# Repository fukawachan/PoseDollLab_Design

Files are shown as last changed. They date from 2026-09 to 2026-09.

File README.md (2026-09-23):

# PoseDoll 人偶硬件设计

Manny / Quinn 传感器可动人偶的独立设计仓库。原来位于 `DollSimulation` UE 工程中的硬件、固件与硬件诊断工具已经迁入本目录；UE 插件、角色资产与完整 Python 模拟器留在原项目。

## 当前状态

本次审查同时评估用户新明确的“摆稳后采集、无需实时动捕”场景：[放宽实时指标后的优化任务](Hardware/PoseDoll44/docs/NEXT_REVIEW_STATIC_CAPTURE.zh-CN.md)。Rev O3 当前代码与封存证据保留原时序，低频/触发式架构尚待审查实施。

- **当前推进为 Rev O 第三轮**：[本轮设计、验证与剩余问题](Hardware/PoseDoll44/docs/START_HERE_REVO3.zh-CN.md)。已实现一体板托、外耳钢背摩擦件和磨损状态检查；修正载荷/质量账、时序统计与节点恢复；生成顶入/侧入板件候选。**整机 1.2 kg 已改为非强制偏好**，尺寸、手感和精度要求保留。完整多轴总装与制造门槛尚未闭合。[第三轮审查入口](Hardware/PoseDoll44/docs/REVIEW_REQUEST_REVO3.zh-CN.md)。

- **历史检查点：Rev O 第二轮**：[本轮设计、验证与缺口](Hardware/PoseDoll44/docs/START_HERE_REVO2.zh-CN.md)。已重构 L6 承力/装配、生成 N3/N4 拆板候选并修复入网调度；完整板位、质量目标和物理门槛仍待闭合。**[给 GPT-6 Pro 的第二轮审查说明](Hardware/PoseDoll44/docs/REVIEW_REQUEST_REVO2.zh-CN.md)** 已整理好源码、证据和重点问题。下列 Rev O 审查入口保留为第一轮历史。

- **历史检查点：Rev O Desktop 初轮**：48 cm 为研究锚点，比较 42/45 cm 及较大后备档；已交付双角色布局、三档关节、原生电气布局和七角色固件。板位、预紧和质量预算仍未达标，完整总装尚未完成。
- **约 91 cm 的 Rev M/N1 为备用**：原文件与旧输出保留，以哈希清单冻结。新旧源码、报告和导出分目录保存。
- 第一轮历史入口：[Rev O 当前结果与失败清单](Hardware/PoseDoll44/docs/START_HERE_REVO.zh-CN.md)。
- **第一轮历史独立审查入口：[给 GPT-6 Pro 的审查说明](Hardware/PoseDoll44/docs/REVIEW_REQUEST_REVO.zh-CN.md)**，包含已知失败、证据链接与下一轮修改要求。

以下为备用版的历史基线：

- **机械基线为 Rev N1**：两款分别按 UE 人物参考比例设计，参考身高约 91 cm；胸前大挡板已取消，左肩局部刮碰已修正。
- **下一项为“局部采集 + 外置电源/USB 接口盒”**：方向已确定，新电路板、安装结构和线束尚未实施。
- **小型化仍待比较**：当前尺寸不是已证明的下限，不能直接缩放现有文件，也不能认定重新设计的小型关节必然昂贵。
- 44 个协议槽中，41 轴测量，骨盆 3 轴固定参考；整体位置和全部整体旋转在 UE 调整。
- 当前交付是数字原型候选，尚未实物鉴定。

## 阅读入口

0. [当前主方案 Rev O3](Hardware/PoseDoll44/docs/START_HERE_REVO3.zh-CN.md)；使用 `scripts/run_revo3.py --run-id <唯一编号>` 复跑，`scripts/Start-Viewer.ps1 -Revision revO3` 查看。以下 Rev M/N 文档用于备用版。

1. [最新 Rev N1 设计入口](Hardware/PoseDoll44/START_HERE_REVN.zh-CN.md)
2. [胸部修订与设备外置方案](Hardware/PoseDoll44/docs/CHEST_AND_EXTERNAL_REVN.zh-CN.md)
3. [尺寸、磁铁和关节小型化评估](Hardware/PoseDoll44/docs/SIZE_REVIEW_BEFORE_EXTERNAL.zh-CN.md)
4. [制造说明](Hardware/PoseDoll44/docs/FABRICATION_REVM.zh-CN.md)、[装配说明](Hardware/PoseDoll44/docs/ASSEMBLY_REVM.zh-CN.md)、[测试和校准](Hardware/PoseDoll44/docs/BUILD_AND_CALIBRATE_REVM.zh-CN.md)
5. [迁移记录和验证](docs/MIGRATION.zh-CN.md)

Rev M 文档描述原完整基线，使用时应应用 Rev N1 的取消件和左肩修订。更早版本与 `planning/` 是历史依据，不能混作当前制造说明。

## 目录组织

| 路径 | 用途 |
|---|---|
| `Hardware/PoseDoll44/cad/` | 参数化机械模型，保留当前模型仍引用的历史模块 |
| `Hardware/PoseDoll44/electronics/` | 原生 KiCad 工程、符号/封装及板级 STEP 输入 |
| `Hardware/PoseDoll44/mechanical_manifest/` | 轴、接口、比例和网络定义 |
| `Hardware/PoseDoll44/docs/`、`verification/` | 设计说明、数字检查和原型验收依据 |
| `Hardware/PoseDoll44/generated/` | 总装、打印件、查看器、交付清单和本地 CAD 缓存 |
| `Hardware/PoseDoll44/reference/`、`references/` | UE 参考数据及元件资料 |
| `Hardware/PoseDoll44/harness/` | 两款线束与下料表 |
| `Firmware/PoseDollFullBody/` | 六节点完整固件与主机端 C 核心测试 |
| `Firmware/PoseDollHardware/` | 早期单关节固件，历史用途 |
| `Tools/PoseDollHardwareBridge/` | 诊断、校准、数据转换和测试 |
| `Tools/PoseDollSimulator/`、`Shared/` | 硬件需要的协议/运动学代码及配置快照，不含模拟器 GUI |
| `planning/` | 原始规划包副本，父目录中的原下载包也保留 |
| `scripts/` | 独立仓库的检查、构建和查看器入口 |
| `.local/` | 本机迁移清单、运行结果等，不入 Git |

保留 `Hardware/`、`Firmware/`、`Tools/` 层级，以保持已有相对路径及历史资料的可追溯性。协议快照来源与逐文件哈希见 [software_snapshot.json](docs/software_snapshot.json)。

## 环境与离线检查

在本目录打开 PowerShell。本机已经建立独立 `.venv`；新克隆可执行：

```powershell
py -3.13 -m venv .venv
.\.venv\Scripts\python.exe -m pip install -r requirements.txt
.\.venv\Scripts\python.exe scripts/check_repository.py
.\scripts\Build-Design.ps1 -Stage OfflineTests
```

离线检查包括协议配置、Python 测试、C 核心测试和 C/Python 数据帧一致性；不连接硬件或操作 UE。C 测试需要 Visual Studio C 工具链，`-VcVars` 可指定 `vcvars64.bat`。本机迁移后结果为 **81 个 Python 测试、9 个 C 场景通过，数据帧逐字节一致**。

## 打开三维查看器

```powershell
.\scripts\Start-Viewer.ps1
```

默认根据 `verification/revO3/latest.json` 打开 Rev O3 查看器，当前为 `http://127.0.0.1:8874/generated/revO3/runs/o3_20260924_r3/review.html`；通过 `-Revision revN` 打开 91 cm 备用版，仅绑定本机。`-NoBrowser` 只启动服务；端口冲突时可用 `-Port` 指定另一端口，不会自动终止其他进程。

Rev O3 的当前及历史检查运行、HTML、网格、STEP、原生 KiCad 板件、固件产物与原始日志随本次审查提交收录；宿主 C 编译产物通过逐件哈希的 portable ZIP 保存。Rev O 第一轮的 HTML、轻量网格、布局数据及三档关节 STEP 也保留。十份体型布局 STEP 下载需先用 `Build-RevO.ps1 -Stage CAD` 重建。91 cm 备用查看器仍依赖未纳入 Git 的大型网格，需复制旧输出或重建。

## CAD、电路和固件

- CAD：CadQuery 2.7。现有 `Hardware/PoseDoll44/tools/run_cad.py` 可使用本机 CQ-editor 2.7 的环境，需要 CQ-editor 保持开启、Python 版本匹配；也可自行安装常规 CadQuery 环境。
- 电路：KiCad 10，打开 `electronics/` 中对应 `.kicad_pro`。搬迁前已打开的 CQ-editor/KiCad 文件，应从新目录重新打开，避免保存回原路径。
- 固件：ESP-IDF 6.1、ESP32-S3。旧构建缓存已保留，但含旧绝对路径；不要直接在其中增量构建。
- 布线工具：Freerouting 2.4.1 JAR 保留在本机 `Hardware/PoseDoll44/tools/vendor/`，不入 Git；许可证与说明保留。

```powershell
.\scripts\Build-Design.ps1 -Stage CAD
.\scripts\Build-Design.ps1 -Stage Firmware
```

CAD 阶段生成/复核 Rev M 完整基线，耗时较长。Rev N1 的修订脚本位于 `cad/revN/`，依赖 Rev M 完整输出及其复核结果，不是上述命令自动生成的另一套角色。当前源码与必要 CAD 输入纳入 Git。

新构建入口使用本仓库 `.venv`。Firmware 阶段会把检测到旧工程路径的节点缓存移入 `.local/legacy-firmware-builds/` 后重新构建，不删除缓存、不烧录。旧脚本中的 CQ-editor、KiCad、ESP-IDF 安装盘符仍是本机配置；换电脑须配置工具路径，历史工具可参考 `local_toolchain.example.json`。UE 参考重新导出需要原 UE 工程及插件，但导出脚本现在将数据写到本设计仓库。

## Git 与本地成果

Git 收录设计源码、KiCad 工程、固件、必要板级 STEP/角色参考输入、协议快照、说明、交付元数据和检查记录。`.gitattributes` 保留原行尾，避免检出时破坏来源文件的字节哈希。

大型总装 STEP、查看器大网格、CAD 缓存、ESP-IDF 构建目录、Python 环境和第三方工具二进制保留在磁盘，由 `.gitignore` 排除；没有启用 Git LFS。Rev O 审查快照额外收录三档单关节总成 STEP、两个 A 级配合样片 STEP/STL、轻量查看器与本轮原始编译/ERC/DRC 日志，Rev O3 本次另显式收录三个检查运行及其可追溯产物，仍未放开其他版本的整个生成目录。其他机器如需完整本地成果，应另外复制 `Hardware/PoseDoll44/generated/`。**推送 Git 不等于备份全部 6.87 GB 本地成果。**

现有验证报告保留为历史快照，迁移后的路径修复和检查另列记录；没有把迁移当成新一轮全身工程验证。本轮提交由使用者推送到远端；审查应指定 `design/revO-desktop-external` 分支和所读取的完整提交号。

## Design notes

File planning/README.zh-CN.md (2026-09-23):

# PoseDoll HW-44：硬件设计与 Codex 交接方案

版本：v0.1 / 2026-09-19。范围：完整 44 轴手动姿势人偶；分阶段制造、测试。

这是**工程设计任务书、接口约束和验收计划**，不是已经完成的 CAD、电路板、生产 BOM 或实测认证。文件中的尺寸、性能阈值、总线频率为待验证的设计目标。没有附上可直接投产的 STL、接线针脚图或 Gerber，避免把未经设计审查的文件误当成成品。

项目基线：`fukawachan/DollSimulation`，检查到的提交为 `7c22e075fe0efe295ce2935a8bb2a92cff0b6def`。本地继续开发前，必须检查用户当前分支与未提交修改，不能重置到这个提交。

## 阅读入口

先读 `CODEX_START_HERE.md`，然后读 `docs/HARDWARE_DESIGN.zh-CN.md`。具体软件衔接见 `docs/INTEGRATION_AND_PROTOCOL.zh-CN.md`；测试与每轮交付见 `docs/TEST_AND_RELEASE.zh-CN.md`；工具见 `docs/TOOLCHAIN.zh-CN.md`。

`contracts/axis_allocation.json` 已按照实际仓库的轴顺序分配完整 44 轴到六个区域节点。它**不是接线引脚表**；未定的针脚和实际关节限位明确为 null。

`tools/check_plan.py` 仅检查计划文件的内部一致性，也可以对本地仓库进行只读的轴顺序与基线哈希检查。其成功不代表机械强度、电路安全、传感器精度或 UE 新增硬件功能已经通过。

```powershell
python .\tools\check_plan.py
python .\tools\check_plan.py --repo "D:\YourProject\DollSimulation"
```

所有物理测试初始均为 `not_run`。先交付全身结构布局与第一轮少量试件，不直接采购全身电子元件，不自动提交 PCB 订单或启动打印机。

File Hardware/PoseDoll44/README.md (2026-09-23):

# PoseDoll Manny / Quinn hardware design

[Repository README](../../README.md) · [Rev N1 entry](START_HERE_REVN.zh-CN.md) · [Size review](docs/SIZE_REVIEW_BEFORE_EXTERNAL.zh-CN.md)

Current mechanical candidate: Rev N1 (Rev M full body, chest facade removed, left shoulder clearance corrected). Rear electronics remain integrated; local acquisition plus an external interface box is authorized but not implemented. Miniaturization feasibility and cost are unresolved.

CAD source: `cad/revM/final_model.py` plus `cad/revN/chest_clearance.py`. Historical revisions remain because current code and input provenance refer to them. Use revision manifests rather than mixing standalone exports.

This is a digital prototype candidate, not a manufacturing release or a physically qualified product. See the repository README for the migrated layout, toolchain, ignored local exports, offline checks and viewer startup.

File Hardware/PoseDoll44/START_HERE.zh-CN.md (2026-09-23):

# PoseDoll · Manny / Quinn 完整硬件设计

> **最新增量：** [Rev N1](START_HERE_REVN.zh-CN.md) 已取消胸口罩壳及其四个紧固件、修正左肩支座局部刮碰，并完成背部外置架构评估。下文为原 Rev M 配套资料，制造时以 N1 清单剔除取消件并替换左肩支座图纸；背部外置尚未实施。

当前交付是 **Rev M 完整数字原型候选**：两款角色各自的 1:2 关节比例、41 个相对测量轴、被动持姿机构、局部可拆外壳、电子仓、四种电路板、六节点固件及线束/校准文件。

**先打开 [完整人偶三维查看页](generated/revM/RevM_Full_Body_Review.html)**。若在浏览器查看，使用 [当前本地服务](http://127.0.0.1:8874/generated/revM/RevM_Full_Body_Review.html)。页面可切换 Manny / Quinn、站/坐与检查姿态、外壳、电子仓、线束固定点，并点击具体零件下载 STEP。

如果本地服务链接打不开，双击 [Open-Viewer.cmd](Open-Viewer.cmd)。它会在后台启动仅本机可访问的服务并打开页面；重启电脑后再次双击即可。不要直接双击 HTML，模型数据需要通过本地 HTTP 服务读取。

目前不需要你打印、采购、量尺寸或接线。完整设计先供复核；实物按“一个高负载关节 → 单传感器/区域板 → 单肢 → 一款整机 → 另一款”的顺序验证。数字检查与尚需补齐的证据集中在 [最终验证报告](verification/REVM_REPORT.zh-CN.md)。

## 确定的使用方式

- 两款都来自项目中的 Manny / Quinn 参考骨架与网格比例。参考高度分别约 907.93 / 907.70 mm；这是 1:2 人物参考高度，机械外壳包络不宣称逐点复制人体表面。
- 稳定躯段包壳，肩带、腰髋、肘膝、腕颈等活动区域裸露。大腿后侧、小腿后上段等压缩区留空；外壳不跨越这些运动区。
- 人偶不含固定外部支架；摆好姿势后使用外部承托，支撑物本轮不设计。
- 骨盆前方定义人偶前方。UE 中调整全部整体位置和转动；整个人偶平躺不会自动让 UE 角色平躺。相对弯腰、抬腿等动作仍由关节测量。
- 协议保留 44 个槽位，骨盆三轴明确 `fixed`、原始值为空；其余 41 轴测量。没有 IMU，不把缺失传感器伪装成零度。
- 非相邻部位接触保留为摆姿限制；同体或相邻结构穿插仍作为设计问题检查。

## 交付文件

| 内容 | Manny | Quinn |
|---|---|---|
| 整机总装 | [STEP](generated/revM/manny/Manny_RevM_assembly.step) | [STEP](generated/revM/quinn/Quinn_RevM_assembly.step) |
| 逐件 CAD / 工艺清单 | [清单 JSON](generated/revM/manny/manufacturing_manifest.json) | [清单 JSON](generated/revM/quinn/manufacturing_manifest.json) |
| 打印候选 | [187 件 STL](generated/revM/manny/print_candidates) | [187 件 STL](generated/revM/quinn/print_candidates) |
| 加工与采购分类 | [CSV](generated/revM/manny/procurement_routes.csv) | [CSV](generated/revM/quinn/procurement_routes.csv) |
| 线束裁线 / 端子表 | [CSV](harness/manny_cut_list_revM.csv) | [CSV](harness/quinn_cut_list_revM.csv) |
| 41 轴校准参考工单 | [CSV，未测](generated/revM/manny/calibration_reference_plan.csv) | [CSV，未测](generated/revM/quinn/calibration_reference_plan.csv) |

打印 STL 已做闭合性检查；每款 6 个零件另附小圆筋修正后的 `_print_process.step`，与名义总装的区别见制造说明，打印直接使用交付 STL。

两款各 1,999 个 CAD 实体，包含电子元件和重复螺丝，不代表 1,999 种采购件。每款电子部分为 **39 块小传感器板 + 2 块肩外展板 + 6 块区域板 + 1 块电源板**。加工/采购分类表把焊接元件归入 PCBA，不重复采购。

- [39 块小传感器板 KiCad](generated/revM/electronics/sensor_revM_side/PoseDoll_AS5048A_revM_side.kicad_pro)
- [2 块肩外展传感器板 KiCad](generated/revM/electronics/sensor_revM_large_sh/PoseDoll_AS5048A_revM_large_sh.kicad_pro)
- [区域板 KiCad](generated/revM/electronics/regional_revM/PoseDoll_PD41_Regional_revM.kicad_pro)
- [电源板 KiCad](generated/revM/electronics/power_revM/PoseDoll_PD41_Power_revM.kicad_pro)
- [六节点固件镜像](generated/revM/firmware) · [固件源码](../../Firmware/PoseDollFullBody)
- [腰关节 STEP](generated/revM/assembly_details/waist_pitch_assembly.step) · [拆解分组图](generated/revM/assembly_details/waist_pitch_exploded.png)
- [肘关节 STEP](generated/revM/assembly_details/elbow_l_flex_assembly.step) · [拆解分组图](generated/revM/assembly_details/elbow_l_flex_exploded.png)

## 按什么顺序阅读

1. [装配说明](docs/ASSEMBLY_REVM.zh-CN.md)：哪些交给加工方预装、你如何连接全身。
2. [制造、公差与打印](docs/FABRICATION_REVM.zh-CN.md)：0.4 mm + PLA、A1 mini 长梁斜放、金属关节与电路板工艺。
3. [线束与电源](docs/WIRING_REVM.zh-CN.md)：41 条传感器线、5 条 CAN 线、6 条电源线，插头与针序。
4. [受力与操作阻力](docs/LOAD_AND_HANDLING_REVM.zh-CN.md)：约 3.2 kg 量级，纸面保持能力与真实手感的区别。
5. [构建、测试和校准](docs/BUILD_AND_CALIBRATE_REVM.zh-CN.md)：离线工具、实物阶段和 UE 接入边界。

## 当前边界

这是完整整机范围的数字设计候选，**没有制造放行或实物鉴定**。精密轴系、摩擦片、弹簧预装和 PCBA 需要加工/贴片方完成，不能只靠打印机做出全部部件。制造 DFM、材料/螺纹强度、实际磁场、持姿/手感、线束耐久和电源/信号波形仍需要首件确认。

颈部与躯干采用等效转轴，运动轨迹不是逐点复刻 UE 的多骨骼脊柱/颈椎。最终离线样本的头部最大位置差异约 14.3 / 16.5 mm（Manny / Quinn）；四肢骨长比例一致，精确贴合身体的接触姿势仍需适配/IK 评估。详见 [轨迹差异记录](verification/revM_kinematic_mapping.json)。

UE 插件和模拟器原先已由用户测试通过。本轮新增的是硬件固件、诊断与离线校准转换；未连接当前 UE 会话或真实设备，未验证 Quinn 独立 Control Rig 绑定及真实硬件实时捕获。不存在已经测好的实体零点文件。

当前 CAD 入口为 [final_model.py](cad/revM/final_model.py)，重建脚本为 [Build-RevM.ps1](tools/Build-RevM.ps1)。最终文件哈希与检查匹配关系见 [交付清单](generated/revM/delivery_manifest.json)。Rev A～L 和其他 `*_work` 文件保留为历史，不作为当前打印或采购入口。

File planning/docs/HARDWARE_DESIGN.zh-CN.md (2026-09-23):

# PoseDoll HW-44 完整硬件设计任务书

状态：架构基线，未完成制造设计。下文的“必须”是实现约束，“目标”是待验证验收指标，“候选”不等于批准采购。资料出处见 `SOURCES.md`。

## 1. 产品边界与基本决策

设备是手动摆姿势的输入装置，不是机器人。全部关节由手掰动，依靠被动摩擦保持姿势；无电机、无电池、无无线。电脑通过 USB 接收数据，并继续使用已实现的 UE / Control Rig 工作流。

按完整 44 旋转轴设计：骨盆支架 3、腰 3、胸 3、颈头 3；左右肩带各 2、肩各 3、肘各 1、前臂扭转各 1、腕各 2；左右髋各 3、膝各 1、踝各 2、前脚掌各 1。合计 12 + 18 + 14 = 44。手指、面部和场景整体六自由度不纳入本版。轴 ID 和顺序以现有仓库为准，不按物理线束顺序重排。[R1–R4]

参考整机高度暂定约 500 mm，允许全身装配布局论证后调整。它不是比例精确的收藏人偶，而是便于抓握、维修的桌面工具。不要为了达到小巧外形而隐藏无法插拔的接头、压缩磁铁间距或让打印件承担不合理的预紧力。

支架采用稳定的桌夹/金属立柱承载方案，人偶与支架之间的骨盆三轴属于被测运动。支架中其余可调机构使用时须锁死，改变后要重新建立安装参考。第一版不要求脚部独立承重站立；不允许据此省略踝、膝、髋的姿势保持能力，也不把它宣传为自由空间位置追踪设备。

整个人偶在桌上移动，44 路关节读数不一定变化，所以场景 Placement 仍由软件管理。必须在界面和说明书明确这一区别。

## 2. 既有软件不是制造图纸

仓库的 `virtual_humanoid_44_v1.json` 明确标记为软件运动学参考，三轴关节大多共点，尺寸与限位是软件假设。实际关节轴间距、安装倾角、磁铁座、传感器板厚和壳体都会改变实体结构。[R3]

硬件新增 `physical_humanoid_44_revA.json`（拟议名称），保持现有 44 轴语义、轴顺序和 20 段人体锚点。实体中间固定连接节点可按真实需要增加，不能为维持“54”这个数字省略真实偏移；任何额外节点都必须经过现有 UE 解析和映射回归验证。

所有实际轴的原点、方向、父子关系和前后刚性偏移，由同一份机械参数生成。CAD 建模以 mm 为单位，profile 导出显式换算到 m。不得在 CAD 里移动一个支架，却手动忘记修改 JSON；不得把物理轴角直接写成 UE Pitch/Yaw/Roll。

现有左右镜像规则要重新验证实体装配。镜像零件不能只翻转 STL 后默认编码器正向相同。每个轴都应有“人偶自身左右、正方向箭头、轴编号”，并由单轴实测确认。

## 3. 三类可更换关节，而非 44 种独立机构

制定 S/M/L 三类结构族，分别覆盖轻载末端、中等负载四肢、躯干与支架等场合。但结构族归属必须由负载预算决定，不能假定所有膝关节一定与肘关节同规格。共用传感器模块与接口，关节壳体、轴径、摩擦半径和弹性预紧件可以不同。

一个单轴关节分成四部分：承重轴系、可调摩擦组件、测角组件、机械限位及线束保护。建议采用双侧支撑的叉形铰接；金属轴/肩螺栓与可替换轴套承担转动，非打印螺纹直接摩擦。打印壳体负责定位和连接，不让电路板或磁铁承担外部扭矩。

摩擦组件可采用可替换摩擦垫、金属推力垫片、弹簧预紧件和防松结构。初始装配时调阻力，日常摆姿势不需要每次拧紧螺丝。预紧力应尽可能通过金属限位套/垫片形成受控载荷路径，而不是长期压缩一段薄打印塑料。承重和摩擦组件的受力路径须画剖面并审查，避免“为了拧紧摩擦片，把旋转轴彻底夹死”。

传感器位于固定侧，磁铁由随轴旋转的机械座带动，磁铁与转动零件之间不得打滑。用有方向定位的嵌槽和机械盖板保持磁铁；胶黏只能辅助，不能是唯一防脱结构。承重螺丝和钢轴不能未经验证穿过敏感磁路。磁铁区附近紧固件的材料和位置必须计入磁干扰试验。

给每个模块保留可拆维护盖、插头拔出空间、替换传感器的路径和防夹手间隙。不得依赖装配后必须用刀切开的外壳，也不要求用户铰孔、攻牙、切钢轴或焊细脚芯片；确实需要这些工序时，应改设计或在供应商处完成。

## 4. 持姿扭矩、操作力与整机稳定性

每根关节从完整装配模型计算下游质量和重心；质量要包括电路板、磁铁、金属件、线束和壳体，不能只用空心连杆的质量。第一轮估算可以采用保守质量，实测称重后回写。

重力扭矩按 `Tg = sum(m_i * g * horizontal_lever_i)` 估算；目标保持扭矩至少覆盖最不利姿势重力扭矩的 1.5 倍。这个系数只是设计起点，不是强度认证或证明用户可以施加任意外力。线束恢复力矩另计。

例：下游总质量 0.12 kg，等效力臂 0.10 m，重力扭矩约 0.118 N·m，1.5 倍约 0.177 N·m。若手指在 25 mm 的有效力臂处推动，单按 0.177 N·m 计算就需约 7.1 N。由此同时检查“能撑住”和“好掰动”，不能单纯把摩擦越调越紧。

支架需检查人偶偏载及用户掰动时的倾覆力矩。默认优先使用额定承载和接口可核实的金属桌夹/立柱，不把“打印一个底盘”当作已经解决防倒。桌面材料、厚度、夹持位置和保护垫列入装配前检查。禁止靠用户手一直扶住底座才能完成日常操作。

静力估算、CAD 干涉检查和有限元分析的用途不同。FDM 打印方向、层间强度、长期变形和摩擦性能需要实物验证；没有材料和工艺实测参数时，有限元结果只能用于比较设计，不得输出虚假的精确寿命或安全系数结论。

## 5. 三轴关节与全身运动空间

肩、髋、躯干等使用可测量的串联转轴，优先保持现有 profile 的旋转顺序。实际转轴不必完全共点，真实偏移必须被建模。采用普通球关节却只测一根轴，不满足要求；用算法“猜”另外两个方向也不满足。

三轴串联结构有真实的姿态可操作性问题：部分姿态中两根轴可能趋于重合，局部转动的操作会变差。把数值改成四元数不能消除实体机构的这一问题。H0/H2 必须检查手臂外展接近水平、双手举高、叉腰、抱臂、扶额、头侧倾、髋部外展、蹲坐等关键姿态，并比较可动范围与抓握空间。

软件参考角度范围只是需求起点。最终允许范围取机械碰撞、线束弯曲、磁场有效区和人体姿势需求的共同约束。物理硬限位要先于线束受拉和磁铁/PCB碰撞；软件限位在实际硬限位内保留测量裕量。不能机械到不了却在 profile 中保留虚假范围，也不能私自删掉关键姿势使测试变绿。

不要承诺“全身所有轴都到最大角度时仍无碰撞”。这通常不是合理需求。交付一个明确的关键姿势集及随机采样检查；对不可达姿势列出具体阻挡零件、角度和可能的改进。

肩带两轴与肩三轴分开；前臂轴向旋转与手腕两轴分开；前脚掌单独一轴。上臂/大腿扭转模块可做成沿肢体方向的轴承式旋转组件，而不是在肢体侧面无限堆叠同一种铰链。

## 6. 传感器基线：AS5048A 绝对式磁编码器

选 AS5048A 作为首轮技术候选，使用 SPI 读取绝对角度。厂家资料给出每圈 16384 个位置，即 14 位；约 0.022° 只是计数间隔，不能当作整个人偶实际精度。采购时核对确切后缀、封装、资料版本、库存和模块电路；AS5048A 与 AS5048B 不得无审查互换。[S4]

测量方案是每根轴一颗传感器、一枚配套双极径向充磁磁铁。不是随便买轴向充磁的圆片磁铁。传感器、磁铁和载荷件分别装在可定位结构上；电路板位置要能校正装配偏差，但调整后必须可靠固定。

数据手册中的磁铁尺寸、场强和气隙是匹配条件，不能只照抄某个固定距离。初步使用约 6×3 mm 配套径向磁铁研究；实际磁铁供应商参数、同心度、安装高度和全程诊断结果决定最终结构。采用定位台阶、垫片规格与间隙检查夹具，不能让用户靠肉眼“调到差不多”。[S5]

密集多轴机构的磁场验证优先级很高：固定待测关节，转动邻近所有磁铁；再把手靠近头、抱臂、屈腿让不相邻关节在空间上接近。观察角度是否被带动、诊断是否超限。单个模块正常不能证明整机正常。厂家抗杂散磁场描述不能替代近距离、非均匀磁场的验证。

不能仅用一张全身静态校准表掩盖这种串扰，因为干扰可能随另一个关节角度变化。先调整磁铁间距、方向和安装位置；必要时换传感器或局部测量结构，再经过设计变更评审。

读取固件必须按实际数据手册处理 SPI 回包时序、奇偶校验、错误位和磁场诊断。某些故障下芯片可能保持上次角度，故“读到合法整数”不等于传感器健康。低层错误必须进入样本状态，不能把旧值包装成新的正常读数。[S5]

芯片的零位设置保持明确可追踪，优先软件校准；不要烧写 OTP。若购买的模块有预设零位或不明改动，先读回确认再入库，不把差异隐藏起来。

## 7. 电子架构：六个区域节点 + 一个 USB 网关

完整系统按以下固定分区设计：

| 节点 | 覆盖部位 | 实测轴数 |
|---|---|---:|
| N1 | 骨盆支架、腰 | 6 |
| N2 | 胸、颈头 | 6 |
| N3 | 左肩带、左臂、左腕 | 9 |
| N4 | 右肩带、右臂、右腕 | 9 |
| N5 | 左髋、腿、脚 | 7 |
| N6 | 右髋、腿、脚 | 7 |

区域采集板尽量复用同一设计，预留 10 个传感器端口，角色由配置决定。不是每个关节都放一块 ESP32 开发板，也不是把 44 路长线全部拉到底座的一块实验板。正式版应是小型区域 PCB；大开发板仅用于台架验证。

候选 MCU 为 ESP32-S3，使用同一套固件代码的 node/gateway 两种角色。其 TWAI 需要外部 CAN 收发器，且使用经典 CAN，不能误用 CAN-FD 帧。[S6] 选择 3.3 V 逻辑兼容的收发器，电源、待机脚、终端和保护器件都必须有明确电路，不能把开发板 TX/RX 直接接 CANH/CANL。

区域内采用低速起步的 SPI、独立 CS 选通。初始时钟目标 250 kHz，但降低频率不等于解决走线电容或边沿反射。电路设计必须计算驱动负载，核查最长传感器线、连接器和多模块并联的总电容；根据结果采用分组、缓冲、源端阻尼或端口 MISO 隔离。不得把“最多十个口”实现成未经验证的长线被动星形 SPI 排线。

局部线长以尽量短为目标；约 200–250 mm 是全身布局时的初步约束，不是接口标准保证距离。若到手腕/脚的线路超出合格范围，应调整节点位置或端口电路，而不是随意增加延时后宣布可靠。共享 MISO 被一颗坏模块拉死时，可能影响整组；软件必须诚实标出整个受影响组故障。

区域之间采用 500 kbit/s 的线性 CAN 干线。只在干线两端设置终端电阻，分支尽量短；各节点配置、末端位置与终端开关有标记。人偶外形有分叉不等于电气上允许把 CAN 做成五叉被动星形。CAD 和线束图应画清沿各模块串行经过/返回的干线路径；电源分配可以另行设计，不能因为供电星形就把信号也直接并成星形。

这一分布式设计增加了少量板卡和固件工作，换取可拆换区域和较短的传感器线。它是本版的工程取舍，不宣称是所有人偶的最低成本解。

## 8. 供电、插头和适合新手的制造方式

采用合规的成品低压外接电源；不让用户接触市电内部。供电基线为 5 V 分配、区域内生成需要的电压，实际额定电流在完整预算后确定。仅按数据手册每颗传感器最大 15 mA 计算，44 颗就达到 660 mA，还未包括 MCU、收发器和转换损耗，故不能假设电脑一个 USB 口或开发板小 LDO 能包办整机。[S5]

功耗表必须包含最坏静态/启动负载、稳压器压差和温升、最长线压降、接插件电流、浪涌、各区域短路及总保护。USB 连接的供电路径要防反灌，不能把 PC USB 5V 和外接 5V 随手并联。节点电源关闭时，信号脚不得通过保护二极管反向供电；有源缓冲、端口保护与上电顺序都要核对。

电子件分三个可复用层次：传感器小板、区域采集板、网关/配电板。第一轮用确切可核实的预焊模块验证；正式小板需要时采用 PCB 制造加贴装服务。用户收到的应是已焊好关键元件和连接器的板子，而不只是一张裸 PCB。不要让用户购买裸芯片后临时学习表面贴装。

所有线束使用防反插、有锁扣、规格明确的连接器与成品/代工线。确定实际型号后统一针脚和线色，再输出从插接面观察的图。不能仅写“接 3.3V/GND”或者依赖廉价模块丝印和杜邦线颜色猜方向。防反插也不能替代电气保护。

每根线束要有两端标识、长度、端子料号、针脚视图、弯曲余量、固定位置和应力释放。关节转动时让线束弯曲而不是在焊点处扭拧；不采用无限旋转关节，本版无需滑环。模块拔插默认断电进行，除非以后专门设计并验证热插拔。

可在底座预留采集/冻结按钮，按钮走独立命令通道，不占用 44 轴，也不通过任意 MCP 指令执行编辑器动作。按钮功能后置，不阻塞主体测角链路。

## 9. A1 mini 打印策略

A1 mini 官方标称成型空间为 180×180×180 mm，适用于 PLA/PETG 等无需高温腔体的材料。[S1] 本项目暂按单件优选包络 160×160×160 mm 设计，实际切片仍须计入裙边、支撑与设备禁入区。人偶整体约 500 mm 不意味着要一次打印 500 mm。

先用普通 PLA 做尺寸与装配试片，再对受力壳体评估 PETG；每类材料都要重新验证配合和保持力。材料名字不是耐久保证，摩擦面也不默认使用同种打印塑料互相磨。薄弱部件优先通过金属轴、套、垫片、合理壁厚和打印方向解决，而不是立即升级打印机。

正式零件必须带装配方向、层纹方向建议和关键尺寸。孔径补偿来自试片，不给所有孔统一增加某个数。不得把光孔、压入轴套孔、嵌入螺母位、滑动配合孔当成同一公差类别。对需要精度的孔和面，避免在内部不可清除支撑处成型。

不提供跨材料通用的喷嘴温度、速度或“固定墙数即可承重”的承诺。先用用户已安装的 A1 mini 与具体材料配置切片，记录喷嘴、层高、墙数、填充和方向，按试验修改。由用户确认首层和切片预览后启动；不远程自动开机打印。

现阶段无购买新打印机的理由。只有当已量化的关键结构需要更高温材料、尺寸或工艺时才出升级需求报告；也可以先外包少量金属/尼龙关键件，而不是更换整台机器。

## 10. CAD、电子设计与软件必须同步版本

为每个模块定义机械版本、PCB 版本、固件版本和校准记录。机械装配序号到区域端口、轴 ID 的映射由 manifest 生成；更换板子或磁铁后只重新验证相关模块及上游影响，不要求随意给整机重新归零。

交付物不只 STL：必须有可编辑的参数化源、STEP 装配、BOM、爆炸图、关键尺寸图、线束图、固件源和二进制、配置与哈希、校准夹具、测试脚本和原始结果。机械变更可能改变 profile；电子零点变更可能改变 calibration，两者不能混为一份无版本的“设置”。

预算必须逐阶段审批。每次列出当前试验实际需要购买的数量、备件、代工费用、工具费用和总额，不能把完整 44 轴的猜测单价乘起来当成可靠成本。未核实到确切产品的组件只能列为候选，不批准整机批量采购。

最早的高风险验证是：一个能保持负载且轻松掰动的标准关节，以及一个真实紧凑三轴组件在所有邻近磁铁运动时仍可准确测角。这两件通过后再放量复制模块。完整架构先设计，不等于全部零件先买齐。

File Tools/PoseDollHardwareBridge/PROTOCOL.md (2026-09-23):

# PDH1 diagnostic wire format v1

This is a separate single-real-axis instrument protocol. It is not the production HW44 USB/cohort protocol and does not connect to the UE pose TCP port.

ESP32-S3 native USB Serial/JTAG carries COBS(payload + CRC32) followed by one zero byte. All integers are little endian. Decoded size is exactly 60 bytes; payload size field is 56, excluding the CRC. CRC32 is IEEE/zlib over the first 56 bytes (init FFFFFFFF, reflected polynomial EDB88320, final xor FFFFFFFF).

| Offset | Bytes | Meaning |
|---:|---:|---|
| 0 | 4 | ASCII PDH1 |
| 4 | 1 | Version 1 |
| 5 | 1 | Message type 1 |
| 6 | 2 | Payload length 56 |
| 8 | 8 | Device ID from read-only eFuse base MAC |
| 16 | 8 | Per-boot random session ID |
| 24 | 8 | Increasing sequence, starts at 1 |
| 32 | 8 | Sender monotonic microseconds at start of register reads |
| 40 | 4 | Elapsed register-read window in microseconds |
| 44 | 2 | Axis index 17 (elbow_l.flex, diagnostic assignment) |
| 46 | 2 | Count 0..16383 when flags=0; wire value 0 otherwise |
| 48 | 2 | AS5048A diagnostic/AGC register |
| 50 | 2 | Magnitude |
| 52 | 2 | Combined zero-position register value |
| 54 | 2 | Flags |
| 56 | 4 | CRC32 |

Flags: bit0 SPI I/O, bit1 parity, bit2 sensor EF, bit3 missing OCF or COF/CompLow/CompHigh, bit4 nonzero zero-register setting. Other flags are rejected. An invalid count becomes null in host JSON, never a valid zero reading.

Read window describes SPI register reads, not the exact internal ADC acquisition timestamp. Diagnostic/magnitude/angle registers are sequential, not a simultaneous full-body cohort.

The host rejects unsupported versions, malformed frames, impossible health combinations, CRC failures, wrong axis IDs, duplicate/backward sequence/time, and device/session changes without reconnect. Oversize encoded frames are discarded to the next delimiter. A recorded file is not overwritten. Transport exceptions preserve bytes and accepted records collected before the exception.

The host only converts counts to raw degrees for inspection and circular statistics. It does not apply mechanical zero, sign, filters, or UE FK. Firmware only issues reads (including read-to-clear); it never writes sensor OTP. Future full-body firmware needs separate identity, capabilities, epoch assembly, bus fault handling and physical calibration ownership.

Run unit tests from the repository root:
~~~
python -m unittest discover -s Tools/PoseDollHardwareBridge -p "test_*.py" -v
~~~
Tests use synthetic packets explicitly; they do not qualify physical hardware.

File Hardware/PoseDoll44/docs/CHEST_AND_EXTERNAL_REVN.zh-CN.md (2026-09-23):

# 胸口减遮挡与背部设备外置评估 · Rev N1

结论：**胸部大罩壳取消；电子架构推荐向“本地小采集节点 + 外置电源/USB 网关”改造。** 现有六块大板直接全部移到桌面不推荐。胸壳删件已经形成两款 CAD 修订；外置部分在本次交付中是工程评估，尚未生成新采集板、外置盒、接口或改版线束，不作为制造文件。

## 胸部已经落实的修改

删除 `chest_M_front_shell`、两颗 `chest_shell_M2x20_*` 螺钉及两颗 `chest_shell_nut_M2_*` 螺母，共 5 个实体。前方立柱属于头颈承重路径，保留；原立柱上的两个一体安装凸台也保留，避免把取消罩壳扩展为未经验证的承重结构切削。没有缩短骨骼、移动关节中心或改变磁铁与传感器。

两款各剩 1,994 个 CAD 实体、186 个打印候选。另修正 `l_abduct_ring_and_twist_seat` 左肩金属支座：在轴承和摩擦区外增加一处局部让位，去除约 0.635 mm³ 材料，保留半径 9.5 mm 内受力区域和原止挡角度。这修复了新增背手样本暴露的旋转限位拨片刮碰；不是把这组接触改成允许。制造时使用 N1 的左肩支座 STEP，其它 STEP/STL 沿用 Rev M 已核验文件（含既有打印工艺修正）。打印件只需剔除胸壳；未实际打印的用户无需做任何拆装。

| 复核项 | Manny | Quinn |
|---|---:|---:|
| 左肩支座局部去除体积（mm³） | 0.635 | 0.635 |
| 原 164 姿态中接触减少的姿态数 | 9 | 12 |
| 取消的接触对次数（跨姿态累计） | 77 | 142 |
| 原 164 姿态剩余接触对次数 | 3052 | 2340 |
| 原版完全无接触姿态数 | 122 | 115 |
| 新版完全无接触姿态数 | 127 | 123 |
| 本次减重（g） | 30.98 | 28.57 |
| 含原线束预留估重（kg） | 3.200 | 3.158 |
| 重新计算的最小名义持姿比 | 1.579 | 1.641 |
| 新增背手姿态仍有的背部设备接触对 | 121 | 47 |

胸壳取消后，有些抱臂姿态仍会与前方承重梁或另一只手臂接触；不能解释为全部抱臂姿态都已通过。新增“低位双手背后”是关节范围内的运动学候选，整机 BRep 检查仍显示背部设备遮挡，因此不将它标为可直接实现的无碰撞动作。背手样本的腕部目标以骨盆为参考，Manny 与 Quinn 分别搜索关节角度；它们不是完全相同角度的横向比较，不能按接触对数量给两款人物的可动性排名。

验证方法：核对 Rev M 几何输入哈希、所有未改实体形状对象/所属节段/材质及运动树。取消的零件直接从旧接触表移除；未改实体之间继承原精确结果。修改的左肩支座与整机各件的接触在原 164 姿态及新增背手姿态全部重新求交，仍按同一区域/相邻机构的严格规则分类，未发现结构项。左右肩的固定支座/旋转限位拨片这一对零件，另外从 -90° 到 +90° 每隔 1° 检查，并核对两端越界 1° 会接触止挡；右肩无需修改。它是加密离散检查，不宣称连续全空间证明。

原始失败记录保留在 [Manny 首次背手检查](../verification/revN_behind_initial_manny.json) 和 [坐标系交叉核对](../verification/revN_twist_contact_precision.json)：原左肩在 30°、45° 分别约 0.035 / 0.194 mm³ 穿插，局部坐标与世界坐标结果一致。修正记录见 [肩轴逐度复核](../verification/revN_guard_relief.json)。骨长、旋转中心、磁铁和传感器没有移动；39 轴旧限位和原 164 组测角记录继承，肩扭转两轴限位改为新记录。重力/持姿预算重新计算了 191 姿态，摩擦、材料和线束恢复力仍待实测。原 164 姿态的打印工艺小圆筋检查可随减材/删件继承；新增背手样本检查的是名义 CAD，未另外叠加旧打印工艺变体求交，不把该样本写成可制造、无接触的背手姿态。

## 背部为什么这么大

Rev M 背部是六个 36 × 44 × 100 mm 的区域电子仓及额外电源仓；区域 PCB 为 40 × 86 mm。零件质量估算合计约 539.7 g，其中 PCB/已焊组件预算 170 g、打印壳约 293.6 g，其余是支架和紧固件。躯干一体式背部延长梁及导线未算入这 539.7 g；它不是外置后必然减去的质量，小采集板、保护壳和接口仍需留在人偶内。

目前每个角度传感器用 6 芯线独立接区域板。保持现有 41 路布线不变而把六个节点都搬走，会引出 **246 根绝缘芯线**。以当前 0.61 mm 导线外径、60% 截面填充率作几何估算，成束内径约 12.35 mm，尚未计护套、屏蔽和接头；这不是推荐电缆规格。共享导线、串联传感器或差分 SPI 能减少/改变布线，但都会改变电路和通信，不能把这个问题当作“USB 线加长”。

| 方案 | 得到的好处 | 主要代价 | 判断 |
|---|---|---|---|
| 保留现有六个背包 | PCB、固件、接口沿用 | 背手、后收肩和深屈膝等继续受盒子影响 | 可作对照原型，不符合最终摆姿优先目标 |
| 六块区域板全部放桌面，现有传感器线直接延长 | 背部电子仓清空，板子好维护 | 大束拖线、多个弯曲跨关节段、长线 SPI 完整性、接头体积 | 直接照搬弊大于利，不采用 |
| 本地小采集节点 + 外置电源和 USB 网关 | 避免长距离传感器原始线，可集中到一根复合线；背包可取消 | 要重做小 PCB、壳内安装、CAN 拓扑和网关职责，仍有外接线牵引 | 推荐的下一版架构 |

## 推荐架构的具体边界

```text
电脑 ── 标准 USB ── 桌面接口盒 ← 低压电源适配器
                         │
                 一根柔性数据/供电复合线
                         │
                 胯部固定骨架上的凹入式接口
                         │
        人偶内部 CAN + 电源干线（线性 CAN，不作星形支线）
                         │
     六区小采集板 ── 较短的本地传感器线 ── 41 个关节
```

1. **人偶内保留传感器及就近采集/总线转换。** 初选仍用六区域逻辑分区；局部电路板需要重新紧凑布置。现有 40 × 86 mm 板不能直接宣称已塞入四肢罩壳，尚未做可装配布局。优先使用稳定胸腹空间与既有四肢刚性节段内部，禁止改成前胸或体侧的另一组大包。六个背包、其载架及仅为电子仓增加的后伸挂架要一并取消/重做；不能留下同样挡手的空挂架，也不能误删肩颈或脊柱的真正传力构件。
2. **桌面盒负责 USB 接口、采集批次汇总和外部供电保护。** 现有 N1 同时测量三腰轴并做网关；不能直接搬走 N1 后丢掉腰部输入。改版应保留人偶内 N1 的三测量槽，把网关功能拆为无测量通道的 G0；原 44 槽、41 测量与骨盆 3 固定槽保持不变。固件和 Python 绑定要相应改，当前 Rev M 镜像不适用于这种新拓扑。 网关移出后，N1 的三腰轴也需经 CAN 传输。按现有每帧两个角度分组估算，六节点合计 23 个数据帧 + 6 个 END + 1 个 SYNC；60 Hz、每帧保守 135 bit、500 kbit/s 下约占 48.6%，尚未计启动、诊断和重传。需要重新验证采集窗口，不能直接沿用原 43.7% 预算。
3. **人偶到桌面盒用 CAN 差分对 + 电源正负两芯的复合连接。** 它不是 USB 协议，不借用普通 USB 插头传自定义电压；PC 到桌面盒才用标准 USB。CAN 只在线性总线两端各端接一次，网关成为端点时必须重排原 N6/N4 端接，不能简单增加第三个电阻。 单对电源进入人偶后再分为六个支路，分区限流/保险必须放在本地节点或内部的小分配板上；不能把原六路电源板搬到外部后，假定一对电源线仍保留六路独立保护。该分配和保护电路也计入人偶内保留的电子部件。
4. **接口优先在骨盆侧方的凹入位置，线束沿固定骨架向下离开。** 低矮弯头、可拔下接头、真正的应力释放一并设计；最终左右位置需由背手、叉腰、坐姿、俯卧与侧卧的完整插头包络决定。线从任何单一位置出来都不能保证所有姿势完全无妨碍，因此不承诺“外置后零影响”。
5. **初始拖线目标为 1 m，可替换。** 线径、弯曲刚度、护套和拉力都是验收项，不把拖线重量当作由桌面完全承担。5 V 总线直接拉长会消耗供电余量；需要比较加粗电源芯线与升高低压干线再本地降压。12 V 只是待整板审核的候选，不能把当前标 5 V 的成板接到 12 V。TPS62162 芯片支持较宽输入范围，不代表其外围元件、保护电路、接口和旧 PCB 都已按新电压合格。

还有一个电路改动较少的备选：N1 继续兼任 USB 网关，桌面盒只负责电源与对外接口，采用 USB 与电源双线或经专门设计的复合线。这样无需 G0 和新增 CAN 数据组，但要处理 USB 线对、主机 VBUS 检测与外部供电隔离。此备选同样能取消背包，关键仍是小板布局；推荐 G0 方案的理由是让人偶拖线只承载 CAN 与电源，并非“不外置网关就无法消除背包”。

## 改版需要通过的检查

先完成六个采集区真实零件/插头/固定件的装配布局，再设计 PCB 与外置盒，最后同时核对数据完整性和全身动作。动作清单增加：低位背手、单手摸背、双肩后收、抱臂、叉腰、俯卧/侧卧以及坐姿。检查对象包括新接口、已插入的弯头、线束弯曲余量和壳体，不只检查裸 PCB。

CAD 移走背包后留下的空位不能当作外置方案验证结果。该架构尚无确认板尺寸、电缆型号、接口型号或新采购单；现有 Rev M PCB/ERC/DRC/固件结果只对原集成版成立。

## 依据与文件

- 机械和接触数据来自本地 [Rev M 原检查](../verification/revM_complete_audit.json)、[Rev N1 删件检查](../verification/revN_chest_audit.json) 与 `manufacturing_manifest.json`。单独零件和姿态接触列表均保留。
- [TI：SPI 经 LVDS 传输参考设计](https://www.ti.com/tool/TIDA-060017) 说明远距离板间 SPI 需要处理信号完整性；其中演示距离依赖该参考设计，不能直接移植为本项目线长保证。
- [Analog Devices：LTC6820](https://www.analog.com/en/products/ltc6820.html) 展示 SPI 经双绞线转换的另一条路线，但传感器侧仍需配套转换电路；本项目未选用或验证此器件。
- [TI：TCAN332](https://www.ti.com/product/TCAN332) 是当前 CAN 收发器资料；[TI：TPS62162](https://www.ti.com/product/TPS62162) 是候选本地降压器资料。资料核对日期：2026-09-23。
- [三维查看器](../generated/revN/RevN_Chest_Review.html) · [Rev N1 入口](../START_HERE_REVN.zh-CN.md)

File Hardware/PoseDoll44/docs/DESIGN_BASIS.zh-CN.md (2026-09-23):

# 先完成设计，再进行实物测试

更新：2026-09-20。机械配合 Rev B；整机布局及电子板仍沿用各自现有修订。

用户目前没有合适的测试工具，已明确要求先参考调研继续设计，完成后再做实测。因此，**当前没有需要用户先执行的测量、打印或采购任务**。缺少实测数据不阻止 CAD、装配结构、五金选型、走线与软件继续设计。

## 资料如何进入设计

已读取用户提供的 [PLA材料比较对话](chatgpt-conversation://6aaf5e4b-487c-83ea-80e1-e14bc6727b53)，并补查两类来源：

- 拓竹 [Bambu Studio 2.0 官方发布说明](https://github.com/bambulab/BambuStudio/releases/tag/v02.00.00.95)介绍自动圆孔/轮廓补偿；[官方配置源码](https://raw.githubusercontent.com/bambulab/BambuStudio/master/src/libslic3r/PrintConfig.cpp)说明正的 XY 孔补偿使孔变大。这些是软件功能说明，不是 A1 mini 的成品孔径保证。
- [A1 mini 用户的原始反馈](https://www.reddit.com/r/BambuLab/comments/1izxcl4/)报告过约 0.4 mm 的孔径偏小。它是个别用户的观察，没有足够的材料、测量和重复试验信息，不能当成每台机器的固定误差。

本轮不引用一个统一的“打印精度 ±X mm”保证。对孔径采用 -0.4、-0.2、0、+0.1 mm 四个情景观察设计余量；这些数值是设计端选择的敏感性情景，不是实测分布、概率或置信区间。负数表示实物孔小于 CAD；它们是直径变化，不是单边变化。

## 本轮明确采用的设计值

基线为 A1 mini、0.4 mm 喷嘴、PLA，具体耗材品牌尚未确定。表内是本项目的候选 CAD 尺寸，不是螺纹标准尺寸，也不是已经标定的打印补偿。

| 接口 | CAD 直径 | 应用 |
|---|---:|---|
| M2 普通通孔 | 2.6 mm | 打印 PCB 托架、磁铁盖；PCB 自身的孔仍按板图，未套用 FDM 余量 |
| M3 普通通孔 | 3.6 mm | 普通紧固、止挡与调节螺钉 |
| M3 多片支架通孔 | 3.8 mm | 背柱长螺栓沿途的底座、背柱、上叉与支撑臂 |
| M4 普通通孔 | 4.8 mm | 底座固定孔、试验力臂孔 |
| M5 普通通孔 | 5.8 mm | 规则预留，当前 H1 没有对应孔或采购要求 |
| M6 普通通孔 | 6.8 mm | 主螺栓穿过打印底座、上叉 |
| M3 六角螺母槽 | 对边 6.0 mm、深 2.8 mm | 上叉调节螺钉；螺母防转和保持仍须后续检查 |

例如 M6 的 6.8 mm 孔，在“孔径小 0.4 mm”情景下为 6.4 mm，相对公称 6 mm 螺栓还剩 0.4 mm 的直径差。这个计算没有包含螺栓实物公差、孔位错位、椭圆和底层挤出，所以不能写成“保证能装”。

CAD 从 [参数文件](../mechanical_manifest/print_fit_profile_revB.json)读取这些数值；试片和孔位图使用同一来源。更换材料或收到实际反馈时可统一调整，再重新导出和检查，不必逐个改散落在零件里的数字。

## 定位与转动配合单独设计

H1 的轴系是 M6 螺栓 → 黄铜固定套 → POM 轴套 → 打印转子。

- 黄铜套内径 6.4 mm 属于金属零件的设计尺寸，不能因打印通孔改成 6.8 mm 就跟着改。螺栓夹紧，POM 内孔与黄铜外圆转动。
- POM 座暂保留 10.2 mm；磁铁座暂保留 6.2 mm、深 2.6 mm。这两处不能统一套用螺丝通孔余量。
- 以标称实物尺寸计算，在上述误差情景下，两个座孔都可能从过紧变成有间隙。设计端仍须完善轴套保持、磁铁定心/防自转方案，不能把“放得进去”当作已解决定位和角度误差。
- 螺母、磁铁和轴套的具体五金/材料由设计端确认。后续测试直接用这些实际装配件，不另设四根圆棒的必测步骤。

这些未完成项作为结构设计任务保留，不转化成“用户必须先测才能继续”的条件。

## 打印方向和补偿约定

当前 H1 主要孔轴平行于打印 Z 轴。试片也采用这一方向；它的结果不能自动代表横孔、76 mm 长孔或不同载荷下的变形。后续紧凑关节若出现横孔，应单独设计朝向、开口或可装配结构。

未来首轮切片使用 100% 比例，XY 孔/外轮廓补偿先设为 0，自动圆孔补偿关闭；底层象脚补偿记录实际预设。CAD 已留候选装配余量，因此不再未经测量叠加另一套全局放大。这里仅保存设计配方，没有修改用户正在使用的切片软件。

## 未来试片和验收顺序

Rev B H1-001 改为 M2、M3、M4、M6、POM 五行，覆盖本轮实际孔径。H1-002 的螺母槽深 2.8 mm、磁铁槽深 2.6 mm，与当前对应 CAD 候选一致。H1-003 厚度片不变。旧四行试片和新图不能混用；旧件可以保留，不要求现在重打。

这些文件先存放在工程包中。后续先由设计端完成结构、五金清单和装配测试说明，再交用户按包打印、装配并记录。试片只用于确需比较的配合；整关节转动、持姿与耐久则属于功能验证。

数字检查可验证有效实体、导出孔径和名义运动干涉；不能把社区数据或数字检查写成“已在用户机器测试通过”。当前所有实测结果仍为空，整机制造与性能尚未验证。

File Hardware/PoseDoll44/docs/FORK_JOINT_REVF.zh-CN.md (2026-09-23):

# Rev F 关节与两款手臂连接结构

这轮把 Manny、Quinn 的新比例落实到实际机械零件。先打开 [可旋转的机械查看页](../generated/revF/RevF_Mechanical_Review.html)，或在 CQ-editor 中打开 [入口脚本](../cad/revF/open_in_cq_editor.py)。

**已经做出四种单轴关节，以及两款左臂的肘部、腕部屈伸总装。其余多轴结构正在设计，当前不是完整手臂或整机的装配图。** 两款共用关节组件，连接长度各自独立；没有通过拉长上臂或移动腕中心来塞入关节。

带承力与测角组件的关节

## 看懂关节

叉架像一把两侧支撑的夹子，中间的转子可转动。两端分工如下：

| 位置 | 结构 | 用途 |
|---|---|---|
| 摩擦端 C | 带法兰光轴、摩擦片、承力座、轴套、复合止推片、弹簧座、碟簧、定位帽和轴向螺钉 | 承力、保持姿势，并向下一个连杆输出转动 |
| 中央 | 双 D 形孔的开口夹紧轮毂 | 把两侧转轴连在一起，减少装配间隙造成的换向误差 |
| 测角端 E | 第二根光轴、轴套、磁铁连接件、磁铁、独立电路板 | 支撑另一侧并测量转角 |
| 固定框架 | 打印叉架、金属嵌件和螺钉 | 接到上一级连杆；固定电路板位置 |
| 输出端 | 定位帽侧翼、金属隔套、打印法兰、两颗连接螺钉 | 接到下一级连杆；中间留轴向螺钉操作通道 |

承重由轴、轴套、金属承力座和框架传递，电路板不承受手臂重量。预紧的主要受力闭环是：碟簧 → 定位帽与轴向螺钉 → 带法兰轴 → 摩擦片 → 金属承力座 → 钢背止推片与弹簧座 → 碟簧。打印叉架固定承力座，但不被夹在这条高预紧闭环中。

径向 POM 轴套比 4 mm 厚的承力座短 0.2 mm，两端各内缩 0.1 mm，避免让它直接承担摩擦端的高轴向预紧。止推位置改为钢背复合滑动片；其滑动面和旋转弹簧座接触，表面加工要求仍须确定。

定位帽有 D 形键口和 M2 夹紧螺钉。D 形提供明确的传扭几何，夹紧结构用于减少孔轴配合间隙；CAD 不能证明实际换向回差为零。中央打印轮毂也有独立夹紧结构。

## 后续装配用光轴还是螺钉

这版的旋转承力部分确实是 **6 mm 或 8 mm 的光滑轴段**，与带法兰、D 形端和内螺纹的轴零件做成一体。它不是把普通全牙螺钉当作滑动轴。轴承配合面需要由加工供应方完成；用户不需要自己车削、磨轴或钻攻内螺纹。

M3 / M4 的轴向螺钉用来固定定位帽，M2 用来夹紧或连接输出件，其他 M3 用来连接框架。不能用这些螺钉的螺纹外径来代表光轴和轴套的配合尺寸。

当前光轴名义直径为 6.00 / 8.00 mm，POM 径向轴套孔的 CAD 名义值为 6.06 / 8.06 mm。中央打印轮毂的 D 形孔暂按轴径增加 0.4 mm，再由开口夹紧收紧。这些是不同用途的配合，不能混用；目前都没有实际公差验收。

以后发布样件时，会指定随组件一起使用的轴、轴套和螺钉，直接用这些实际配套件做装配检查。现在没有要求你另买圆棒、量规或先做测量。

## 两款连接长度

| 中心间距 | Manny / mm | Quinn / mm |
|---|---:|---:|
| 肩部基准中心 → 肘部中心 | 92.570 | 90.301 |
| 肘部中心 → 腕部中心 | 90.837 | 86.984 |

上臂背部梁连接到肘部固定叉架；前臂回接梁从肘部输出端绕到腕部固定叉架，使输出法兰的侧向安装距离不改变腕部的目标中心。当前梁的截面和接口属于集成候选，肩关节、前臂旋转与腕侧偏加入后仍可能修改。

新比例已经指出一些必须单独解决的空间问题：左右肩带根部间距只有 Manny 9.52 mm、Quinn 6.21 mm。肩、髋、躯干多个转轴共用中心，不能把这里的独立大叉架直接串联堆放。完整设计会复用摩擦端和测角端的内部零件，另外设计共用支撑框架。

全部 44 轴的状态见 [设计登记](../mechanical_manifest/dual_character_mechanics_revF.json)。尚未装入的轴保持“待集成”，没有被当作固定零度或已完成机构。

## 组件尺寸与材料状态

| 项目 | 当前设计基线 |
|---|---|
| 轴径 | S6 / M6 / H6：6 mm；L8：8 mm |
| 摩擦片外径 | 22 / 26 / 32 / 40 mm；名义厚度 1 mm |
| 承力座厚度、径向轴套长度 | 4 mm、3.8 mm |
| 摩擦端钢背复合止推片 | 10 × 20 × 1.5 mm，SKF PCMW 102001.5 E 尺寸候选 |
| 独立叉架两侧轴承中面间距 | 26 mm |
| 叉架输入端连接 | 两颗 M3，孔距 24 mm |
| 输出端连接 | 两颗 M3，孔距 22 mm |
| PCB | 现有 Rev B 18 × 20 mm AS5048A 板 |
| 主要打印材料与切片基线 | PLA、0.4 mm 喷嘴；真实强度、蠕变和尺寸尚未测试 |

模型按铝合金类、POM、钢、摩擦衬片和打印材料分组。金属牌号、热处理、表面质量、摩擦片产品、精确公差、紧固扭矩和螺纹防松方式尚未冻结。零件 STEP 可供审阅，不能直接作为有完整加工要求的采购图。

碟簧的几何与力数据来自 [SCHNORR 2024 目录](https://www.schnorr-group.com/fileadmin/4_Downloads/Brochures/SCHNORR_Produktbroschuere_EN_2024-02.pdf)；止推片尺寸来自 [SKF 复合滑动轴承目录](https://cdn.skfmediahub.skf.com/api/public/0901d19680090e01/pdf_preview_medium/0901d19680090e01_pdf_preview_medium.pdf)。候选件库存、加工配合和应用表现没有确认。

## 装配顺序设计

以下用于检查零件是否可拆装，不是当前让用户开始装配的操作工单。

1. 将带止转形状的径向轴套装入两侧金属承力座；清理并检查轴孔、接触面。
2. 组装摩擦端：摩擦片止转耳装进金属槽，穿入法兰轴，依次加入复合止推片、钢座、碟簧和定位帽，安装轴向螺钉。
3. 调整并夹紧 D 形定位帽。当前帽的肩面限定名义弹簧压缩高度；后续需确定精密垫片与调节流程，不能凭拧紧螺钉就认定获得目录轴向力。
4. 将两根轴的内端插进中央开口轮毂，按规定轴向位置定位，再分别夹紧；把两侧承力座装到叉架的四个安装位。
5. 装测角端的磁铁连接件、磁铁保持桥、间隔柱与 PCB，检查名义间隙和转动是否擦碰。
6. 装输出法兰与连杆，检查每个螺钉和嵌入螺母的操作方向，再接线、做零位和方向校准。

完整工具伸入空间、所有装配先后约束、拆装磨损和线束接头空间还没有通过实物检查。测角端有轴向游隙候选尺寸，需要在后续精密定位设计中控制；当前名义磁铁间隙不是已经验证的全行程磁场指标。

测角端朝向与摩擦端相反，因此局部独立叉架正转时，E 端局部角度方向是 −1。该符号已写入接口记录，后续接入固件时必须经过设备标定；此轮未改动现有固件、模拟器或 UE 映射。

## 验证与后续

[本轮报告](../verification/REVF_REPORT.zh-CN.md)列出有效实体、同组装配、跨组运动、打印包围盒、部分总装质量与重力矩。运动采样通过只说明这些采样姿态没有超过阈值的穿插。

接下来需要完成多轴共享框架、完整腿脚和右侧总装，之后才能做整机碰撞、线束、支架、重量、持姿和抓握力检查。Rev E 的极端颈部误差与 Quinn 的 UE 适配仍需解决。现在不用打印、测量或采购。

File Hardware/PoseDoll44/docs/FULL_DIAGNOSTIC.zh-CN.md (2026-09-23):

# 全身诊断工具（PD41）

入口：`Tools/PoseDollHardwareBridge/Open_Full_Diagnostic.cmd`。这是全身六节点工具；旧的 `Open_Diagnostic.cmd` 仍用于 H1 单轴。

当前默认只打开窗口，不扫描端口、不打开串口、不向 UE 发数据。先使用“打开离线记录”查看已有 `.bin`；实物阶段确认设备身份后，再点击刷新、选择明确的串口、开始采集。一次默认 10 秒，可中途停止并保留结果。

界面列出全部 44 个协议位置。其中骨盆三轴为固定参考，原始读数显示横线；其余 41 轴区分有效、故障、缺失。缺失和故障不会填成零，也不会使用上一帧凑齐姿势。显示的角度是传感器原始计数换算，不是校准后的机械关节角度。

保存结果包括原始 `.bin`、逐帧 `.jsonl` 和 `.summary.json`。摘要包含完整有效帧数、六节点到齐数、丢帧、错误及连续有效段的原始角度波动。缺失、故障与序列间隔会分开统计段；跨越 0/360° 会按连续角度展开。只有保持人偶不动时，波动才可作为噪声参考，不能据此声称测角精度或装配通过。

`calibrated` 和 `physical_acceptance` 始终为 false。零点、正负方向、磁场与实际机械角度仍需后续实物验证。本工具不会发送 UE 姿势或烧录固件。

离线命令示例（在本目录）：

```powershell
python full_diagnose.py --input recording.bin
```

硬件阶段的采集命令必须显式给出已核实端口和新的输出名前缀：

```powershell
python full_diagnose.py --port COM7 --seconds 10 --out captures/session01
```

端口号仅是示例，不能照抄。已存在的记录不会覆盖。当前双击入口使用本机 Espressif Python；迁移机器时需安装 Python、Tkinter、pyserial 并调整入口路径。

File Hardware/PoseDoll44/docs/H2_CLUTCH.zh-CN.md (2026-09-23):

# H2 持姿关节研究夹具

这是可检查零件、预紧路径和转动空间的独立机构。当前已经生成三种尺寸的 CAD；完整人偶还需要把摩擦核心嵌入叉架、减去重复支座。**本文件不是整机生产放行，也不要求现在打印或采购。**

## 它怎样工作

手动转动蓝色操作杆，会带动有 D 形平面的金属轴和轴上的一体摩擦盘。金属轴在两只 POM 轴套里转动；螺纹不会在轴套内充当转轴。

摩擦盘两面各有一片可更换的摩擦衬片。三处碟簧通过浮动金属压力板压紧衬片。调节螺钉和锁紧螺母用于初装与维护；设计的使用目标是调好后直接用手摆姿势，不必每次重新拧紧。

预紧力的闭合路径是上金属板、调节螺钉、碟簧、浮动压力板、衬片、摩擦盘、衬片、固定反力板和金属支柱。打印的传感器支架不在这条主预紧路径中。下层螺母先独立锁紧金属框架，上层螺母再固定传感器支架。

磁铁座套在轴端的 D 形平面上，由一颗侧向 M2 螺钉夹持；磁铁上方另有薄保持桥和两颗尼龙 M2 螺钉。磁铁座与保持桥的夹持螺母在不同位置，可以实际装入槽内。PCB 采用两端分别拧入的尼龙内螺纹隔离柱，消除了长螺钉向磁铁转动区域伸出的情况。

剖面

图中为解释结构而移除了四分之一；实际打印件和加工件没有这个剖切。

## 三种规格

| 项目 | S | M | L |
|---|---:|---:|---:|
| 摩擦片外径 / 内径，mm | 26 / 10.4 | 38 / 10.4 | 54 / 12.4 |
| 金属框架最大外径，mm | 48 | 60 | 76 |
| 光滑轴名义直径，mm | 8 | 8 | 8 |
| 碟簧布置，三处相同 | 每处两片串联 | 每处两片串联 | 每处两片并联，再两组串联 |
| 总碟簧数量 | 6 | 6 | 12 |
| 目录条件下合计弹力，N | 312 | 312 | 624 |
| 独立 CAD 总装 | [S](../generated/revC/H2/S/H2_S_assembly.step) | [M](../generated/revC/H2/M/H2_M_assembly.step) | [L](../generated/revC/H2/L/H2_L_assembly.step) |

碟簧候选为 SCHNORR 000300：外径 8、内径 3.2、厚 0.3、自由高 0.55 mm；目录在单片挠度 0.188 mm 处给出 104 N。上表的合计力由目录单片数值和串并联关系计算，**不是实际调节到某个位置就必然得到的力**。[厂家目录](https://www.schnorr-group.com/fileadmin/4_Downloads/Brochures/SCHNORR_Produktbroschuere_EN_2024-02.pdf)

导向压钮的细杆穿过浮动压力板，止于下方的**固定**反力板，避免止挡反力继续直接压在浮动压力板上。限位尺寸、衬片压缩和碟簧公差仍需要实物核对；不能以“拧到底”代替调节和测量持姿力。

目前摩擦系数 0.15 / 0.30 只是敏感性分析取值，衬片材料尚未最终选定。按均匀面压、两个摩擦面推算，L 规格在 624 N、μ=0.15 时约为 3.51 N·m。这个值还没有通过实物验证，也没有覆盖当前约 6.91 N·m 的保守全姿态上界目标。实际可达姿势、操作舒适度和需要的平衡措施还要继续设计。

## 数字检查的范围

三种夹具都检查了所有零件之间的实体相交；仅明确列出的螺纹外径包络与配对底孔相交作为螺纹啮合处理，列表保存在 [检查结果](../verification/H2_clutch_geometry.json)。没有按“同一个刚体”整类跳过装配碰撞。

每种又按 15° 间隔检查了 0°～345° 的转子运动，总计 72 个离散样本。它们用于发现干涉，不能证明样本之间永远没有碰撞，也没有包含线缆插头、弯曲半径或手指操作空间。

12 个打印 STL 对应每规格的 PCB 支架、开口操作杆、磁铁座和保持桥。CAD 实体与 STL 网格的有效性及打印包络由 [新版审查](../verification/revC_review.json)核对。保持桥厚 0.8 mm，规划 0.2 mm 层高时为四层，强度和手感待实测。

## 交给加工端的尺寸意图

金属和 POM 件应由供应商按最终图纸交付；不会让你自行把普通螺丝磨成精密转轴。以下为当前设计值，仍须完成供应商工艺审查和完整公差图。

| 部位 | 当前设计要求 |
|---|---|
| 一体轴 | 6061 铝合金候选；全长 46 mm；光滑轴颈 7.98～8.00 mm；两端 D 形平面距轴心 3.5 mm，平面到对侧圆面的距离为 **7.5 mm** |
| 轴上摩擦盘 | 与轴一体加工；S/M/L 直径分别 28/40/56 mm，厚 3 mm |
| 轴承板孔 | CAD 10.02 mm，候选制造范围 10.02～10.04 mm |
| POM 轴套 | 外径 9.99～10.00，成品内径 8.05～8.08，筒长 4 mm；法兰直径 14、厚 1 mm |
| 上下金属轴承板 | 厚 4 mm；上板三孔最终攻 M3，STEP 中保留的是 2.5 mm 底孔 |
| 固定反力板 / 浮动压力板 | 厚 3 mm；工作面平面度 0.05 mm、Ra1.6 为加工目标，尚无检验结果 |
| 金属支柱 | 外径 6、通孔 3.4 mm；不同位置长度 5 / 13 / 16 mm |
| 导向压钮 | 头部直径 8、厚 1 mm；杆直径 3；S/M 杆长 11.224 mm，L 杆长 11.824 mm，候选长度公差 ±0.02 mm |
| 摩擦衬片 | 无石棉材料候选，名义厚 2 mm；材料牌号、压缩和静动摩擦差尚未放行 |
| 磁铁 | 直径 6×2.5 mm，径向充磁；CAD 槽 6.2×2.6 mm |

轴承配合由金属/POM 成品尺寸控制。打印件采用已约定的工程配合假设，例如 M3 通孔 3.6、M2 通孔 2.6 mm；夹轴的打印 D 形孔另留装配余量并使用开口夹紧。未来用最终这些零件直接验证，不额外要求购买一套仅用于测量的圆棒。

## 传感器安装

[传感器 Rev B](../electronics/sensor_revB/PoseDoll_AS5048A_revB.kicad_pro)为 18×20 mm，固定孔中心相对芯片为 (±6.5, 6.5) mm，孔径 2.2 mm。连接器在背面，芯片朝向磁铁。小板适合交由 PCBA 服务焊接，当前未安排打样。

H2 中磁铁顶面位于 Z=37.5 mm；由 KiCad 库模型推得芯片封装面名义间隙约 1.805 mm。保持桥占用其中一部分空间。该间隙不等于保证磁场合格，PCB 安装面的轴向误差、磁铁偏心和轴颈跳动要一起核查。[AS5048 数据手册](https://look.ams-osram.com/m/287d7ad97d1ca22e/original/AS5048-DS000298.pdf)

PCB 固定使用绝缘紧固件。板下螺钉头部高度不得超过 1.4 mm；用普通较高螺钉直接替换可能进入转动空间。PCB 支架的 4.2 mm 调整孔配上下直径 8 mm 的绝缘压片，支持后续平面内对中。板端使用 M2×4、支架端使用 M2×6，内螺纹隔离柱长 6 mm。实物零件尺寸和装配后的间隙仍待核验。

## 后续装配次序

设计放行后，先按零件编号核对供应商件；再从下轴承板开始放入轴套、轴、固定反力板、衬片和浮动压力板；装上导向支柱、弹簧组、压钮和上轴承板，先锁紧金属框架。之后再安装操作杆、磁铁座、保持桥和传感器支架，最后调节机械阻力、对中和读数。

详细的逐步紧固顺序、工具入口、衬片保持方式、供应商型号和力矩规范仍需在最终版本补齐。这些属于后续设计任务；目前没有要求你按照本段动手装配。

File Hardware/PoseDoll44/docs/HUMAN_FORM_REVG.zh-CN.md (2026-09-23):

# Rev G · 分段硬壳，活动区裸露

按用户最新决定：**形状稳定的独立刚性部位可以包壳；会因运动产生外形变化的区域不包壳，直接露出机械骨架。** 此规则适用于 Manny 和 Quinn，替代上一轮的柔性连接、浮动肩盖及重叠活动壳片方案。

目标仍是让人偶具有可辨认的人体比例和方便握持的四肢主体。活动区的开口是有意保留的结构，不是等待补齐软皮的缺口。当前为设计研究，尚未制造放行。

## 身体各部位怎样处理

| 部位 | 当前覆盖决定 | 壳体边界 |
|---|---|---|
| 头部主体 | 可用硬壳 | 颈部转轴保持裸露 |
| 上臂、前臂主体 | 保留可拆的分段硬壳 | 肩根、肘窝、腕部和前臂旋转连接处开口 |
| 大腿、小腿主体 | 设计分段硬壳 | 髋、膝、踝周围退让，不跨接转轴 |
| 手掌及脚的刚性节段 | 可用硬壳 | 腕、踝和前脚掌弯曲轴裸露 |
| 胸腔、骨盆的中央刚性框架 | 仅在确认稳定的局部设置小壳 | 每片只随一个刚性节段运动，不能默认整片胸背或骨盆都可封闭 |
| 肩带、肩胛活动区、肩根、腋下 | 裸露 | 不设计硬壳、软皮或浮动肩盖 |
| 颈、腰腹、腹股沟 | 裸露 | 保留相邻节段的旋转和让位空间 |
| 肘、膝、腕、踝及轴向旋转连接区 | 裸露 | 壳边按运动范围修剪，必要时延伸到邻近肢体主体，不能只留一条细缝 |

这里的“稳定”指属于同一个机械刚性节段，并非假设真实人体肌肉完全不变形。例如前臂主体仍可以有外壳，但若内部旋转使两部分相对运动，外壳也必须分开，不能把它们锁在一起。

因此，肢体中段可以保持人形轮廓，内侧需要被挤压或让位的部分则可以开窗、截短。机械功能与完整动作范围决定壳边，不能为了外形完整把关节重新封住。

## 对原 44 轴设计的影响

各角色体格比例、轴 ID、轴序、轴向和运动范围继续保留。肩带每侧的前伸／后收、抬高／下压两轴也保留；当前尺寸的实体肩带仍需完成，不会因为外露而自动视为已验证。

约 90.8 cm、1:2 仍只是封装研究候选，本次决定没有再次放大人偶。肩部前伸时的肩中心位移约 44.5 mm（Manny）和 38.1 mm（Quinn），这片运动空间现在保留开放，不再设计柔性件跨接。

[肩部动作查看页](../generated/revG/Human_Form_and_Shoulder_Review.html) 中的完整 UE 体表只用于观察比例与动作，不是实际硬壳覆盖范围。实体的肩带和周边活动区将裸露。

## 已落到局部 CAD 的修改

已有上臂、前臂分体壳继续保留，并进一步切退肘窝闭合侧的边缘。新的让位面截距为 24 mm、斜率为 2.5，具体位置由局部坐标定义；这不是要求用户自己测量的装配尺寸。

两款 STEP 均随脚本重建，指定弯肘样本与壳片实体检查结果以 [当前检查报告](../verification/REVG_REPORT.zh-CN.md) 为准。检查没有覆盖完整手臂所有转轴、制造公差、载荷和实际操作手感，不能据此把全身标为已通过。

壳体扣合、固定螺钉、倒圆和线束仍需细化；当前新 PCB 和部分传动件也只是占位。其余部位的表格是完整人偶的设计约束，不代表对应 CAD 已全部完成。

## 接下来的结构验证

1. 裸机构先满足全部轴的目标范围与组合姿势，再装上稳定节段硬壳复核；没有第三步“加软皮”的验收要求。
2. 肩带检查前伸、后收、耸肩与举臂、抱臂等组合；肘、膝和髋检查最大弯曲时壳边是否碰撞。
3. 按带壳后的重量与抓握位置核算持姿力矩、操作力和线束恢复力。
4. 裸露区域整理走线、处理接触边缘并留出手指操作空间；这些局部处理不能变成覆盖活动区的外壳。
5. 保留单节段可拆壳、传感器可维护性与原 44 轴读数校准。

结构化规则保存在 [shell_coverage_revG.json](../mechanical_manifest/shell_coverage_revG.json)。当前不用打印、测量或采购。整机机械设计、颈部位置误差和 Quinn 的独立 UE 适配等未完成项继续登记。

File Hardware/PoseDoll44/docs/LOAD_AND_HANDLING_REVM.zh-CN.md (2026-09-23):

# Rev M 受力与操作阻力：数字计算能说明什么

完整质量和重力矩来自实际 CAD 实体，加上线束导体/绝缘层质量与 15% 线束余量。每轴检查 191 个相对姿态，并对每个样本取任意重力方向的力矩上界；因此不依赖实体必须一直站着。计算见 [全身质量与力矩](../verification/revM_load_work.json)，操作力和强度需求见 [计算工作表](../verification/revM_strength_handling_screen.json)。

这版是接近 91 cm 的桌面姿势工具，估重约 3.2 kg，手感会比普通美术小人偶沉。腰部名义保持扭矩约 5.19 N·m；单独转动这个轴，在 100 mm 理想力臂处需约 52 N，在 50 mm 处约 104 N。实际需要双手握稳定骨段、借助外部承托，不能把传感器托座当把手。这也是首先制作一个腰部关节验证手感的原因。

预紧力没有被当成“越大越好”。目前腰、胸用双摩擦面，在名义摩擦系数 0.15 下达到持姿预算。系数降低 20%，扭矩也近似降低 20%；纸面 1.5 倍余量不能覆盖所有摩擦材料、污染、磨损和温度情景。实测不足时，应重新设计或调整摩擦面和预紧组合，不把保持螺钉继续拧紧到未知状态。

## 已做的解析筛查

高负载关节名义轴向力 1,656 N，原型证明载荷目标为 2,484 N。用 M3 名义拉应力面积 5.03 mm² 计算，螺纹杆的平均拉应力分别约 329 / 494 MPa。这里没有把 Grade 5 钛材料的典型强度当成按钮头螺钉的保载证明；螺钉头、过渡圆角及实际证明载荷要由供方核对。

按有效啮合长度保守取 6 mm 的简化圆周剪切面积估算，M3 内牙在证明载荷下的平均剪应力约 99 MPa。这不包含首牙载荷集中、倒角、底孔误差、加工损伤或拆装磨损，不能代替螺纹拉脱试验。名义 CAD 7 mm 左右的啮合不能全部直接算作有效牙长。

D8 输出键以总扭矩检查平均键面压力；D6 上部轴段以双摩擦结构的上摩擦面分支扭矩检查。工作表列出了这些截面需求，没有据此给出整根有轴向孔、D 平面和径向孔的轴的“强度通过”。肩、颈与胸框的弯折、载荷分配和局部应力也还没有做有限元鉴定。

举例：12×10 mm、内部 8×6 mm 的理想空心梁，其较弱方向截面模量约 171.2 mm³；2 N·m 弯矩对应名义应力约 11.7 MPa，假设局部放大 2 倍则约 23.4 MPa。真实打印件的层间强度、接头圆角和斜放支撑可能决定失败位置，不能用“PLA 的某个网上拉伸强度”直接宣布合格。

## 必须由首件补上的证据

- 高负载关节的保持扭矩、运行阻力、起动突跳、回差、预压件和螺纹拉脱。
- 真实打印姿态下的梁与节点，含外壳、电子仓和线束的静载、挠曲、层间破坏及重复摆动。
- PEEK 接触面的蠕变/磨损和温升；压入式 POM 轴套的保持力与温度影响。
- 线束弹性恢复力、反复弯折、最长 SPI 线波形以及多颗磁铁/金属之间的磁场影响。

数字模型已经能给出这些试验的具体对象与载荷要求。当前没有额定负载、跌落等级、长期寿命或“全姿态不下垂”的实物结论。分阶段原型验证通过后，才适合按同一工艺复制完整人偶。

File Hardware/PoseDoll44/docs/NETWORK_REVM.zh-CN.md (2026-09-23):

# 全身网络接口（Rev M 数字原型候选）

本文件对应 [network_revM.json](../mechanical_manifest/network_revM.json)。六个节点固件已编译；四种 PCB 的布线、壳体安装和两款线束表已交付。ERC、DRC 及原理图/PCB 一致性检查均为零违规，尚无实物通信验证。H1 单轴固件及已测试的 UE/模拟器没有改动，也没有连接串口或发送模拟的硬件数据。

## 通道分区

| 节点 | 负责部位 | 测量数 | 协议索引 |
|---|---|---:|---|
| N1，兼 USB 网关 | 腰部 | 3 | 3–5 |
| N2 | 胸、颈头 | 6 | 6–11 |
| N3 | 左肩带至左手腕 | 9 | 12–20 |
| N4 | 右肩带至右手腕 | 9 | 28–36 |
| N5 | 左髋至前脚掌 | 7 | 21–27 |
| N6 | 右髋至前脚掌 | 7 | 37–43 |

索引 0–2 是骨盆固定参考，不占传感器接口。新 N1 的腰部接 P1–P3，不能照旧 44 颗传感器的分配接 P4–P6。每个区域最多九口，P1–P9 的 CS GPIO 依次为 2、4、5、6、7、8、9、10、14。SCK/MOSI/MISO 为 12/11/13；CAN TX/RX 为 17/18；USB 19/20 保留。

控制器候选为 ESP32-S3-WROOM-1-N8，区域板直接安装模块。当前板形为 40 × 86 mm、四层、1.2 mm 厚；该布局是制造候选，需厂家确认叠层与工艺后进行首件验证。SPI 初始 250 kHz、mode 1；逐口独立缓冲 SCK/MOSI/MISO、CS 独立控制，目标是减少长线分支互相影响。每口源端阻尼候选 100 Ω，现有传感器 MISO 源端 33 Ω。阻值和最长线束必须通过波形/丢帧实测后定型，降频不能代替信号完整性设计。[模块资料](https://www.espressif.com/sites/default/files/documentation/esp32-s3-wroom-1_wroom-1u_datasheet_en.pdf)、[缓冲器资料](https://www.ti.com/lit/ds/symlink/sn74lvc125a.pdf)。

## 电源和 CAN 候选

使用 5 V 外部电源、各区独立 3.3 V 降压，不增加电池。适配器采用稳压 5 V / 3 A 候选，并要求短路保护。线束压降和电流计算见 `verification/revM_harness_power_<角色>.json`；MCU 电流、转换效率和接触电阻是待测假设，不能把计算通过当作供电实测。每块区域板都必须由外部 5 V 供电，USB VBUS 不连接节点电源。USB 仅传数据；由 [TS3USB221E](https://www.ti.com/lit/ds/symlink/ts3usb221e.pdf) 隔离数据线，只有检测到主机 VBUS 时才使能，芯片断电时采用其 Ioff 隔离功能。降压采用 [TPS62162](https://www.ti.com/lit/ds/symlink/tps62162.pdf)，固定 3.3 V 版本的 FB 引脚接地。LM66100 不在当前电路中。区域原理图共 142 个器件、123 个网络，原生 KiCad ERC 为 0 违规；完整 PCB 和电源回路的候选文件在 `generated/revM/electronics`；零违规不代表温升、EMC 或实际供电已合格。

CAN 收发器选择 3.3 V 的 TCAN332DR 候选，避免对远端 5 V 电压同时提出收发器的稳压要求。芯片支持断电时总线高阻；实际板上的保护器件、接地和线束仍需一起验证。[TCAN33x 官方资料](https://www.ti.com/lit/ds/symlink/tcan332.pdf)。

协议为传统 11-bit CAN，500 kbit/s，不使用 ESP32-S3 不具备的 CAN FD 控制器能力。总线按 **N6 → N1 → N5 → N3 → N2 → N4** 串联，只在 N6、N4 各装 120 Ω 端接。N1 是中间节点兼网关，不额外端接；电源独立六路星形分配。当前没有 G0 节点或固定底座。裁线及针序见 [线束说明](WIRING_REVM.zh-CN.md)。目标 60 次/秒同步采集，各节点在接收到 SYNC 后 8 ms 内完成本地采样，网关在发出 SYNC 后 14 ms 结束收集。各节点晶振未校时，不能把本地 8 ms 当作全身同时采样窗口。27 个标准 8-byte 帧按保守 135 bit/帧估算约占 43.7% 带宽；这只是初算，不含启动、诊断突发与重传，也不是已测吞吐量。

## 同一批次采集

每一批从空数据开始，不能借用上一帧的关节读数凑齐本帧。

固件的 CAN 帧分配如下，均使用 8 字节数据、小端数值：

| ID | 内容 |
|---|---|
| 0x080 | 新采集会话 epoch，uint64 |
| 0x081 | SYNC：cohort uint32、网关时间低 32 位 |
| 0x100 + 节点号 | 节点 boot_id uint64 |
| 0x120 + 节点号 | 确认 epoch uint64 |
| 0x180 + 节点号 | END：cohort uint32、开始偏移 uint16、采集跨度 uint16，单位 μs |
| 0x200 + 节点号 ×16 + 分组号 | cohort uint32、两个传感器 word uint16 |

节点收到新 epoch 后必须中止旧采集、清理发送队列，再确认会话。网关完成身份/区域核对并清理旧接收帧后才开始 SYNC。数据包只有 cohort，因此队列清理和会话确认是必需的配套规则，不能只抄数据包格式。32-bit cohort 回卷时另起 epoch。N1 的本地腰部数据也走同样的组装检查。

END 必须晚于该节点所有分组。缺组、重复组、超时、读数编码不合法或节点重启，都使该节点在当前批次保持 missing。读到传感器故障时应传 invalid，不把故障读数改成零。这里只是有线设备间的完整性协议，不提供对抗恶意设备的身份认证。

## USB 诊断帧

PD41 与原 H1 有独立 magic。COBS 分帧，末尾 0 分隔；COBS 解码后为 164 字节，末尾 CRC32 校验前 160 字节。

头部为 `<4sBBHQQQQIHH`，共 48 字节：magic `PD41`、版本 1、类型 1、正文长度 160、设备 ID、boot ID、递增序号、网关时间 μs、采集窗 μs、6-bit 节点到齐掩码、通道数 44。随后 44 个 uint16 word，再接六组（开始偏移、采集跨度）uint16。此处传输的是网关时间基准下的保守包络 `[0, END 中断接收时刻 − SYNC 发出前时刻]`，包含 CAN 仲裁和发送等待，最大 14 ms；不是节点自己的 delay/span。缺失节点的时间字段全零。END 原始 delay/span 另作合理性检查；接收时间取自 CAN 中断，任务排队延迟不会把迟到帧伪装成准时帧。

- `0x0000–0x3FFF`：有效 14-bit 原始计数，只能出现在实际测量轴。
- `0x4000`：明确的骨盆固定参考；另用于 CAN 奇数分组的末尾填充，不能填实际测量轴。
- `0x8000 | flags`：传感器无效，flags 是 H1 已定义的非零五位故障位，不包含一个可用角度。
- `0xFFFF`：当前批次缺失。
- 其他编码拒绝。

桥接器只能把完整、有效且经过实体校准的批次作为姿势发送给 UE。当前 Python 工具提供全身诊断窗口、显式选择端口后的记录，以及离线批次检查，见 [全身诊断说明](FULL_DIAGNOSTIC.zh-CN.md)；诊断窗口的 `calibrated` 始终为 false。另有显式设备绑定的离线实体校准及协议转换入口，见 [构建与校准](BUILD_AND_CALIBRATE_REVM.zh-CN.md)；没有自动替用户生成的实体零点，也没有连接当前 UE 会话。硬件零点、传感器方向、磁场验证和设备绑定不能由测试用计数代替。

离线验证覆盖 Python 桥接/协议/校准、9 个 C 核心边界场景及 C/Python 黄金字节流一致性；最终次数和结果以 `verification/revM_offline_tests.json` 为准。ESP-IDF 6.1 下 N1–N6 六个配置均成功编译，记录见 `verification/revM_firmware_build_work.json`；生成的板级引脚配置由网络清单自动核对。固件使用 ESP-IDF 新 `esp_twai` 接口，依次发送各组后才发 END，并在会话变化时清空旧队列。

没有烧录、串口连接、实物 CAN 测试或真实全身数据采集。零点、轴方向、磁场、供电波形及长线 SPI 仍须在实物阶段检验。编译和离线测试结果不替代这些验证。

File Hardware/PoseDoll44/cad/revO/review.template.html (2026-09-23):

POSEDOLL / DESKTOP / REV O

# 桌面人偶 · 第一轮设计研究

91 cm Rev N1 已保留为备用。新版以 48 cm 为设计锚点，比较更小候选；保留 41 个测量轴与外置 G0。这里显示可核对的布局与关节实体，未完成的总装、实测和制造验收均单独标明。

角色 参考高度 mm显示节点板布局正面侧面

拖动旋转 · 滚轮缩放。灰线为解剖骨架，蓝点为测量轴原点；红色板件位置存在空间缺口。此图不是已装配整机，完整本体高度尚未得出。

41 轴参考中心当前不合格板位待复核板位

### 各档上臂板位缺口

按同一份 40×66 mm 九路板及肩/肘端部 18+14 mm 探索预留计算。接头拔插为板面法向，未错误计入板长。失败仅针对当前布置，不表示该身高无法重新设计。

参考身高 | Manny 左上臂可用长度 | 当前缺口 | Quinn 左上臂可用长度 | 当前缺口

关节族 展开轴向零件隐藏固定壳与板托复位视角

直接读取 CadQuery 实体网格；传感器 STEP 保持原尺寸。黄色维护区在单独的 CAD 报告中检查。碟簧规格、固定件、公差与手感尚未冻结。

## 已落盘的内容与仍需解决的问题

打开本轮审查说明：关键问题、源码与证据索引

工作项 | 当前状态 | 证据
91 cm 备用保护 | 5,748 个原文件建立哈希清单 | 基线清单
旧版兼容回归 | 81 项 Python + 9 项 C，通过 | 迭代说明
G0 / N1–N6 | 独立网关、六路远端节点；实际编译状态见记录 | 编译证据
双角色 × 五档尺寸 | 已生成骨架、板件 STEP 与具体缺口 | 完整比较
3/6/7/9 路 PCB | 原生 KiCad 原理图与布局；尚未布线 | ERC / DRC 记录
三档关节 | 实体与维护区分开检查；有待解决项 | 关节报告
整机动作、测角、载荷、线缆 | NOT_RUN：需要完整机构与真实器件 | 测试流程

### 第一批可打印配合样片

A01 轴孔配合样片 STL · A02 板边配合样片 STL · 尺寸位置图

样片用于测量打印配合，不能代替承重关节。下一轮须先解决 N3/N4 的分板或躯干内布置、大关节低摩擦条件下的预紧能力，以及当前超过 1.2 kg 的质量预算，再推进完整外壳与全身制造包。

本页使用本地生成的数据；没有云端依赖。制造放行：否 · 实物验证：未运行 · 打开 91 cm 备用方案

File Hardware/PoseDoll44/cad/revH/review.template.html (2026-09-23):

POSEDOLL 44 · REV H · SHOULDER ASSEMBLY

# 肩带与双臂：沿原轴线集成

Manny / Quinn · 约 90.8 cm 候选尺寸 · 稳定节段包壳，关节活动区裸露

正面侧面斜侧面显示臂壳显示占位件重置

拖动旋转 · 滚轮缩放 · 点击零件
实际 CAD 几何；轴承、固定与持姿细节仍在设计，未制造放行。

## 组合姿态检查

自然耸肩前伸侧举错开抱臂

承力框架候选分段臂壳轴、摩擦盘双臂摆姿需避让

这轮集成了什么

左右肩带各两轴、肩部各三轴，接上已有的两条肘臂架，共 12 个转轴参与检查。

两側轴承前后错开，持姿盘上下错开；转动中心与原 44 轴配置一致。肩带和关节区不加外壳。

通过样本不代表完成制造

肩部屈伸／外展的持姿组件尚未装入；预紧、轴端固定、六路肩部测角、线束与全身碰撞仍待完成。绿色和橙色占位件不是完成的电子或传动组件。

左右两臂的相交保留为橙色摆姿限制；关节内部、同侧相邻肢段等结构冲突仍标红。错开抱臂仅证明当前局部 CAD 有一个可达候选，还未包括躯干表面、头和手。

点击零件查看所属运动节段与设计状态。

肩带结构与设计边界
全部检查结果
当前角色 STEP 总装

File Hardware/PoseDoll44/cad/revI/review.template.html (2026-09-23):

POSEDOLL 44 · REV I · SHOULDER HOLDING

# 肩部持姿：四套摩擦组件已集成

Manny / Quinn · 约 90.8 cm 候选尺寸 · 稳定节段包壳，关节活动区裸露

正面侧面斜侧面显示臂壳显示占位件只看肩部重置

拖动旋转 · 滚轮缩放 · 点击零件
实际 CAD 几何；轴承、固定与持姿细节仍在设计，未制造放行。

## 组合姿态检查

自然耸肩前伸侧举错开抱臂

承力框架候选分段臂壳轴、摩擦盘双臂摆姿需避让

这轮集成了什么

左右肩带各两轴、肩部各三轴，接上已有的两条肘臂架，共 12 个转轴参与检查。

新增左右肩屈伸、外展的四套摩擦组件，包括金属转轴、摩擦片、碟簧、轴端固定和连接支座。关节中心与两款人物比例保持。

通过样本不代表完成制造

新增组件的预紧力沿金属件闭合；持姿力、操作手感、公差、耐久尚未实测。肩带与扭转轴的预紧细节、六路肩部测角、线束与全身集成仍待完成。

左右两臂的相交保留为橙色摆姿限制；关节内部、同侧相邻肢段等结构冲突仍标红。错开抱臂仅证明当前局部 CAD 有一个可达候选，还未包括躯干表面、头和手。

点击零件查看所属运动节段与设计状态。

肩带结构与设计边界
全部检查结果
当前角色 STEP 总装

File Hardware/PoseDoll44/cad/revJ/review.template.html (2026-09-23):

POSEDOLL 44 · REV J · DRIVE & READOUT

# 肩部细化：夹紧传力与两路测角

Manny / Quinn · 约 90.8 cm 候选尺寸 · 稳定节段包壳，关节活动区裸露

正面侧面斜侧面显示臂壳显示占位件只看肩部左肩测角细节重置

拖动旋转 · 滚轮缩放 · 点击零件
实际 CAD 几何；轴承、固定与持姿细节仍在设计，未制造放行。

## 组合姿态检查

自然耸肩前伸侧举错开抱臂

承力框架候选分段臂壳轴、摩擦盘双臂摆姿需避让

这轮集成了什么

左右肩带各两轴、肩部各三轴，接上已有的两条肘臂架，共 12 个转轴参与检查。

四处 D 形传力口加入可拆的金属夹头。左右外展轴加入真实传感器板、磁铁、保护盖和绝缘固定件。人物比例与关节中心保持。

通过样本不代表完成制造

持姿力、夹紧后的回差、磁场质量和手感尚未实测。屈伸、扭转的四路肩部测角，以及肩带预紧、线束和全身集成仍待完成。绿色 PCB 是实际几何；插头与线束仍只是占位。

左右两臂的相交保留为橙色摆姿限制；关节内部、同侧相邻肢段等结构冲突仍标红。错开抱臂仅证明当前局部 CAD 有一个可达候选，还未包括躯干表面、头和手。

点击零件查看所属运动节段与设计状态。

肩带结构与设计边界
全部检查结果
当前角色 STEP 总装

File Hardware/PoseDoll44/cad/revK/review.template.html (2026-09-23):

POSEDOLL 44 · REV K · COMPACT TWIST READOUT

# 肩部细化：紧凑测角板与上臂扭转

Manny / Quinn · 约 90.8 cm 候选尺寸 · 稳定节段包壳，关节活动区裸露

正面侧面斜侧面显示臂壳显示占位件只看肩部左肩扭转细节重置

拖动旋转 · 滚轮缩放 · 点击零件
实际 CAD＋注明的尺寸包络；完整走线和持姿仍在设计，未制造放行。

## 组合姿态检查

自然耸肩前伸侧举错开抱臂

承力框架候选分段臂壳轴、摩擦盘双臂摆姿需避让

这轮集成了什么

左右肩带各两轴、肩部各三轴，接上已有的两条肘臂架，共 12 个转轴参与检查。

左右扭转轴加入 12 × 10 mm 测角板、一体金属轴杯、可拆夹盖与下端 D 形防滑接口。加上已有外展测角，目前每款有四处肩部测角安装候选。人物比例与关节中心保持。按最新要求，人偶本体不依赖固定外部支架，外部支撑物暂不设计。

通过样本不代表完成制造

持姿力、夹紧后的回差、磁场质量和手感尚未实测。两路屈伸测角、肩带与扭转预紧、完整线束和全身集成仍待完成。小板已通过电路规则检查，FPC 连接器是厂家尺寸包络，短排线是占位，尚未证明全行程走线。

左右两臂的相交保留为橙色摆姿限制；关节内部、同侧相邻肢段等结构冲突仍标红。错开抱臂仅证明当前局部 CAD 有一个可达候选，还未包括躯干表面、头和手。

点击零件查看所属运动节段与设计状态。

肩带结构与设计边界
全部检查结果
当前角色 STEP 总装

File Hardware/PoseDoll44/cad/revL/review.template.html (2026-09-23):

POSEDOLL 44 · REV L · SIX SHOULDER READOUTS

# 肩部细化：补齐屈伸测角安装

Manny / Quinn · 约 90.8 cm 候选尺寸 · 稳定节段包壳，关节活动区裸露

正面侧面斜侧面显示臂壳显示占位件只看肩部左肩屈伸细节重置

拖动旋转 · 滚轮缩放 · 点击零件
实际 CAD＋注明的尺寸包络；完整走线和持姿仍在设计，未制造放行。

## 组合姿态检查

自然耸肩前伸侧举错开抱臂

承力框架候选分段臂壳轴、摩擦盘双臂摆姿需避让

这轮集成了什么

左右肩带各两轴、肩部各三轴，接上已有的两条肘臂架，共 12 个转轴参与检查。

左右屈伸轴加入键接磁铁杯和可拆测角板，缩短向胸口延伸的轴端堆叠。加上已有外展、扭转，目前每款有六处肩部测角安装候选。人物比例与关节中心保持。按最新要求，人偶本体不依赖固定外部支架，外部支撑物暂不设计。

通过样本不代表完成制造

持姿力、夹紧后的回差、磁场质量和手感尚未实测。肩带测角、肩带与扭转预紧、完整线束和全身集成仍待完成。小板已通过电路规则检查，FPC 连接器是厂家尺寸包络，短排线是占位，尚未证明全行程走线。

左右两臂的相交保留为橙色摆姿限制；关节内部、同侧相邻肢段等结构冲突仍标红。错开抱臂仅证明当前局部 CAD 有一个可达候选，还未包括躯干表面、头和手。

点击零件查看所属运动节段与设计状态。

肩带结构与设计边界
全部检查结果
当前角色 STEP 总装

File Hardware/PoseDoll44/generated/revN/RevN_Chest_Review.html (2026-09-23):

POSEDOLL LAB / HARDWARE · REV N1

# 取消胸壳 · Manny 与 Quinn

胸部承重骨架保留 · 背部设备仍为原位 · 外置方案评估另列

数字设计候选 · 待实物验证

正在读取完整 CAD…

正面侧面背面斜侧面重置视角

拖动旋转 · 滚轮缩放 · 点击零件
胸口罩壳已取消；背部设备尚未外置。

## 角色

MannyQuinn

### 查看范围

外壳电子元件线束固定点

### 已列入检查的姿态

正在读取验证报告…

橙色表示非相邻身体部位接触，可调整姿势避让；相邻机构接触仍按结构问题处理。离散样本通过不代表全空间无碰撞。

摆姿需避让结构问题所选部件

### 整个人偶的朝向

以骨盆前方定义人偶前方。现实中的整体平移、竖起、平躺或侧躺不会改变输出；整体位置和所有整体旋转均在 UE 中调整。

### 当前部件

点击模型查看零件编号、所属节段和材质。

### 本次改动

胸壳改动与外置方案权衡

对比原 Rev M

原 164 姿态保留未改件证据，修改的左肩支座在全部样本重新求交；另有双手背后样本与肩轴逐度检查。外置架构尚无新 PCB、壳体或制造文件。

### 设计文件

下载总装 STEP

逐件清单 · 线束表

设计与测试入口 · 打印与制造说明

柔性导线的受力、磨损、磁场误差和持姿手感仍需实物测试。固定点显示不代表线束弹性仿真。

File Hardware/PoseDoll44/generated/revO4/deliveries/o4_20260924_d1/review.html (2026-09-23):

# PoseDoll O4 · 静态采集实验

摆好再采集：UE 快照功能已完成模拟端到端验证。硬件方案进入对照试验，整机尚未放行。

实体测试 NOT_RUN · PCB 未布线 · 完整胸肩 / 单臂未建成

## 14 芯与四芯：收益在哪

只减少 J50 这一段，其他肩部传感器线保留。六个逻辑区域、七个 CAN 节点、41 个测量轴不变；新增两颗远端 MCU 后共九个处理器。

板件 | PCB mm | 元件 | 含插头 / 代用体 mm | ERC | DRC / 未连线
A 近端 / 14 芯 | 36.00 × 48.00 × 1.20 | 98 | 36.00 × 53.95 × 12.50 | PASS | FAIL / 271
A 远端 26×30 | 26.00 × 30.00 × 1.20 | 47 | 26.00 × 30.00 × 8.38 | PASS | FAIL / 136
C 近端 / 四芯侧出线 | 36.00 × 48.00 × 1.20 | 96 | 36.00 × 54.67 × 12.50 | PASS | FAIL / 252
C 远端 26×30 / 侧出线 | 26.00 × 30.00 × 1.20 | 66 | 26.00 × 30.72 × 8.79 | PASS | FAIL / 171
C 远端 20×30 / 侧出线 | 20.00 × 30.00 × 1.20 | 66 | 20.00 × 30.72 × 8.79 | PASS | FAIL / 171
C 远端 20×30 / 顶出线 | 20.00 × 30.00 × 1.20 | 66 | 20.00 × 30.00 × 8.79 | PASS | FAIL / 171

## 原生布局与包络投影

KiCad 元件轮廓和包络的平面投影，不是完整三维装配。黄色表示插头、弯线或拔插需求；蓝 / 红分别为正反面器件轮廓；虚线为缺少实体轮廓时的 courtyard，圆点只表示焊盘位置。R4 / R12 仅作敏感性比较，未验证线材弯曲寿命。

## 时间与供电

请求 68 B + 响应 80 B，在 115200 8N1 下仅串行发送需 12.847 ms。保留五项寄存器诊断，四轴读取加假定的 2 ms 调度 / 换向共约 17.527 ms；全 41 轴加两段串行链路保守相加约 57.164 ms。尚未包含 CAN、网关、USB 和操作系统延迟。

3.3 V 供电采用低端容差、线长、线径、温度和 100 / 200 / 250 mA 的敏感性计算。36 组中 4 组远端低于传感器 3.0 V 下限，最低约 2.951 V。100 kΩ 限流电阻的理论触发范围约 232–306 mA，250 mA 档还可能提前限流。四芯供电尚未合格。

降低采集频率不会自动让持续供电的磁编码器更省电。休眠、上电稳定时间和断电反灌须单独验证。

## 整条手臂仍有什么缺口

两角色各 24 个板件 / 弯线 / 位置筛查均存在包络或关节预留余量失败。这是采样包络筛查，不能替代真实胸肩和带线九轴单臂。四芯顶出线远端板更紧凑，但近端侧出线和拔插空间抵消了一部分收益。

外耳止挡名义反向空程约 0.6504°，不是编码器误差。前截面槽角到外壁径向剩余约 0.6485 mm；加厚到半径 16 mm 可变为约 1.6485 mm，但不能据此判定中断螺纹强度通过。收紧配合可能引入公差干涉与受载卡滞；结合、输出夹持和完整反向扭矩链仍需验证。

## 证据范围

硬件输入：b2c54e3；新运行 o4_20260924_h3。原 O3、91 cm 备用和旧时序结论保留。PASS 只表示所注明的执行或局部检查范围，不代表制造放行。

硬件原始比较 · 运行与输入哈希 · 完整交付说明

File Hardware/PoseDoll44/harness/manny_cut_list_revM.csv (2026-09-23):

id | kind | from_connector | to_connector | cut_length_each_mm | wires | wire | housing_both_ends | contact
S03 | sensor | N1.J11 | waist.yaw.J1 | 300 | 6 | Alpha 2841/7 AWG30 7/38 PTFE OD0.61 | SHR-06V-S | SSH-003T-P0.2-H
S04 | sensor | N1.J12 | waist.pitch.J1 | 440 | 6 | Alpha 2841/7 AWG30 7/38 PTFE OD0.61 | SHR-06V-S | SSH-003T-P0.2-H
S05 | sensor | N1.J13 | waist.roll.J1 | 450 | 6 | Alpha 2841/7 AWG30 7/38 PTFE OD0.61 | SHR-06V-S | SSH-003T-P0.2-H
S06 | sensor | N2.J11 | chest.yaw.J1 | 370 | 6 | Alpha 2841/7 AWG30 7/38 PTFE OD0.61 | SHR-06V-S | SSH-003T-P0.2-H
S07 | sensor | N2.J12 | chest.pitch.J1 | 370 | 6 | Alpha 2841/7 AWG30 7/38 PTFE OD0.61 | SHR-06V-S | SSH-003T-P0.2-H
S08 | sensor | N2.J13 | chest.roll.J1 | 350 | 6 | Alpha 2841/7 AWG30 7/38 PTFE OD0.61 | SHR-06V-S | SSH-003T-P0.2-H
S09 | sensor | N2.J14 | head.yaw.J1 | 310 | 6 | Alpha 2841/7 AWG30 7/38 PTFE OD0.61 | SHR-06V-S | SSH-003T-P0.2-H
S10 | sensor | N2.J15 | head.pitch.J1 | 450 | 6 | Alpha 2841/7 AWG30 7/38 PTFE OD0.61 | SHR-06V-S | SSH-003T-P0.2-H
S11 | sensor | N2.J16 | head.roll.J1 | 450 | 6 | Alpha 2841/7 AWG30 7/38 PTFE OD0.61 | SHR-06V-S | SSH-003T-P0.2-H
S12 | sensor | N3.J11 | clavicle_l.protract.J1 | 270 | 6 | Alpha 2841/7 AWG30 7/38 PTFE OD0.61 | SHR-06V-S | SSH-003T-P0.2-H
S13 | sensor | N3.J12 | clavicle_l.elevate.J1 | 440 | 6 | Alpha 2841/7 AWG30 7/38 PTFE OD0.61 | SHR-06V-S | SSH-003T-P0.2-H
S14 | sensor | N3.J13 | upperarm_l.flex.J1 | 390 | 6 | Alpha 2841/7 AWG30 7/38 PTFE OD0.61 | SHR-06V-S | SSH-003T-P0.2-H
S15 | sensor | N3.J14 | upperarm_l.abduct.J1 | 480 | 6 | Alpha 2841/7 AWG30 7/38 PTFE OD0.61 | SHR-06V-S | SSH-003T-P0.2-H
S16 | sensor | N3.J15 | upperarm_l.twist.J1 | 450 | 6 | Alpha 2841/7 AWG30 7/38 PTFE OD0.61 | SHR-06V-S | SSH-003T-P0.2-H
S17 | sensor | N3.J16 | elbow_l.flex.J1 | 580 | 6 | Alpha 2841/7 AWG30 7/38 PTFE OD0.61 | SHR-06V-S | SSH-003T-P0.2-H
S18 | sensor | N3.J17 | forearm_l.twist.J1 | 650 | 6 | Alpha 2841/7 AWG30 7/38 PTFE OD0.61 | SHR-06V-S | SSH-003T-P0.2-H
S19 | sensor | N3.J18 | hand_l.flex.J1 | 770 | 6 | Alpha 2841/7 AWG30 7/38 PTFE OD0.61 | SHR-06V-S | SSH-003T-P0.2-H
S20 | sensor | N3.J19 | hand_l.deviate.J1 | 870 | 6 | Alpha 2841/7 AWG30 7/38 PTFE OD0.61 | SHR-06V-S | SSH-003T-P0.2-H
S28 | sensor | N4.J11 | clavicle_r.protract.J1 | 250 | 6 | Alpha 2841/7 AWG30 7/38 PTFE OD0.61 | SHR-06V-S | SSH-003T-P0.2-H
S29 | sensor | N4.J12 | clavicle_r.elevate.J1 | 440 | 6 | Alpha 2841/7 AWG30 7/38 PTFE OD0.61 | SHR-06V-S | SSH-003T-P0.2-H
S30 | sensor | N4.J13 | upperarm_r.flex.J1 | 380 | 6 | Alpha 2841/7 AWG30 7/38 PTFE OD0.61 | SHR-06V-S | SSH-003T-P0.2-H
S31 | sensor | N4.J14 | upperarm_r.abduct.J1 | 480 | 6 | Alpha 2841/7 AWG30 7/38 PTFE OD0.61 | SHR-06V-S | SSH-003T-P0.2-H
S32 | sensor | N4.J15 | upperarm_r.twist.J1 | 450 | 6 | Alpha 2841/7 AWG30 7/38 PTFE OD0.61 | SHR-06V-S | SSH-003T-P0.2-H
S33 | sensor | N4.J16 | elbow_r.flex.J1 | 580 | 6 | Alpha 2841/7 AWG30 7/38 PTFE OD0.61 | SHR-06V-S | SSH-003T-P0.2-H
S34 | sensor | N4.J17 | forearm_r.twist.J1 | 650 | 6 | Alpha 2841/7 AWG30 7/38 PTFE OD0.61 | SHR-06V-S | SSH-003T-P0.2-H
S35 | sensor | N4.J18 | hand_r.flex.J1 | 780 | 6 | Alpha 2841/7 AWG30 7/38 PTFE OD0.61 | SHR-06V-S | SSH-003T-P0.2-H
S36 | sensor | N4.J19 | hand_r.deviate.J1 | 870 | 6 | Alpha 2841/7 AWG30 7/38 PTFE OD0.61 | SHR-06V-S | SSH-003T-P0.2-H
S21 | sensor | N5.J11 | thigh_l.flex.J1 | 300 | 6 | Alpha 2841/7 AWG30 7/38 PTFE OD0.61 | SHR-06V-S | SSH-003T-P0.2-H
S22 | sensor | N5.J12 | thigh_l.abduct.J1 | 370 | 6 | Alpha 2841/7 AWG30 7/38 PTFE OD0.61 | SHR-06V-S | SSH-003T-P0.2-H
S23 | sensor | N5.J13 | thigh_l.twist.J1 | 380 | 6 | Alpha 2841/7 AWG30 7/38 PTFE OD0.61 | SHR-06V-S | SSH-003T-P0.2-H
S24 | sensor | N5.J14 | calf_l.flex.J1 | 540 | 6 | Alpha 2841/7 AWG30 7/38 PTFE OD0.61 | SHR-06V-S | SSH-003T-P0.2-H
S25 | sensor | N5.J15 | foot_l.dorsiflex.J1 | 800 | 6 | Alpha 2841/7 AWG30 7/38 PTFE OD0.61 | SHR-06V-S | SSH-003T-P0.2-H
S26 | sensor | N5.J16 | foot_l.invert.J1 | 870 | 6 | Alpha 2841/7 AWG30 7/38 PTFE OD0.61 | SHR-06V-S | SSH-003T-P0.2-H
S27 | sensor | N5.J17 | ball_l.flex.J1 | 910 | 6 | Alpha 2841/7 AWG30 7/38 PTFE OD0.61 | SHR-06V-S | SSH-003T-P0.2-H
S37 | sensor | N6.J11 | thigh_r.flex.J1 | 300 | 6 | Alpha 2841/7 AWG30 7/38 PTFE OD0.61 | SHR-06V-S | SSH-003T-P0.2-H
S38 | sensor | N6.J12 | thigh_r.abduct.J1 | 370 | 6 | Alpha 2841/7 AWG30 7/38 PTFE OD0.61 | SHR-06V-S | SSH-003T-P0.2-H
S39 | sensor | N6.J13 | thigh_r.twist.J1 | 380 | 6 | Alpha 2841/7 AWG30 7/38 PTFE OD0.61 | SHR-06V-S | SSH-003T-P0.2-H
S40 | sensor | N6.J14 | calf_r.flex.J1 | 540 | 6 | Alpha 2841/7 AWG30 7/38 PTFE OD0.61 | SHR-06V-S | SSH-003T-P0.2-H
S41 | sensor | N6.J15 | foot_r.dorsiflex.J1 | 800 | 6 | Alpha 2841/7 AWG30 7/38 PTFE OD0.61 | SHR-06V-S | SSH-003T-P0.2-H
S42 | sensor | N6.J16 | foot_r.invert.J1 | 880 | 6 | Alpha 2841/7 AWG30 7/38 PTFE OD0.61 | SHR-06V-S | SSH-003T-P0.2-H
S43 | sensor | N6.J17 | ball_r.flex.J1 | 910 | 6 | Alpha 2841/7 AWG30 7/38 PTFE OD0.61 | SHR-06V-S | SSH-003T-P0.2-H
C1 | can | N6.J3 | N1.J2 | 230 | 3 | Alpha 5851 AWG30 PTFE OD0.81; twist H/L together, 20 mm pitch | GHR-03V-S | SSHL-002T-P0.2
C2 | can | N1.J3 | N5.J2 | 230 | 3 | Alpha 5851 AWG30 PTFE OD0.81; twist H/L together, 20 mm pitch | GHR-03V-S | SSHL-002T-P0.2
C3 | can | N5.J3 | N3.J2 | 610 | 3 | Alpha 5851 AWG30 PTFE OD0.81; twist H/L together, 20 mm pitch | GHR-03V-S | SSHL-002T-P0.2
C4 | can | N3.J3 | N2.J2 | 230 | 3 | Alpha 5851 AWG30 PTFE OD0.81; twist H/L together, 20 mm pitch | GHR-03V-S | SSHL-002T-P0.2
C5 | can | N2.J3 | N4.J2 | 230 | 3 | Alpha 5851 AWG30 PTFE OD0.81; twist H/L together, 20 mm pitch | GHR-03V-S | SSHL-002T-P0.2
P1 | power | POWER.J2 | N1.J1 | 300 | 2 | Alpha 3049 AWG26 7/34 PVC OD1.30 | PHR-2 | SPH-002T-P0.5S
P2 | power | POWER.J3 | N2.J1 | 550 | 2 | Alpha 3049 AWG26 7/34 PVC OD1.30 | PHR-2 | SPH-002T-P0.5S
P3 | power | POWER.J4 | N3.J1 | 560 | 2 | Alpha 3049 AWG26 7/34 PVC OD1.30 | PHR-2 | SPH-002T-P0.5S
P4 | power | POWER.J5 | N4.J1 | 560 | 2 | Alpha 3049 AWG26 7/34 PVC OD1.30 | PHR-2 | SPH-002T-P0.5S
P5 | power | POWER.J6 | N5.J1 | 310 | 2 | Alpha 3049 AWG26 7/34 PVC OD1.30 | PHR-2 | SPH-002T-P0.5S
P6 | power | POWER.J7 | N6.J1 | 310 | 2 | Alpha 3049 AWG26 7/34 PVC OD1.30 | PHR-2 | SPH-002T-P0.5S

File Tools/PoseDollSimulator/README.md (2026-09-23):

# Hardware compatibility snapshot

This folder contains only the protocol/kinematics/diagnostics/transport Python modules and their existing tests used by the hardware project. It does not contain the simulator GUI or its environment. The running simulator remains in the original DollSimulation project.

Provenance and byte hashes: [software_snapshot.json](../../docs/software_snapshot.json). Keep the existing folder layout because profile lookup and historical checks depend on it. Do not silently overwrite this snapshot when updating the UE project; compare protocol/profile hashes and rerun the hardware offline tests.

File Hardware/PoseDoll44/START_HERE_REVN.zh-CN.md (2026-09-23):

# Rev N1 · 胸口取消罩壳与背部外置评估

**已实施：两款人偶取消胸口罩壳、两颗螺钉和两颗螺母。** 胸部承重骨架和所有关节中心保持 Rev M，另修正左肩支座与旋转限位拨片的局部刮碰；各有 186 个打印件。背部仍保留原六个电子仓，外置方案是待重新布局的架构建议。

- [打开新三维查看器](http://127.0.0.1:8874/generated/revN/RevN_Chest_Review.html) · [本地 HTML](generated/revN/RevN_Chest_Review.html)
- [胸壳改动、接触减少数据与外置方案利弊](docs/CHEST_AND_EXTERNAL_REVN.zh-CN.md)
- [Manny 修订总装 STEP](generated/revN/manny/Manny_RevN1_assembly.step) · [Quinn 修订总装 STEP](generated/revN/quinn/Quinn_RevN1_assembly.step)
- [Manny 当前制造清单](generated/revN/manny/manufacturing_manifest.json) · [Quinn 当前制造清单](generated/revN/quinn/manufacturing_manifest.json)
- [碰撞复核记录](verification/revN_chest_audit.json) · [本轮文件清单](generated/revN/delivery_manifest.json)
- [原完整装配、电路和校准资料](START_HERE.zh-CN.md)（剔除取消的 5 件，左肩支座使用 N1 图纸）

新查看器增加双手背后姿态，并保留仍存在的后背设备干涉。不要把该姿态或外置方案理解成已经制造验证。无需现在采购或打印。

本轮 CAD 入口为 [chest_clearance.py](cad/revN/chest_clearance.py)。原版完整交付清单是 Rev M 时点的快照；当前入口提示的文字更新不会改变其几何文件。

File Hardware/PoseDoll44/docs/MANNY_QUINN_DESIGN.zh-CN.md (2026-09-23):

# Manny / Quinn 双角色比例设计 · Rev E

两款都以本地项目中的实际角色为依据，统一缩小至 **1:3**。当前交付是两套已纠正比例的 44 轴运动设计基准、STEP 参考布局和外形对照模型；承力、摩擦、传感器等机构仍需围绕这些基准完成集成。

[打开可旋转的 3D 比较页](../generated/revE/Manny_Quinn_3D_Review.html) · [当前工程入口](../START_HERE.zh-CN.md) · [验证报告](../verification/REVE_REPORT.zh-CN.md)

Manny 与 Quinn 的比例对照

## 尺寸以什么为准

Manny 使用 `/Game/Characters/Mannequins/Meshes/SKM_Manny_Simple`，Quinn 使用同目录的 `SKM_Quinn_Simple`。提取对象是各自网格的参考骨架和蒙皮数据，避免共享 Skeleton / Control Rig 的默认尺寸覆盖角色实际差异。测量时转换到与既有姿势适配器一致的 N 中立姿势，保持每根骨骼长度，以实际参考表面最低点为地面，再应用统一缩放。

1:3 是当前设计选定值；两款中立高度均约 605 mm，不含支架和突出电子件。原来的约 500 mm 仅为探索目标。本次优先保留实际身体比例，后续机构尺寸不足时需重新设计机构或整体缩放，不能单独拉长手臂、撑宽肩膀。

| 项目（mm） | Manny | Quinn |
|---|---:|---:|
| 中立脚底至头顶 | 605.3 | 605.1 |
| 上臂：肩中心→肘中心 | 92.6 | 90.3 |
| 前臂：肘中心→腕中心 | 90.8 | 87.0 |
| 手腕→指端参考点 | 60.8 | 59.4 |
| 肩→肘→腕→指端的分段长度之和 | 244.2 | 236.7 |
| 大腿：髋中心→膝中心 | 144.5 | 152.5 |
| 小腿：膝中心→踝中心 | 140.7 | 139.0 |
| 左右肩中心间距 | 126.7 | 107.0 |
| 左右髋中心间距 | 66.5 | 74.4 |
| 骨盆→肩中心的竖直高度 | 159.0 | 147.1 |
| 头部参考宽度 | 59.0 | 54.2 |
| 头部参考高度 | 87.7 | 80.1 |
| 脚部参考长度 | 90.1 | 89.6 |
| 脚部参考宽度 | 35.3 | 35.5 |

表中四肢取左侧；源文件保留左右原始数值。头、手、脚区域由顶点的主要骨骼权重分组，指端使用参考手型下最末端的网格点。肩到指端一行是分段长度之和，不是所有姿势下的直线距离。手指不在 44 路输入内，实体握持件尚未设计。

Manny 的肩到腕分段长度/身高约 **0.303**；Quinn 约 **0.293**。这些来自各自角色，不能用一套固定臂长替换。

## 机械设计如何服从比例

肩部三个轴以实际肩关节中心为交点，髋部同理；手腕、脚踝的两个轴也以对应中心为交点。旧 Rev C 肩部两个轴相隔 56 mm 的结构不能直接沿用。前臂旋转轴放在肘腕连线上，不额外增加前臂长度。

腰部、胸部和颈部目前使用等效转动中心表示 UE 的多骨骼运动。中立姿势标志点已对齐，但颈部动态位置仍有误差，详见验证报告。当前共心颈部方案没有获得动态设计放行；不得为了让检查通过而缩小已承诺的关节角度范围或放宽阈值。

下列原则已经落实到两份物理参数文件：44 个轴 ID、顺序、方向及协议保持一致；人物尺寸、关节位置、参考表面和独立 profile_id 分别保存。已有 `virtual_humanoid_44_v1`、模拟器和 UE 插件没有为了适应机械件而被修改。

| 组成部分 | 双版本处理方式 |
|---|---|
| 角度传感器板、电气接口、44 轴协议 | 共用已设计的接口，整机安装仍须验证 |
| 持姿关节的基本结构 | 尽量共用；规格需按每款最终质量与力臂选型 |
| 上臂、前臂、大腿、小腿的结构长度 | 分别取各自角色尺寸 |
| 肩带、骨盆和躯干连接结构 | 按不同肩宽、髋宽、躯干长度分别设计 |
| 头、手、脚及握持外壳 | 各自参考角色外形，后续转换为可装配结构 |
| 校准、实体设备配置、UE 目标角色配置 | 两款独立绑定，不能只依据“同为 44 轴”混用 |

## 文件与使用

- [Manny STEP 关节布局](../generated/revE/manny/Manny_44_proportion_layout.step) / [Manny 参数](../mechanical_manifest/physical_manny_44_revE_proportion.json)
- [Quinn STEP 关节布局](../generated/revE/quinn/Quinn_44_proportion_layout.step) / [Quinn 参数](../mechanical_manifest/physical_quinn_44_revE_proportion.json)
- [CQ-editor 入口](../cad/revE/open_in_cq_editor.py)：`CHARACTER` 选 `BOTH`、`MANNY` 或 `QUINN`，`POSE` 选已有样本。
- [两款设计登记表](../mechanical_manifest/dual_character_design_revE.json) / [比例约束](../mechanical_manifest/proportion_constraints_revE.json)
- [重建方法](BUILD_REVE.zh-CN.md) / [Quinn 适配待办](QUINN_ADAPTER_HANDOFF.zh-CN.md)

STEP 中的杆、点和轴线都是设计参考几何，不是实际轴、轴承或连接件。PLY/NPZ/网页中的身体表面是 UE 角色的比例参照，不是可打印外壳。Rev C / Rev D 的旧关节研究件继续保留，但不得直接作为新比例的全身总装。

后续继续按 A1 mini、0.4 mm 喷嘴、PLA 做分件设计。当前不用打印试片、测量或采购；各零件是否适合打印空间，要在实际零件完成后逐件检查。

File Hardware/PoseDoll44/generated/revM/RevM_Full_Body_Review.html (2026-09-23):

POSEDOLL LAB / HARDWARE · REV M

# Manny 与 Quinn 完整人偶

1:2 人物比例 · 41 个测量轴 · 稳定躯段包壳，活动区域外露

数字设计候选 · 待实物验证

正在读取完整 CAD…

正面侧面背面斜侧面重置视角

拖动旋转 · 滚轮缩放 · 点击零件
模型按机械设计尺寸显示；无外部支架。

## 角色

MannyQuinn

### 查看范围

外壳电子元件线束固定点

### 已列入检查的姿态

正在读取验证报告…

橙色表示非相邻身体部位接触，可调整姿势避让；相邻机构接触仍按结构问题处理。离散样本通过不代表全空间无碰撞。

摆姿需避让结构问题所选部件

### 整个人偶的朝向

以骨盆前方定义人偶前方。现实中的整体平移、竖起、平躺或侧躺不会改变输出；整体位置和所有整体旋转均在 UE 中调整。

### 当前部件

点击模型查看零件编号、所属节段和材质。

### 设计文件

下载总装 STEP

逐件清单 · 线束表

设计与测试入口 · 打印与制造说明

柔性导线的受力、磨损、磁场误差和持姿手感仍需实物测试。固定点显示不代表线束弹性仿真。

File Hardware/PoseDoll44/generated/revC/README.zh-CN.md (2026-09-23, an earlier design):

# Rev C 生成文件

这是设计候选文件目录。全身运动模型和 H2 独立摩擦夹具是两个不同的验证对象，尚未合并为完整可制造装配。

请先阅读 [当前入口](../../START_HERE.zh-CN.md) 和 [数字审查](../../verification/REVC_REPORT.zh-CN.md)。不要求现在打印任何文件。

`step/HW44_revC_candidate.step` 是全身运动结构；`H2/S`、`H2/M`、`H2/L` 是分别检查摩擦和装配的研究件。各自的 STL 不能混用，也不能直接拼成完整人偶。`history` 中保留已弃用迭代的图片。

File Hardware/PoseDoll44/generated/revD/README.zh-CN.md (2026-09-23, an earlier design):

# Rev D 进行中的机构研究

当前仅有三规格紧凑关节的首轮 CAD，不是全身等比例模型，也不是打印放行包。

- 旋转动静件样本无穿插，但传感器托架的圆杆截面与垫片存在未修复相交，见 [逐件结果](../../verification/revD_compact_modules.json)。
- 初轮质量约 S 71 g / M 90 g / L 125 g，不能据此沿用 Rev C 的 2.01 kg 全身质量预算。
- 用户指出的体格比例要求优先处理：先固定按 Manny 统一缩放的关节中心、肢体比例和运动误差目标，再决定这些机构能否使用及如何安装。
- 当前没有完成整机安装、完整负载重算或电子节点设计。无需用户打印或测量。

[比例核对报告](../../verification/PROPORTION_AUDIT.zh-CN.md) · [最新入口](../../START_HERE.zh-CN.md)

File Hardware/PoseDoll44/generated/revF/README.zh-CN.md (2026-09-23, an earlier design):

# Rev F 文件目录

当前是按新比例建立的机械集成候选，尚未制造放行。

- [可旋转的机械查看页](RevF_Mechanical_Review.html)
- [CQ-editor 入口](../../cad/revF/open_in_cq_editor.py)
- [Manny 左臂部分总装](variants/manny/Manny_arm_packaging.step)
- [Quinn 左臂部分总装](variants/quinn/Quinn_arm_packaging.step)
- [S6 独立叉架](joints/J_S6/RevF_J_S6.step) · [M6](joints/J_M6/RevF_J_M6.step) · [H6](joints/J_H6/RevF_J_H6.step) · [L8](joints/J_L8/RevF_J_L8.step)
- 摩擦端与测角端组件：`joints/S6`、`M6`、`H6`、`L8`、`E6`、`E8`，各含组件 STEP 和部分独立零件 STEP。
- 两款独立连接件位于各自 `variants` 文件夹：`upperarm_datum_link.step`、`forearm_return_link.step`。

每款手臂只有肘屈伸、腕屈伸两轴已装入；顶部为临时肩部集成接口。其余转轴、完整手部、右侧和全身机构尚未完成。

[完整结构说明](../../docs/FORK_JOINT_REVF.zh-CN.md) · [验证报告](../../verification/REVF_REPORT.zh-CN.md) · [重建方法](../../docs/BUILD_REVF.zh-CN.md)

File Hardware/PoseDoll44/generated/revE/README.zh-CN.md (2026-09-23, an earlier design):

# Rev E 输出目录

这里是 Manny / Quinn 两套等比例关节布局及角色参考表面。

[可旋转 3D 比较页](Manny_Quinn_3D_Review.html) · [设计说明](../../docs/MANNY_QUINN_DESIGN.zh-CN.md) · [检查报告](../../verification/REVE_REPORT.zh-CN.md)

STEP 是关节中心和连线参考模型；PLY、NPZ、图片与网页表面用于尺寸和姿势对照。制造零件、支架、摩擦与测角机构仍须集成，未提供整机打印放行。

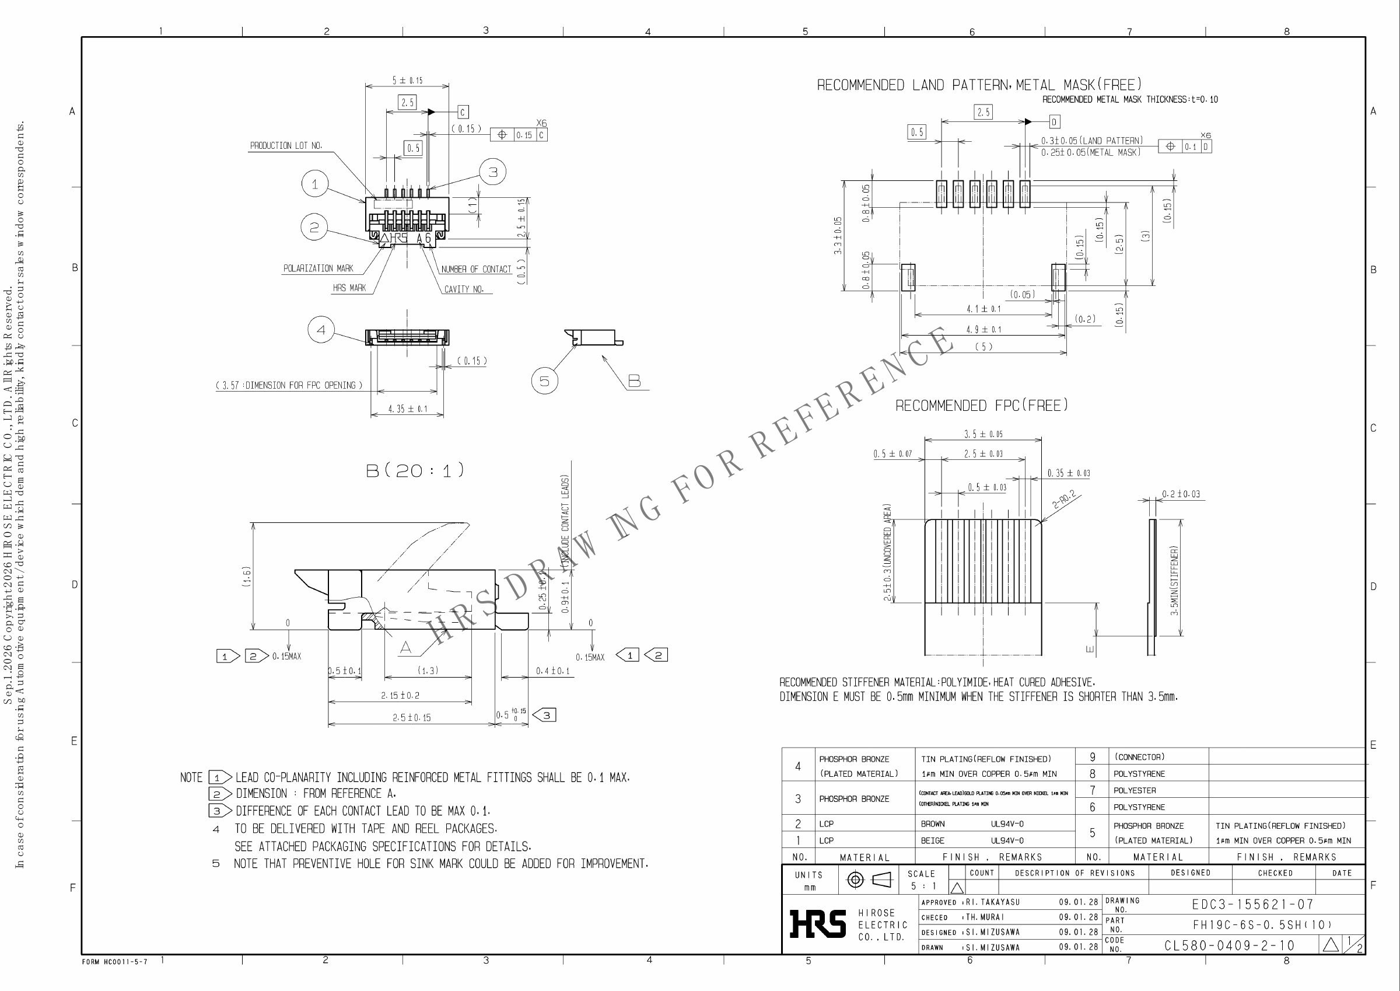
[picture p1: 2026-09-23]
Hardware/PoseDoll44/references/revK/FH19C_drawing-1.png

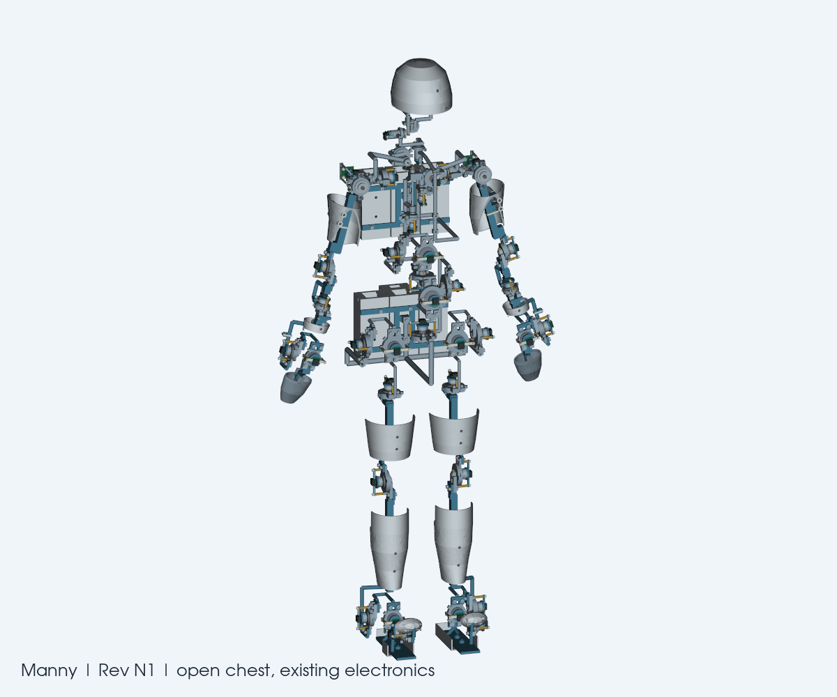
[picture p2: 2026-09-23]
Hardware/PoseDoll44/generated/revN/manny/front.png

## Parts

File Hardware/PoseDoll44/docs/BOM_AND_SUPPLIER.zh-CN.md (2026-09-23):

> **历史文件（Rev A / H1），不用于当前整机采购。** Rev M 的采购/加工清单与四种 PCBA 请从 [当前交付入口](../START_HERE.zh-CN.md) 进入。

# 小量物料与供应商核对单

**候选/询价文件，尚未采购放行。** 无供应商对 PCB 修订、代焊线束与定制五金的书面确认；完整总价未确定。当前无需买齐 44 套。

| 项目 | 确切候选与条件 | 首批规划数量 | 用途 |
|---|---|---:|---|
| 传感器套件 | Infineon/ams AS5048A-TS_EK_AB，A/SPI；提供实物修订图及排针代焊 | 4 | H1 一颗，H2 再两颗，一颗备用 |
| 配套磁铁 | 套件内 AS5000-MD6H-2；设计候选 Ø6×2.5 mm、径向充磁，需核对当前套件 | 4 | 不能替换成轴向充磁 |
| MCU | Espressif ESP32-S3-DevKitC-1-N8R8，排针已焊 | 2 | H1 用一块，另一块留节点/网关台架；PSRAM 未启用 |
| CAN 板 | Waveshare SN65HVD230 CAN Board，SKU3945 | 2 | 后续台架；先核对终端电阻和针脚，不接入当前 H1 |
| 数据 USB 线 | 匹配实际到货板接口、支持数据 | 2 | 不能只充电 |
| H1 预制线束 | 工单指定，≤150 mm；六信号/电源，官方模块需专用 8Pin 端 | 1 | 已焊、绝缘、应力释放、逐线导通记录 |

[套件目录](https://www.mouser.cn/ProductDetail/Infineon-Technologies/AS5048A-TS_EK_AB?qs=Rt6VE0PE%2FOd5D%2Fkw9O7ofA%3D%3D)、
[MCU 官方资料](https://documentation.espressif.com/esp-dev-kits/en/latest/esp32s3/esp32-s3-devkitc-1/user_guide_v1.1.html)、
[CAN 板](https://www.waveshare.com/product/sn65hvd230-can-board.htm)。

2026-09-20 检索到的套件分销目录缓存曾显示单套约 ¥149.63 含税；**不是实时可下单报价**。四套算术小计 ¥598.52，其他项目、代焊、运费和税差未报价，无法给出可批准的总价。也可在型号与版本确认后先购一颗做 H1。

## 未来试片复用实际装配件

**当前不要求采购或测试。** 用户已要求先完成设计，后做实物测试。设计端根据 [暂定依据](DESIGN_BASIS.zh-CN.md)继续选型，不等待用户提供测量。

Rev B H1-001 的五行依次使用最终选定的 M2 / M3 / M4 / M6 螺丝和外径 10 mm 的 POM 轴套；H1-002 使用普通 M3 六角螺母及选定磁铁。测试物复用实际装配件，不额外购买四根圆棒。实际螺丝款式和长度由后续工单确定，不能仅凭 M3/M6 名义数字自行替代。

M6 打印通孔已改为 6.8 mm；黄铜套的金属内孔仍为设计尺寸 6.4 mm。POM 和磁铁的定位配合单独设计，不能套用螺丝通孔余量。旧四行试片不再作为当前必做任务。详见 [未来测量模板](MEASUREMENT_RECORD.zh-CN.md)。

## 自制 PCB：另一条原型路径

本次 KiCad 是自制 32×32 mm、2层、名义厚 1.6 mm 的传感器原型板，孔位与 H1-017 一致。它与上表商城评估板不能混用外形或插头。

| 位号 | 设计器件 | 每板 |
|---|---|---:|
| U1 | AS5048A-HTSP-500，TSSOP14 4.4×5 mm，脚距0.65 | 1 |
| J1 | JST SM06B-GHS-TB，匹配 GHR-06V-S 壳及合适接触件 | 1 |
| C1 | 100 nF，X7R，≥16V，0603 | 1 |
| C2 | 10 µF，X7R，≥10V，0805，实际偏压容量待核对 | 1 |
| R1 | 33Ω，0603，1% | 1 |
| R2 | 10kΩ，0603，1% | 1 |

C/R 厂商料号、贴装服务、首次供电和信号完整性尚未冻结，因此未出 Gerber 下单包。要求代工完整贴装、接口焊接、限流上电、导通与读数记录；用户只插接合格板。

## 单轴机械工单候选

这些是**设计尺寸**，不是已找到同尺寸现货的声明。供应商按图制造和检验，用户不切金属、不钻轴套。

| 项目 | 名义尺寸 / 数量 | 待确认 |
|---|---|---|
| 黄铜固定套 | OD8 / ID6.4 / L31 mm，1件 | 同轴、端面、长度公差 |
| POM 轴套 | OD10 / ID8.05 / L6 mm，2件 | 实际尺寸及打印孔配合 |
| 钢环 | OD32 / ID10.4 / t3，2件；t1.5，2件 | 平面度、去毛刺、厚度 |
| 无石棉摩擦环 | OD32 / ID10.4 / t1.5，2件 | 商品/材质未定，压缩、摩擦、磨耗待测 |
| 主螺栓 | M6×55，垫片/螺母，1组 | 等级、实际头部与邻磁影响 |
| 背柱长螺栓 | M3×90，2组 | 锁紧及净空；打印穿孔候选 3.8 mm |
| 底座/试验力臂紧固 | M4，数量与长度随安装方案确定 | 不额外购买作测试棒；打印通孔候选 4.8 mm |
| 托架螺钉 | M3×14，上下锁紧螺母，4组 | 端部和磁铁桥间隙 |
| 压紧螺钉 | M3，3组，长度待堆叠冻结 | 预紧、防松未放行 |
| 磁铁桥/止挡 | M3 各2组，长度待装配冻结 | 头部和工具空间 |
| PCB 紧固 | 黄铜盘头 M2×10，非铁磁螺母，4组 | 头高与扫角间隙 |
| 磁铁盖 | 非铁磁 M2，2组，长度待冻结 | 薄盖保持力、胶接 |

## 可交给供应商的询价文字

请按所附料号/图纸报价小量工程样品。电子板提供正反面照片、修订号、外形/安装尺寸、原理图和针脚说明；全部排针/线束代焊并检验。AS5048A 不接受 AS5048B、AS5600 或未知兼容芯片。磁铁提供尺寸及径向充磁说明。不得烧写传感器零点 OTP。定制五金按尺寸记录。逐项列单价、数量、代工、税、运费和交期；技术资料确认后再下单。

文字仅保存在本地，没有发送。替代品由设计端核对，不要求用户判断。

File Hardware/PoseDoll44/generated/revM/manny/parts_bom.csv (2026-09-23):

id | owner | material | role | quantity | volume_mm3 | STEP | note
l_yaw_bush_top | chest | pom | structural_concept | 1 | 154.55379218600356 | parts/l_yaw_bush_top.step | Machined POM-C plain sleeve. CAD is installed/compressed state; free OD is +0.030 +/-0.005 mm above nominal, housing bore +0.000..+0.010. Finish running bore after installation. No clutch axial preload. Pull-out and thermal qualification required.
l_yaw_bush_lower | chest | pom | structural_concept | 1 | 123.64303374880286 | parts/l_yaw_bush_lower.step | Machined POM-C plain sleeve. CAD is installed/compressed state; free OD is +0.030 +/-0.005 mm above nominal, housing bore +0.000..+0.010. Finish running bore after installation. No clutch axial preload. Pull-out and thermal qualification required.
l_elev_bush_27 | clavicle_l.protract_frame | pom | structural_concept | 1 | 92.73227531160211 | parts/l_elev_bush_27.step | Machined POM-C plain sleeve. CAD is installed/compressed state; free OD is +0.030 +/-0.005 mm above nominal, housing bore +0.000..+0.010. Finish running bore after installation. No clutch axial preload. Pull-out and thermal qualification required.
l_elev_bush_43 | clavicle_l.protract_frame | pom | structural_concept | 1 | 92.73227531160211 | parts/l_elev_bush_43.step | Machined POM-C plain sleeve. CAD is installed/compressed state; free OD is +0.030 +/-0.005 mm above nominal, housing bore +0.000..+0.010. Finish running bore after installation. No clutch axial preload. Pull-out and thermal qualification required.
l_yaw_carriage | clavicle_l.protract_frame | aluminum_7075 | structural_concept | 1 | 5420.450253883302 | parts/l_yaw_carriage.step | Machined yaw carriage, keyed D4 end and two original elevation bearings; bolt-on G4 reaction plate support; reamed press-fit sleeve seat, see retained_bushes manifest; reamed press-fit sleeve seat, see retained_bushes manifest
l_flex_bush_-36.5 | clavicle_l | pom | structural_concept | 1 | 108.06450409818179 | parts/l_flex_bush_-36.5.step | Machined POM-C plain sleeve. CAD is installed/compressed state; free OD is +0.030 +/-0.005 mm above nominal, housing bore +0.000..+0.010. Finish running bore after installation. No clutch axial preload. Pull-out and thermal qualification required.
l_flex_bush_-27.5 | clavicle_l | pom | structural_concept | 1 | 108.06450409818176 | parts/l_flex_bush_-27.5.step | Machined POM-C plain sleeve. CAD is installed/compressed state; free OD is +0.030 +/-0.005 mm above nominal, housing bore +0.000..+0.010. Finish running bore after installation. No clutch axial preload. Pull-out and thermal qualification required.
l_clavicle_output_frame | clavicle_l | aluminum_7075 | structural_concept | 1 | 7466.219322912576 | parts/l_clavicle_output_frame.step | Machined clavicle link, D4 middle key transfers elevation torque, M2 radial retainer; original shoulder centre preserved; reamed press-fit sleeve seat, see retained_bushes manifest; reamed press-fit sleeve seat, see retained_bushes manifest
l_abduct_bush_-20.5 | upperarm_l.flex_frame | pom | structural_concept | 1 | 77.27689609300177 | parts/l_abduct_bush_-20.5.step | Machined POM-C plain sleeve. CAD is installed/compressed state; free OD is +0.030 +/-0.005 mm above nominal, housing bore +0.000..+0.010. Finish running bore after installation. No clutch axial preload. Pull-out and thermal qualification required.
l_abduct_bush_20.5 | upperarm_l.flex_frame | pom | structural_concept | 1 | 108.06450409818177 | parts/l_abduct_bush_20.5.step | Machined POM-C plain sleeve. CAD is installed/compressed state; free OD is +0.030 +/-0.005 mm above nominal, housing bore +0.000..+0.010. Finish running bore after installation. No clutch axial preload. Pull-out and thermal qualification required.
l_flex_ring | upperarm_l.flex_frame | aluminum_7075 | structural_concept | 1 | 3827.037402435624 | parts/l_flex_ring.step | Rev J removable split metal drive hub; flange fixed with two M2 screws, nut pockets and tool relief; strain/creep not verified; 7075-T6 metal candidate required for reamed interference-fit radial bush seats; no PLA press-fit claim; reamed press-fit sleeve seat, see retained_bushes manifest; reamed press-fit sleeve seat, see retained_bushes manifest
l_abduct_ring_and_twist_seat | upperarm_l.abduct_frame | aluminum_7075 | structural_concept | 1 | 3538.294014831178 | parts/l_abduct_ring_and_twist_seat.step | Machined metal shoulder abduction ring and twist reaction face; top thrust face Z5.5, radial bush does not carry preload; integral positive travel stops; D6.04 nominal sleeve seat and captured D7.4 lower flange; outer friction contact radius increased to 10 mm
l_twist_bush | upperarm_l.abduct_frame | pom | structural_concept | 1 | 223.31565271886208 | parts/l_twist_bush.step | Flanged POM-C D6 sleeve, D4.06 running bore; D7.4 x0.8 flange trapped between lining top -9 and housing shoulder -8. Nominal axial float .2 mm.
l_twist_rotor_face | upperarm_l | aluminum_7075 | structural_concept | 1 | 620.1574205087352 | parts/l_twist_rotor_face.step | Positive D4 drive; axial spring force reacts into the fixed metal shoulder seat; integral travel tab reacts directly into bearing frame; outer friction contact radius increased to 10 mm
l_twist_lining | upperarm_l.abduct_frame | peek | structural_concept | 1 | 282.9868122537348 | parts/l_twist_lining.step | ; unfilled PEEK ring R3.15..10, dry contact candidate
l_arm_upperarm_shell_front | upperarm_l | shell | solid_concept | 1 | 6198.84831428299 | parts/l_arm_upperarm_shell_front.step | 1.8 mm partial rigid arm cover; two M2x20 through captive rear nuts into closed centreline rail lugs; front straight hex access, remove before servicing joints; pose clearance sampled digitally
l_arm_upperarm_shell_back | upperarm_l | shell | solid_concept | 1 | 12891.846331741643 | parts/l_arm_upperarm_shell_back.step | 1.8 mm partial rigid arm cover; two M2x20 through captive rear nuts into closed centreline rail lugs; front straight hex access, remove before servicing joints; pose clearance sampled digitally
r_yaw_bush_top | chest | pom | structural_concept | 1 | 154.55379218600356 | parts/r_yaw_bush_top.step | Machined POM-C plain sleeve. CAD is installed/compressed state; free OD is +0.030 +/-0.005 mm above nominal, housing bore +0.000..+0.010. Finish running bore after installation. No clutch axial preload. Pull-out and thermal qualification required.
r_yaw_bush_lower | chest | pom | structural_concept | 1 | 123.64303374880289 | parts/r_yaw_bush_lower.step | Machined POM-C plain sleeve. CAD is installed/compressed state; free OD is +0.030 +/-0.005 mm above nominal, housing bore +0.000..+0.010. Finish running bore after installation. No clutch axial preload. Pull-out and thermal qualification required.
r_elev_bush_27 | clavicle_r.protract_frame | pom | structural_concept | 1 | 92.73227531160211 | parts/r_elev_bush_27.step | Machined POM-C plain sleeve. CAD is installed/compressed state; free OD is +0.030 +/-0.005 mm above nominal, housing bore +0.000..+0.010. Finish running bore after installation. No clutch axial preload. Pull-out and thermal qualification required.
r_elev_bush_43 | clavicle_r.protract_frame | pom | structural_concept | 1 | 92.73227531160214 | parts/r_elev_bush_43.step | Machined POM-C plain sleeve. CAD is installed/compressed state; free OD is +0.030 +/-0.005 mm above nominal, housing bore +0.000..+0.010. Finish running bore after installation. No clutch axial preload. Pull-out and thermal qualification required.
r_yaw_carriage | clavicle_r.protract_frame | aluminum_7075 | structural_concept | 1 | 5420.450481341685 | parts/r_yaw_carriage.step | Machined yaw carriage, keyed D4 end and two original elevation bearings; bolt-on G4 reaction plate support; reamed press-fit sleeve seat, see retained_bushes manifest; reamed press-fit sleeve seat, see retained_bushes manifest
r_flex_bush_-36.5 | clavicle_r | pom | structural_concept | 1 | 108.06450409818183 | parts/r_flex_bush_-36.5.step | Machined POM-C plain sleeve. CAD is installed/compressed state; free OD is +0.030 +/-0.005 mm above nominal, housing bore +0.000..+0.010. Finish running bore after installation. No clutch axial preload. Pull-out and thermal qualification required.
r_flex_bush_-27.5 | clavicle_r | pom | structural_concept | 1 | 108.06450409818183 | parts/r_flex_bush_-27.5.step | Machined POM-C plain sleeve. CAD is installed/compressed state; free OD is +0.030 +/-0.005 mm above nominal, housing bore +0.000..+0.010. Finish running bore after installation. No clutch axial preload. Pull-out and thermal qualification required.
r_clavicle_output_frame | clavicle_r | aluminum_7075 | structural_concept | 1 | 7151.624709201116 | parts/r_clavicle_output_frame.step | Machined clavicle link, D4 middle key transfers elevation torque, M2 radial retainer; original shoulder centre preserved; reamed press-fit sleeve seat, see retained_bushes manifest; reamed press-fit sleeve seat, see retained_bushes manifest
r_abduct_bush_-20.5 | upperarm_r.flex_frame | pom | structural_concept | 1 | 77.27689609300175 | parts/r_abduct_bush_-20.5.step | Machined POM-C plain sleeve. CAD is installed/compressed state; free OD is +0.030 +/-0.005 mm above nominal, housing bore +0.000..+0.010. Finish running bore after installation. No clutch axial preload. Pull-out and thermal qualification required.
r_abduct_bush_20.5 | upperarm_r.flex_frame | pom | structural_concept | 1 | 108.06450409818177 | parts/r_abduct_bush_20.5.step | Machined POM-C plain sleeve. CAD is installed/compressed state; free OD is +0.030 +/-0.005 mm above nominal, housing bore +0.000..+0.010. Finish running bore after installation. No clutch axial preload. Pull-out and thermal qualification required.
r_flex_ring | upperarm_r.flex_frame | aluminum_7075 | structural_concept | 1 | 3827.041946137451 | parts/r_flex_ring.step | Rev J removable split metal drive hub; flange fixed with two M2 screws, nut pockets and tool relief; strain/creep not verified; 7075-T6 metal candidate required for reamed interference-fit radial bush seats; no PLA press-fit claim; reamed press-fit sleeve seat, see retained_bushes manifest; reamed press-fit sleeve seat, see retained_bushes manifest
r_abduct_ring_and_twist_seat | upperarm_r.abduct_frame | aluminum_7075 | structural_concept | 1 | 3537.340626127649 | parts/r_abduct_ring_and_twist_seat.step | Machined metal shoulder abduction ring and twist reaction face; top thrust face Z5.5, radial bush does not carry preload; integral positive travel stops; D6.04 nominal sleeve seat and captured D7.4 lower flange; outer friction contact radius increased to 10 mm
r_twist_bush | upperarm_r.abduct_frame | pom | structural_concept | 1 | 223.31565271886217 | parts/r_twist_bush.step | Flanged POM-C D6 sleeve, D4.06 running bore; D7.4 x0.8 flange trapped between lining top -9 and housing shoulder -8. Nominal axial float .2 mm.
r_twist_rotor_face | upperarm_r | aluminum_7075 | structural_concept | 1 | 620.1574205087362 | parts/r_twist_rotor_face.step | Positive D4 drive; axial spring force reacts into the fixed metal shoulder seat; integral travel tab reacts directly into bearing frame; outer friction contact radius increased to 10 mm
r_twist_lining | upperarm_r.abduct_frame | peek | structural_concept | 1 | 282.98681225373497 | parts/r_twist_lining.step | ; unfilled PEEK ring R3.15..10, dry contact candidate
r_arm_upperarm_shell_front | upperarm_r | shell | solid_concept | 1 | 6198.779965077366 | parts/r_arm_upperarm_shell_front.step | 1.8 mm partial rigid arm cover; two M2x20 through captive rear nuts into closed centreline rail lugs; front straight hex access, remove before servicing joints; pose clearance sampled digitally
r_arm_upperarm_shell_back | upperarm_r | shell | solid_concept | 1 | 12891.78337106259 | parts/r_arm_upperarm_shell_back.step | 1.8 mm partial rigid arm cover; two M2x20 through captive rear nuts into closed centreline rail lugs; front straight hex access, remove before servicing joints; pose clearance sampled digitally
l_flex_clutch_flanged_shaft | upperarm_l.flex_frame | aluminum_7075 | structural_concept | 1 | 2486.5737569435355 | parts/l_flex_clutch_flanged_shaft.step | Custom steel 6 mm journal; integral flange, inner D drive, outer D cap seat, two M3 blind threads; integral travel tab reacts directly into bearing frame
l_flex_clutch_keyed_lining | clavicle_l | peek | structural_concept | 1 | 352.38699863507384 | parts/l_flex_clutch_keyed_lining.step | 1 mm replaceable lining; coefficient and wear unqualified; inner radius 6.8 mm leaves a 0.3 mm radial clearance to protected inner travel tabs; unfilled machined PEEK candidate, dry contact; actual torque and creep must be qualified
l_flex_clutch_reaction_plate | clavicle_l | aluminum_7075 | structural_concept | 1 | 1856.160324750695 | parts/l_flex_clutch_reaction_plate.step | 3 mm steel reaction plate with keyed lining recess and two M3 frame mounts; spring thrust closes through plate; Rev L two M2 through pilot bores at +/-11.9 for separate brass sensor standoffs; 1.0 mm minimum radial ligament; integral positive travel stops; D14.50 x0.85 upper retaining counterbore, flat Z3.15
l_flex_clutch_radial_bush | clavicle_l | pom | structural_concept | 1 | 138.80021299272474 | parts/l_flex_clutch_radial_bush.step | POM radial guide, clear of thrust faces; press fit/retention pending; D14.40 x0.70 flange at Z3.20..3.90, captured below thrust washer Z4.00; 0.15 total nominal axial float
l_flex_clutch_thrust_washer | clavicle_l | thrust | structural_concept | 1 | 353.4291735288514 | parts/l_flex_clutch_thrust_washer.step | SKF dimension candidate; PTFE face towards rotating spring seat; washer retention pending
l_flex_clutch_spring_seat | upperarm_l.flex_frame | metal | structural_concept | 1 | 141.98427997899066 | parts/l_flex_clutch_spring_seat.step | Steel spring seat; thrust washer separates rotation from fixed reaction plate
l_flex_clutch_disc_spring_a | upperarm_l.flex_frame | spring | structural_concept | 1 | 49.74397807694075 | parts/l_flex_clutch_disc_spring_a.step | SCHNORR 002 200 dimensional candidate at catalog test height
l_flex_clutch_disc_spring_b | upperarm_l.flex_frame | spring | structural_concept | 1 | 49.74397807694075 | parts/l_flex_clutch_disc_spring_b.step | Opposed pair in series: force is not doubled
l_flex_clutch_keyed_stop_cap | upperarm_l.flex_frame | aluminum | structural_concept | 1 | 361.6983591114389 | parts/l_flex_clutch_keyed_stop_cap.step | Rev L aluminum stop cap retains original metal stop heights and adds outside D flat for magnet cup; local contact stress and fatigue unqualified
l_flex_clutch_outer_M3x8 | upperarm_l.flex_frame | titanium | structural_concept | 1 | 95.05001952736514 | parts/l_flex_clutch_outer_M3x8.step | Rev L M3x8 titanium Grade 5 button screw dimension candidate (Accu SSB-M3-8-TI5); cylindrical head envelope 5.7 x 1.65, 2 mm hex, strength/procurement not released
l_flex_clutch_drive_retainer_washer | upperarm_l.flex_frame | metal | structural_concept | 1 | 69.98683034034684 | parts/l_flex_clutch_drive_retainer_washer.step | Separate washer retains D drive in printed output hub
l_flex_clutch_inner_M3x8 | upperarm_l.flex_frame | fastener | structural_concept | 1 | 95.18858359197088 | parts/l_flex_clutch_inner_M3x8.step | M3x8 ISO7380-1 low-profile button screw, 1.65 mm nominal head height; independent output-hub retention, no spring adjustment
l_flex_clutch_mount_M3x10_0 | clavicle_l | fastener | structural_concept | 1 | 133.84172987360972 | parts/l_flex_clutch_mount_M3x10_0.step | Reaction plate to printed support; simplified thread
l_flex_clutch_mount_M3_nut_0 | clavicle_l | fastener | structural_concept | 1 | 51.09247186378846 | parts/l_flex_clutch_mount_M3_nut_0.step | Captured hex nut, accessible from inside of support
l_flex_clutch_mount_M3x10_1 | clavicle_l | fastener | structural_concept | 1 | 133.84172987360975 | parts/l_flex_clutch_mount_M3x10_1.step | Reaction plate to printed support; simplified thread
l_flex_clutch_mount_M3_nut_1 | clavicle_l | fastener | structural_concept | 1 | 51.092471863788454 | parts/l_flex_clutch_mount_M3_nut_1.step | Captured hex nut, accessible from inside of support
l_abduct_clutch_flanged_shaft | upperarm_l.abduct_frame | aluminum_7075 | structural_concept | 1 | 2260.379085885075 | parts/l_abduct_clutch_flanged_shaft.step | Custom steel 6 mm journal; integral flange, inner D drive, outer D cap seat, two M3 blind threads; integral travel tab reacts directly into bearing frame
l_abduct_clutch_keyed_lining | upperarm_l.flex_frame | peek | structural_concept | 1 | 352.3869986350729 | parts/l_abduct_clutch_keyed_lining.step | 1 mm replaceable lining; coefficient and wear unqualified; inner radius 6.8 mm leaves a 0.3 mm radial clearance to protected inner travel tabs; unfilled machined PEEK candidate, dry contact; actual torque and creep must be qualified
l_abduct_clutch_reaction_plate | upperarm_l.flex_frame | aluminum_7075 | structural_concept | 1 | 1868.5223587779958 | parts/l_abduct_clutch_reaction_plate.step | 3 mm steel reaction plate with keyed lining recess and two M3 frame mounts; spring thrust closes through plate; integral positive travel stops; D14.50 x0.85 upper retaining counterbore, flat Z3.15
l_abduct_clutch_radial_bush | upperarm_l.flex_frame | pom | structural_concept | 1 | 138.8002129927253 | parts/l_abduct_clutch_radial_bush.step | POM radial guide, clear of thrust faces; press fit/retention pending; D14.40 x0.70 flange at Z3.20..3.90, captured below thrust washer Z4.00; 0.15 total nominal axial float
l_abduct_clutch_thrust_washer | upperarm_l.flex_frame | thrust | structural_concept | 1 | 353.42917352885195 | parts/l_abduct_clutch_thrust_washer.step | SKF dimension candidate; PTFE face towards rotating spring seat; washer retention pending
l_abduct_clutch_spring_seat | upperarm_l.abduct_frame | metal | structural_concept | 1 | 141.98427997899074 | parts/l_abduct_clutch_spring_seat.step | Steel spring seat; thrust washer separates rotation from fixed reaction plate
l_abduct_clutch_disc_spring_a | upperarm_l.abduct_frame | spring | structural_concept | 1 | 49.74397807694068 | parts/l_abduct_clutch_disc_spring_a.step | SCHNORR 002 200 dimensional candidate at catalog test height
l_abduct_clutch_disc_spring_b | upperarm_l.abduct_frame | spring | structural_concept | 1 | 49.74397807694071 | parts/l_abduct_clutch_disc_spring_b.step | Opposed pair in series: force is not doubled
l_abduct_clutch_keyed_stop_cap | upperarm_l.abduct_frame | metal | structural_concept | 1 | 396.88687888604244 | parts/l_abduct_clutch_keyed_stop_cap.step | D key follows shaft; cap seats on metal shaft end; shim selection/retention and backlash need physical validation
l_abduct_clutch_outer_M3x8 | upperarm_l.abduct_frame | fastener | structural_concept | 1 | 119.7045629324554 | parts/l_abduct_clutch_outer_M3x8.step | Simplified thread envelope; axial cap retention, not hand tightness setting
l_abduct_clutch_drive_retainer_washer | upperarm_l.abduct_frame | metal | structural_concept | 1 | 69.98683034034687 | parts/l_abduct_clutch_drive_retainer_washer.step | Separate washer retains D drive in printed output hub
l_abduct_clutch_inner_M3x8 | upperarm_l.abduct_frame | fastener | structural_concept | 1 | 119.70456293245542 | parts/l_abduct_clutch_inner_M3x8.step | Independent output-hub retention; does not set clutch spring compression
l_abduct_clutch_mount_M3x10_0 | upperarm_l.flex_frame | fastener | structural_concept | 1 | 133.8417298736095 | parts/l_abduct_clutch_mount_M3x10_0.step | Reaction plate to printed support; simplified thread
l_abduct_clutch_mount_M3_nut_0 | upperarm_l.flex_frame | fastener | structural_concept | 1 | 51.09247186378785 | parts/l_abduct_clutch_mount_M3_nut_0.step | Captured hex nut, accessible from inside of support
l_abduct_clutch_mount_M3x10_1 | upperarm_l.flex_frame | fastener | structural_concept | 1 | 133.8417298736095 | parts/l_abduct_clutch_mount_M3x10_1.step | Reaction plate to printed support; simplified thread
l_abduct_clutch_mount_M3_nut_1 | upperarm_l.flex_frame | fastener | structural_concept | 1 | 51.09247186378785 | parts/l_abduct_clutch_mount_M3_nut_1.step | Captured hex nut, accessible from inside of support
r_flex_clutch_flanged_shaft | upperarm_r.flex_frame | aluminum_7075 | structural_concept | 1 | 2486.5737569435355 | parts/r_flex_clutch_flanged_shaft.step | Custom steel 6 mm journal; integral flange, inner D drive, outer D cap seat, two M3 blind threads; integral travel tab reacts directly into bearing frame
r_flex_clutch_keyed_lining | clavicle_r | peek | structural_concept | 1 | 352.38699863507355 | parts/r_flex_clutch_keyed_lining.step | 1 mm replaceable lining; coefficient and wear unqualified; inner radius 6.8 mm leaves a 0.3 mm radial clearance to protected inner travel tabs; unfilled machined PEEK candidate, dry contact; actual torque and creep must be qualified
r_flex_clutch_reaction_plate | clavicle_r | aluminum_7075 | structural_concept | 1 | 1856.1603247506964 | parts/r_flex_clutch_reaction_plate.step | 3 mm steel reaction plate with keyed lining recess and two M3 frame mounts; spring thrust closes through plate; Rev L two M2 through pilot bores at +/-11.9 for separate brass sensor standoffs; 1.0 mm minimum radial ligament; integral positive travel stops; D14.50 x0.85 upper retaining counterbore, flat Z3.15
r_flex_clutch_radial_bush | clavicle_r | pom | structural_concept | 1 | 138.80021299272474 | parts/r_flex_clutch_radial_bush.step | POM radial guide, clear of thrust faces; press fit/retention pending; D14.40 x0.70 flange at Z3.20..3.90, captured below thrust washer Z4.00; 0.15 total nominal axial float
r_flex_clutch_thrust_washer | clavicle_r | thrust | structural_concept | 1 | 353.42917352885195 | parts/r_flex_clutch_thrust_washer.step | SKF dimension candidate; PTFE face towards rotating spring seat; washer retention pending
r_flex_clutch_spring_seat | upperarm_r.flex_frame | metal | structural_concept | 1 | 141.98427997899094 | parts/r_flex_clutch_spring_seat.step | Steel spring seat; thrust washer separates rotation from fixed reaction plate
r_flex_clutch_disc_spring_a | upperarm_r.flex_frame | spring | structural_concept | 1 | 49.743978076940756 | parts/r_flex_clutch_disc_spring_a.step | SCHNORR 002 200 dimensional candidate at catalog test height
r_flex_clutch_disc_spring_b | upperarm_r.flex_frame | spring | structural_concept | 1 | 49.743978076940756 | parts/r_flex_clutch_disc_spring_b.step | Opposed pair in series: force is not doubled
r_flex_clutch_keyed_stop_cap | upperarm_r.flex_frame | aluminum | structural_concept | 1 | 361.6983591114387 | parts/r_flex_clutch_keyed_stop_cap.step | Rev L aluminum stop cap retains original metal stop heights and adds outside D flat for magnet cup; local contact stress and fatigue unqualified
r_flex_clutch_outer_M3x8 | upperarm_r.flex_frame | titanium | structural_concept | 1 | 95.05001952736538 | parts/r_flex_clutch_outer_M3x8.step | Rev L M3x8 titanium Grade 5 button screw dimension candidate (Accu SSB-M3-8-TI5); cylindrical head envelope 5.7 x 1.65, 2 mm hex, strength/procurement not released
r_flex_clutch_drive_retainer_washer | upperarm_r.flex_frame | metal | structural_concept | 1 | 69.98683034034684 | parts/r_flex_clutch_drive_retainer_washer.step | Separate washer retains D drive in printed output hub
r_flex_clutch_inner_M3x8 | upperarm_r.flex_frame | fastener | structural_concept | 1 | 95.18858359197093 | parts/r_flex_clutch_inner_M3x8.step | M3x8 ISO7380-1 low-profile button screw, 1.65 mm nominal head height; independent output-hub retention, no spring adjustment
r_flex_clutch_mount_M3x10_0 | clavicle_r | fastener | structural_concept | 1 | 133.84172987360978 | parts/r_flex_clutch_mount_M3x10_0.step | Reaction plate to printed support; simplified thread
r_flex_clutch_mount_M3_nut_0 | clavicle_r | fastener | structural_concept | 1 | 51.092471863788454 | parts/r_flex_clutch_mount_M3_nut_0.step | Captured hex nut, accessible from inside of support
r_flex_clutch_mount_M3x10_1 | clavicle_r | fastener | structural_concept | 1 | 133.84172987360975 | parts/r_flex_clutch_mount_M3x10_1.step | Reaction plate to printed support; simplified thread
r_flex_clutch_mount_M3_nut_1 | clavicle_r | fastener | structural_concept | 1 | 51.09247186378844 | parts/r_flex_clutch_mount_M3_nut_1.step | Captured hex nut, accessible from inside of support
r_abduct_clutch_flanged_shaft | upperarm_r.abduct_frame | aluminum_7075 | structural_concept | 1 | 2260.3790858850757 | parts/r_abduct_clutch_flanged_shaft.step | Custom steel 6 mm journal; integral flange, inner D drive, outer D cap seat, two M3 blind threads; integral travel tab reacts directly into bearing frame
r_abduct_clutch_keyed_lining | upperarm_r.flex_frame | peek | structural_concept | 1 | 352.386998635074 | parts/r_abduct_clutch_keyed_lining.step | 1 mm replaceable lining; coefficient and wear unqualified; inner radius 6.8 mm leaves a 0.3 mm radial clearance to protected inner travel tabs; unfilled machined PEEK candidate, dry contact; actual torque and creep must be qualified
r_abduct_clutch_reaction_plate | upperarm_r.flex_frame | aluminum_7075 | structural_concept | 1 | 1868.5223587779994 | parts/r_abduct_clutch_reaction_plate.step | 3 mm steel reaction plate with keyed lining recess and two M3 frame mounts; spring thrust closes through plate; integral positive travel stops; D14.50 x0.85 upper retaining counterbore, flat Z3.15
r_abduct_clutch_radial_bush | upperarm_r.flex_frame | pom | structural_concept | 1 | 138.8002129927253 | parts/r_abduct_clutch_radial_bush.step | POM radial guide, clear of thrust faces; press fit/retention pending; D14.40 x0.70 flange at Z3.20..3.90, captured below thrust washer Z4.00; 0.15 total nominal axial float
r_abduct_clutch_thrust_washer | upperarm_r.flex_frame | thrust | structural_concept | 1 | 353.42917352885195 | parts/r_abduct_clutch_thrust_washer.step | SKF dimension candidate; PTFE face towards rotating spring seat; washer retention pending
r_abduct_clutch_spring_seat | upperarm_r.abduct_frame | metal | structural_concept | 1 | 141.9842799789904 | parts/r_abduct_clutch_spring_seat.step | Steel spring seat; thrust washer separates rotation from fixed reaction plate
r_abduct_clutch_disc_spring_a | upperarm_r.abduct_frame | spring | structural_concept | 1 | 49.743978076940664 | parts/r_abduct_clutch_disc_spring_a.step | SCHNORR 002 200 dimensional candidate at catalog test height
r_abduct_clutch_disc_spring_b | upperarm_r.abduct_frame | spring | structural_concept | 1 | 49.74397807694069 | parts/r_abduct_clutch_disc_spring_b.step | Opposed pair in series: force is not doubled
r_abduct_clutch_keyed_stop_cap | upperarm_r.abduct_frame | metal | structural_concept | 1 | 396.8868788860425 | parts/r_abduct_clutch_keyed_stop_cap.step | D key follows shaft; cap seats on metal shaft end; shim selection/retention and backlash need physical validation
r_abduct_clutch_outer_M3x8 | upperarm_r.abduct_frame | fastener | structural_concept | 1 | 119.7045629324554 | parts/r_abduct_clutch_outer_M3x8.step | Simplified thread envelope; axial cap retention, not hand tightness setting
r_abduct_clutch_drive_retainer_washer | upperarm_r.abduct_frame | metal | structural_concept | 1 | 69.98683034034687 | parts/r_abduct_clutch_drive_retainer_washer.step | Separate washer retains D drive in printed output hub
r_abduct_clutch_inner_M3x8 | upperarm_r.abduct_frame | fastener | structural_concept | 1 | 119.70456293245542 | parts/r_abduct_clutch_inner_M3x8.step | Independent output-hub retention; does not set clutch spring compression
r_abduct_clutch_mount_M3x10_0 | upperarm_r.flex_frame | fastener | structural_concept | 1 | 133.8417298736095 | parts/r_abduct_clutch_mount_M3x10_0.step | Reaction plate to printed support; simplified thread
r_abduct_clutch_mount_M3_nut_0 | upperarm_r.flex_frame | fastener | structural_concept | 1 | 51.092471863787836 | parts/r_abduct_clutch_mount_M3_nut_0.step | Captured hex nut, accessible from inside of support
r_abduct_clutch_mount_M3x10_1 | upperarm_r.flex_frame | fastener | structural_concept | 1 | 133.8417298736095 | parts/r_abduct_clutch_mount_M3x10_1.step | Reaction plate to printed support; simplified thread
r_abduct_clutch_mount_M3_nut_1 | upperarm_r.flex_frame | fastener | structural_concept | 1 | 51.092471863787836 | parts/r_abduct_clutch_mount_M3_nut_1.step | Captured hex nut, accessible from inside of support
l_flex_drive_split_hub | upperarm_l.flex_frame | aluminum | structural_concept | 1 | 593.4821423412807 | parts/l_flex_drive_split_hub.step | Custom split metal D hub; M2 tapped clamp ear; preload/elastic closure not simulated
l_flex_drive_pinch_M2x10 | upperarm_l.flex_frame | fastener | structural_concept | 1 | 52.1496683363016 | parts/l_flex_drive_pinch_M2x10.step | M2 transverse pinch screw takes up shaft fit clearance; tightening torque not yet qualified
l_flex_drive_mount_M2x4_0 | upperarm_l.flex_frame | fastener | structural_concept | 1 | 33.10525669891111 | parts/l_flex_drive_mount_M2x4_0.step | Flange screw with trapped M2 nut; 1.6 mm nominal nut engagement
l_flex_drive_mount_M2_nut_0 | upperarm_l.flex_frame | fastener | structural_concept | 1 | 18.953259459605672 | parts/l_flex_drive_mount_M2_nut_0.step | Captured nut inside output yoke; fit and creep require testing
l_flex_drive_mount_M2x4_1 | upperarm_l.flex_frame | fastener | structural_concept | 1 | 33.105256698911106 | parts/l_flex_drive_mount_M2x4_1.step | Flange screw with trapped M2 nut; 1.6 mm nominal nut engagement
l_flex_drive_mount_M2_nut_1 | upperarm_l.flex_frame | fastener | structural_concept | 1 | 18.95325945960568 | parts/l_flex_drive_mount_M2_nut_1.step | Captured nut inside output yoke; fit and creep require testing
l_abduct_drive_split_hub | upperarm_l.abduct_frame | aluminum | structural_concept | 1 | 593.4821423412805 | parts/l_abduct_drive_split_hub.step | Custom split metal D hub; M2 tapped clamp ear; preload/elastic closure not simulated
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

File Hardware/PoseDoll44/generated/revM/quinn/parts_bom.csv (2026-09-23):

id | owner | material | role | quantity | volume_mm3 | STEP | note
l_yaw_bush_top | chest | pom | structural_concept | 1 | 154.55379218600356 | parts/l_yaw_bush_top.step | Machined POM-C plain sleeve. CAD is installed/compressed state; free OD is +0.030 +/-0.005 mm above nominal, housing bore +0.000..+0.010. Finish running bore after installation. No clutch axial preload. Pull-out and thermal qualification required.
l_yaw_bush_lower | chest | pom | structural_concept | 1 | 123.64303374880281 | parts/l_yaw_bush_lower.step | Machined POM-C plain sleeve. CAD is installed/compressed state; free OD is +0.030 +/-0.005 mm above nominal, housing bore +0.000..+0.010. Finish running bore after installation. No clutch axial preload. Pull-out and thermal qualification required.
l_elev_bush_27 | clavicle_l.protract_frame | pom | structural_concept | 1 | 92.73227531160214 | parts/l_elev_bush_27.step | Machined POM-C plain sleeve. CAD is installed/compressed state; free OD is +0.030 +/-0.005 mm above nominal, housing bore +0.000..+0.010. Finish running bore after installation. No clutch axial preload. Pull-out and thermal qualification required.
l_elev_bush_43 | clavicle_l.protract_frame | pom | structural_concept | 1 | 92.73227531160214 | parts/l_elev_bush_43.step | Machined POM-C plain sleeve. CAD is installed/compressed state; free OD is +0.030 +/-0.005 mm above nominal, housing bore +0.000..+0.010. Finish running bore after installation. No clutch axial preload. Pull-out and thermal qualification required.
l_yaw_carriage | clavicle_l.protract_frame | aluminum_7075 | structural_concept | 1 | 5420.45027489145 | parts/l_yaw_carriage.step | Machined yaw carriage, keyed D4 end and two original elevation bearings; bolt-on G4 reaction plate support; reamed press-fit sleeve seat, see retained_bushes manifest; reamed press-fit sleeve seat, see retained_bushes manifest
l_flex_bush_-36.5 | clavicle_l | pom | structural_concept | 1 | 108.06450409818184 | parts/l_flex_bush_-36.5.step | Machined POM-C plain sleeve. CAD is installed/compressed state; free OD is +0.030 +/-0.005 mm above nominal, housing bore +0.000..+0.010. Finish running bore after installation. No clutch axial preload. Pull-out and thermal qualification required.
l_flex_bush_-27.5 | clavicle_l | pom | structural_concept | 1 | 108.06450409818181 | parts/l_flex_bush_-27.5.step | Machined POM-C plain sleeve. CAD is installed/compressed state; free OD is +0.030 +/-0.005 mm above nominal, housing bore +0.000..+0.010. Finish running bore after installation. No clutch axial preload. Pull-out and thermal qualification required.
l_clavicle_output_frame | clavicle_l | aluminum_7075 | structural_concept | 1 | 6979.588780488892 | parts/l_clavicle_output_frame.step | Machined clavicle link, D4 middle key transfers elevation torque, M2 radial retainer; original shoulder centre preserved; reamed press-fit sleeve seat, see retained_bushes manifest; reamed press-fit sleeve seat, see retained_bushes manifest
l_abduct_bush_-20.5 | upperarm_l.flex_frame | pom | structural_concept | 1 | 77.27689609300178 | parts/l_abduct_bush_-20.5.step | Machined POM-C plain sleeve. CAD is installed/compressed state; free OD is +0.030 +/-0.005 mm above nominal, housing bore +0.000..+0.010. Finish running bore after installation. No clutch axial preload. Pull-out and thermal qualification required.
l_abduct_bush_20.5 | upperarm_l.flex_frame | pom | structural_concept | 1 | 108.06450409818177 | parts/l_abduct_bush_20.5.step | Machined POM-C plain sleeve. CAD is installed/compressed state; free OD is +0.030 +/-0.005 mm above nominal, housing bore +0.000..+0.010. Finish running bore after installation. No clutch axial preload. Pull-out and thermal qualification required.
l_flex_ring | upperarm_l.flex_frame | aluminum_7075 | structural_concept | 1 | 3827.0374024356224 | parts/l_flex_ring.step | Rev J removable split metal drive hub; flange fixed with two M2 screws, nut pockets and tool relief; strain/creep not verified; 7075-T6 metal candidate required for reamed interference-fit radial bush seats; no PLA press-fit claim; reamed press-fit sleeve seat, see retained_bushes manifest; reamed press-fit sleeve seat, see retained_bushes manifest
l_abduct_ring_and_twist_seat | upperarm_l.abduct_frame | aluminum_7075 | structural_concept | 1 | 3538.294014825509 | parts/l_abduct_ring_and_twist_seat.step | Machined metal shoulder abduction ring and twist reaction face; top thrust face Z5.5, radial bush does not carry preload; integral positive travel stops; D6.04 nominal sleeve seat and captured D7.4 lower flange; outer friction contact radius increased to 10 mm
l_twist_bush | upperarm_l.abduct_frame | pom | structural_concept | 1 | 223.31565271886208 | parts/l_twist_bush.step | Flanged POM-C D6 sleeve, D4.06 running bore; D7.4 x0.8 flange trapped between lining top -9 and housing shoulder -8. Nominal axial float .2 mm.
l_twist_rotor_face | upperarm_l | aluminum_7075 | structural_concept | 1 | 620.1574205087361 | parts/l_twist_rotor_face.step | Positive D4 drive; axial spring force reacts into the fixed metal shoulder seat; integral travel tab reacts directly into bearing frame; outer friction contact radius increased to 10 mm
l_twist_lining | upperarm_l.abduct_frame | peek | structural_concept | 1 | 282.98681225373474 | parts/l_twist_lining.step | ; unfilled PEEK ring R3.15..10, dry contact candidate
l_arm_upperarm_shell_front | upperarm_l | shell | solid_concept | 1 | 5717.762001164615 | parts/l_arm_upperarm_shell_front.step | 1.8 mm partial rigid arm cover; two M2x20 through captive rear nuts into closed centreline rail lugs; front straight hex access, remove before servicing joints; pose clearance sampled digitally
l_arm_upperarm_shell_back | upperarm_l | shell | solid_concept | 1 | 9128.424159839424 | parts/l_arm_upperarm_shell_back.step | 1.8 mm partial rigid arm cover; two M2x20 through captive rear nuts into closed centreline rail lugs; front straight hex access, remove before servicing joints; pose clearance sampled digitally
r_yaw_bush_top | chest | pom | structural_concept | 1 | 154.55379218600353 | parts/r_yaw_bush_top.step | Machined POM-C plain sleeve. CAD is installed/compressed state; free OD is +0.030 +/-0.005 mm above nominal, housing bore +0.000..+0.010. Finish running bore after installation. No clutch axial preload. Pull-out and thermal qualification required.
r_yaw_bush_lower | chest | pom | structural_concept | 1 | 123.64303374880284 | parts/r_yaw_bush_lower.step | Machined POM-C plain sleeve. CAD is installed/compressed state; free OD is +0.030 +/-0.005 mm above nominal, housing bore +0.000..+0.010. Finish running bore after installation. No clutch axial preload. Pull-out and thermal qualification required.
r_elev_bush_27 | clavicle_r.protract_frame | pom | structural_concept | 1 | 92.73227531160214 | parts/r_elev_bush_27.step | Machined POM-C plain sleeve. CAD is installed/compressed state; free OD is +0.030 +/-0.005 mm above nominal, housing bore +0.000..+0.010. Finish running bore after installation. No clutch axial preload. Pull-out and thermal qualification required.
r_elev_bush_43 | clavicle_r.protract_frame | pom | structural_concept | 1 | 92.73227531160214 | parts/r_elev_bush_43.step | Machined POM-C plain sleeve. CAD is installed/compressed state; free OD is +0.030 +/-0.005 mm above nominal, housing bore +0.000..+0.010. Finish running bore after installation. No clutch axial preload. Pull-out and thermal qualification required.
r_yaw_carriage | clavicle_r.protract_frame | aluminum_7075 | structural_concept | 1 | 5420.450481330481 | parts/r_yaw_carriage.step | Machined yaw carriage, keyed D4 end and two original elevation bearings; bolt-on G4 reaction plate support; reamed press-fit sleeve seat, see retained_bushes manifest; reamed press-fit sleeve seat, see retained_bushes manifest
r_flex_bush_-36.5 | clavicle_r | pom | structural_concept | 1 | 108.06450409818174 | parts/r_flex_bush_-36.5.step | Machined POM-C plain sleeve. CAD is installed/compressed state; free OD is +0.030 +/-0.005 mm above nominal, housing bore +0.000..+0.010. Finish running bore after installation. No clutch axial preload. Pull-out and thermal qualification required.
r_flex_bush_-27.5 | clavicle_r | pom | structural_concept | 1 | 108.06450409818174 | parts/r_flex_bush_-27.5.step | Machined POM-C plain sleeve. CAD is installed/compressed state; free OD is +0.030 +/-0.005 mm above nominal, housing bore +0.000..+0.010. Finish running bore after installation. No clutch axial preload. Pull-out and thermal qualification required.
r_clavicle_output_frame | clavicle_r | aluminum_7075 | structural_concept | 1 | 6816.921485329444 | parts/r_clavicle_output_frame.step | Machined clavicle link, D4 middle key transfers elevation torque, M2 radial retainer; original shoulder centre preserved; reamed press-fit sleeve seat, see retained_bushes manifest; reamed press-fit sleeve seat, see retained_bushes manifest
r_abduct_bush_-20.5 | upperarm_r.flex_frame | pom | structural_concept | 1 | 77.27689609300177 | parts/r_abduct_bush_-20.5.step | Machined POM-C plain sleeve. CAD is installed/compressed state; free OD is +0.030 +/-0.005 mm above nominal, housing bore +0.000..+0.010. Finish running bore after installation. No clutch axial preload. Pull-out and thermal qualification required.
r_abduct_bush_20.5 | upperarm_r.flex_frame | pom | structural_concept | 1 | 108.06450409818177 | parts/r_abduct_bush_20.5.step | Machined POM-C plain sleeve. CAD is installed/compressed state; free OD is +0.030 +/-0.005 mm above nominal, housing bore +0.000..+0.010. Finish running bore after installation. No clutch axial preload. Pull-out and thermal qualification required.
r_flex_ring | upperarm_r.flex_frame | aluminum_7075 | structural_concept | 1 | 3827.0419461374304 | parts/r_flex_ring.step | Rev J removable split metal drive hub; flange fixed with two M2 screws, nut pockets and tool relief; strain/creep not verified; 7075-T6 metal candidate required for reamed interference-fit radial bush seats; no PLA press-fit claim; reamed press-fit sleeve seat, see retained_bushes manifest; reamed press-fit sleeve seat, see retained_bushes manifest
r_abduct_ring_and_twist_seat | upperarm_r.abduct_frame | aluminum_7075 | structural_concept | 1 | 3537.3406261312343 | parts/r_abduct_ring_and_twist_seat.step | Machined metal shoulder abduction ring and twist reaction face; top thrust face Z5.5, radial bush does not carry preload; integral positive travel stops; D6.04 nominal sleeve seat and captured D7.4 lower flange; outer friction contact radius increased to 10 mm
r_twist_bush | upperarm_r.abduct_frame | pom | structural_concept | 1 | 223.3156527188622 | parts/r_twist_bush.step | Flanged POM-C D6 sleeve, D4.06 running bore; D7.4 x0.8 flange trapped between lining top -9 and housing shoulder -8. Nominal axial float .2 mm.
r_twist_rotor_face | upperarm_r | aluminum_7075 | structural_concept | 1 | 620.157420508735 | parts/r_twist_rotor_face.step | Positive D4 drive; axial spring force reacts into the fixed metal shoulder seat; integral travel tab reacts directly into bearing frame; outer friction contact radius increased to 10 mm
r_twist_lining | upperarm_r.abduct_frame | peek | structural_concept | 1 | 282.98681225373497 | parts/r_twist_lining.step | ; unfilled PEEK ring R3.15..10, dry contact candidate
r_arm_upperarm_shell_front | upperarm_r | shell | solid_concept | 1 | 5665.847102083631 | parts/r_arm_upperarm_shell_front.step | 1.8 mm partial rigid arm cover; two M2x20 through captive rear nuts into closed centreline rail lugs; front straight hex access, remove before servicing joints; pose clearance sampled digitally
r_arm_upperarm_shell_back | upperarm_r | shell | solid_concept | 1 | 9044.85313374938 | parts/r_arm_upperarm_shell_back.step | 1.8 mm partial rigid arm cover; two M2x20 through captive rear nuts into closed centreline rail lugs; front straight hex access, remove before servicing joints; pose clearance sampled digitally
l_flex_clutch_flanged_shaft | upperarm_l.flex_frame | aluminum_7075 | structural_concept | 1 | 2486.573756943535 | parts/l_flex_clutch_flanged_shaft.step | Custom steel 6 mm journal; integral flange, inner D drive, outer D cap seat, two M3 blind threads; integral travel tab reacts directly into bearing frame
l_flex_clutch_keyed_lining | clavicle_l | peek | structural_concept | 1 | 352.3869986350736 | parts/l_flex_clutch_keyed_lining.step | 1 mm replaceable lining; coefficient and wear unqualified; inner radius 6.8 mm leaves a 0.3 mm radial clearance to protected inner travel tabs; unfilled machined PEEK candidate, dry contact; actual torque and creep must be qualified
l_flex_clutch_reaction_plate | clavicle_l | aluminum_7075 | structural_concept | 1 | 1856.1603247506955 | parts/l_flex_clutch_reaction_plate.step | 3 mm steel reaction plate with keyed lining recess and two M3 frame mounts; spring thrust closes through plate; Rev L two M2 through pilot bores at +/-11.9 for separate brass sensor standoffs; 1.0 mm minimum radial ligament; integral positive travel stops; D14.50 x0.85 upper retaining counterbore, flat Z3.15
l_flex_clutch_radial_bush | clavicle_l | pom | structural_concept | 1 | 138.8002129927246 | parts/l_flex_clutch_radial_bush.step | POM radial guide, clear of thrust faces; press fit/retention pending; D14.40 x0.70 flange at Z3.20..3.90, captured below thrust washer Z4.00; 0.15 total nominal axial float
l_flex_clutch_thrust_washer | clavicle_l | thrust | structural_concept | 1 | 353.42917352885195 | parts/l_flex_clutch_thrust_washer.step | SKF dimension candidate; PTFE face towards rotating spring seat; washer retention pending
l_flex_clutch_spring_seat | upperarm_l.flex_frame | metal | structural_concept | 1 | 141.9842799789909 | parts/l_flex_clutch_spring_seat.step | Steel spring seat; thrust washer separates rotation from fixed reaction plate
l_flex_clutch_disc_spring_a | upperarm_l.flex_frame | spring | structural_concept | 1 | 49.74397807694076 | parts/l_flex_clutch_disc_spring_a.step | SCHNORR 002 200 dimensional candidate at catalog test height
l_flex_clutch_disc_spring_b | upperarm_l.flex_frame | spring | structural_concept | 1 | 49.74397807694076 | parts/l_flex_clutch_disc_spring_b.step | Opposed pair in series: force is not doubled
l_flex_clutch_keyed_stop_cap | upperarm_l.flex_frame | aluminum | structural_concept | 1 | 361.6983591114387 | parts/l_flex_clutch_keyed_stop_cap.step | Rev L aluminum stop cap retains original metal stop heights and adds outside D flat for magnet cup; local contact stress and fatigue unqualified
l_flex_clutch_outer_M3x8 | upperarm_l.flex_frame | titanium | structural_concept | 1 | 95.05001952736534 | parts/l_flex_clutch_outer_M3x8.step | Rev L M3x8 titanium Grade 5 button screw dimension candidate (Accu SSB-M3-8-TI5); cylindrical head envelope 5.7 x 1.65, 2 mm hex, strength/procurement not released
l_flex_clutch_drive_retainer_washer | upperarm_l.flex_frame | metal | structural_concept | 1 | 69.98683034034683 | parts/l_flex_clutch_drive_retainer_washer.step | Separate washer retains D drive in printed output hub
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

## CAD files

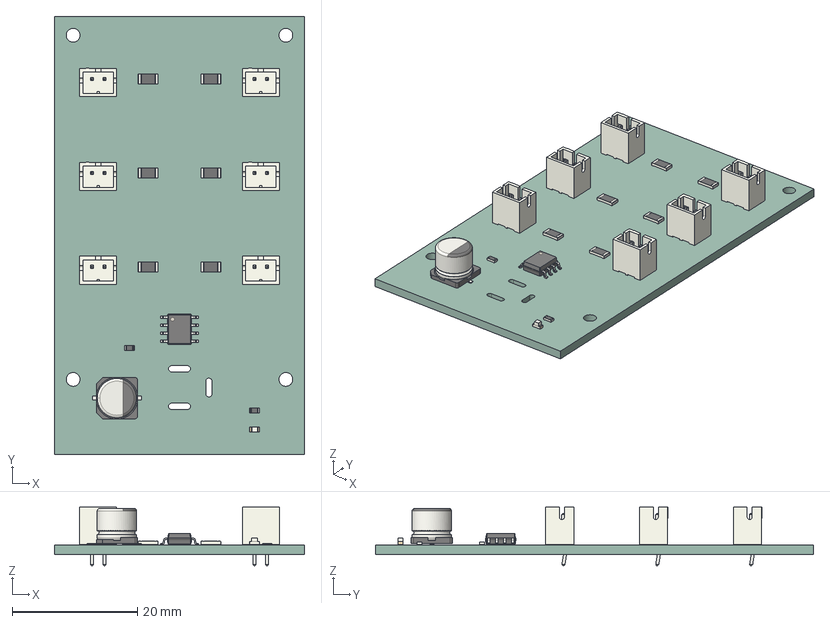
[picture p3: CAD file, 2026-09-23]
Hardware/PoseDoll44/electronics/power_revM/power_assembly_work.step
40.0 x 70.0 x 9.40 mm
JST_B2B_PH_K x 6
Fuse_1206_3216Metric x 6
SOIC-8_3.9x4.9mm_P1.27mm
R_0603_1608Metric x 2
LED_0603_1608Metric
CP_Elec_63x58
PoseDoll_PD41_Power_revM_PCB

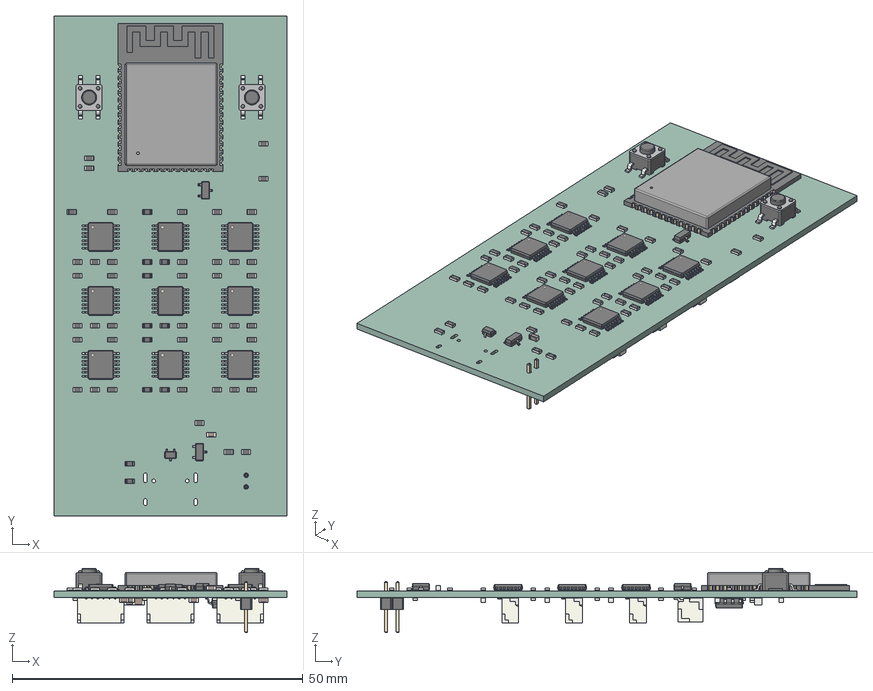
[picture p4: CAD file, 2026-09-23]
Hardware/PoseDoll44/electronics/regional_revM/regional_assembly_work.step
40.0 x 86.0 x 11.1 mm
R_0603_1608Metric x 84
TSSOP-14_4.4x5mm_P0.65mm x 9
C_0603_1608Metric x 14
SOT-323_SC-70
ESP32-S3-WROOM-1
SW_SPST_TL3305A x 2
SOT-23 x 2
JST_SH_BM06B-SRSS-TB_1x06-1MP_P1.00mm_Vertical x 9
C_0805_2012Metric x 3
SOIC-8_3.9x4.9mm_P1.27mm
PinHeader_1x02_P200mm_Vertical
JST_BM03B_GHS_TBT x 2
usb_routed_work_PCB

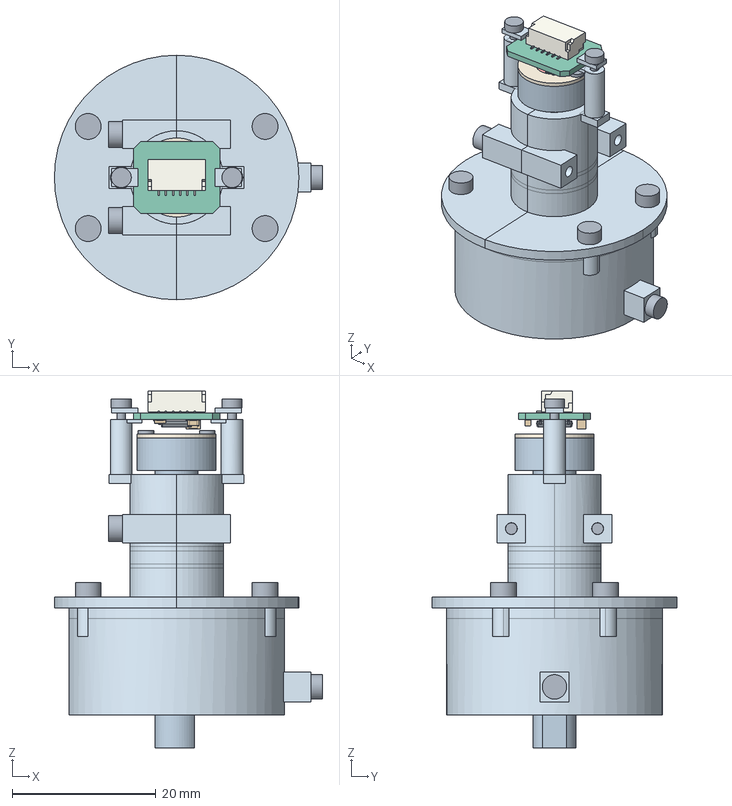
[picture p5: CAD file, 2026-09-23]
Hardware/PoseDoll44/generated/revO2/runs/o2_20260923_r1/joint/L6_R2_assembly.step
37.3 x 34.0 x 49.6 mm
one_piece_brake_cup
housing_L
housing_R
cup_mount_0
cup_mount_1
cup_mount_2
cup_mount_3
rear_bush_L
rear_bush_R
front_bush_L
front_bush_R
thrust_rear_L
thrust_rear_R
thrust_front_L
thrust_front_R
measurement_shaft
floating_brake_disc
front_friction_lining
rear_friction_lining
wear_sheet
keyed_pressure_plate
spring_front_washer
disc_spring_1
disc_spring_2
disc_spring_3
disc_spring_4
spring_rear_washer
threaded_adjuster_cap
cap_lock_dog_screw
bearing_clamp_-6
bearing_clamp_6
diametric_magnet
magnet_keeper
keeper_screw_-4.25
keeper_screw_4.25
sensor_pcba_0
sensor_pcba_1
sensor_pcba_2
sensor_pcba_3
sensor_pcba_4
sensor_pcba_5
sensor_pcba_6
sensor_post_-7.7
pcb_edge_clamp_-7.7
pcb_clamp_screw_-7.7
sensor_post_7.7
pcb_edge_clamp_7.7
pcb_clamp_screw_7.7

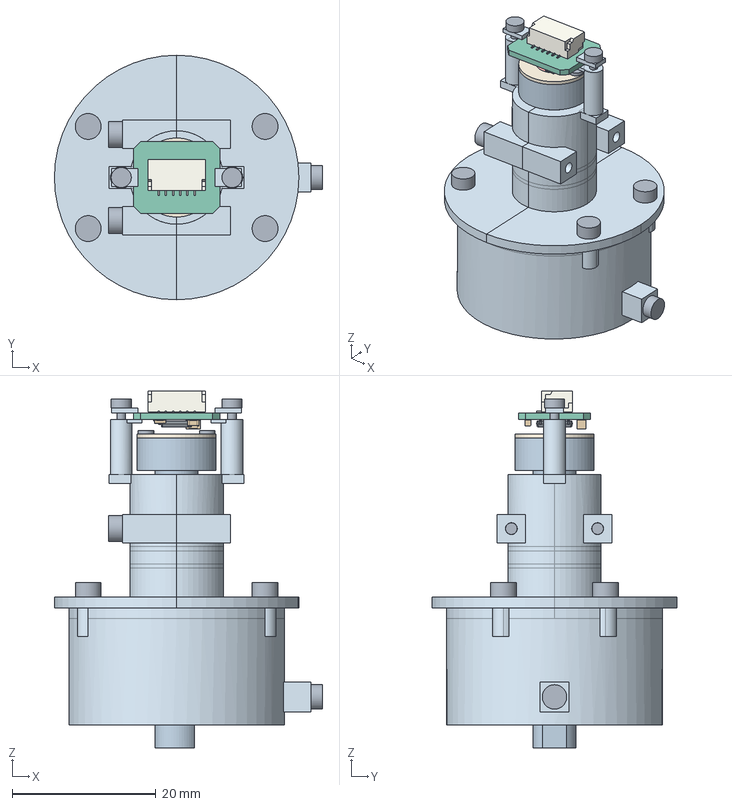
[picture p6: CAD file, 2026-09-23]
Hardware/PoseDoll44/generated/revO3/runs/o3_20260924_r1/joint/L6_R3_assembly.step
37.3 x 34.0 x 49.6 mm
one_piece_brake_cup
housing_L
housing_R
cup_mount_0
cup_mount_1
cup_mount_2
cup_mount_3
rear_bush_L
rear_bush_R
front_bush_L
front_bush_R
thrust_rear_L
thrust_rear_R
thrust_front_L
thrust_front_R
measurement_shaft
floating_brake_disc
front_lining_backing
rear_lining_backing
front_friction_lining
rear_friction_lining
keyed_pressure_plate
spring_front_washer
disc_spring_1
disc_spring_2
disc_spring_3
disc_spring_4
spring_rear_washer
threaded_adjuster_cap
cap_lock_dog_screw
bearing_clamp_-6
bearing_clamp_6
diametric_magnet
magnet_keeper
keeper_screw_-4.25
keeper_screw_4.25
sensor_pcba_0
sensor_pcba_1
sensor_pcba_2
sensor_pcba_3
sensor_pcba_4
sensor_pcba_5
sensor_pcba_6
pcb_edge_clamp_-7.7
pcb_clamp_screw_-7.7
pcb_edge_clamp_7.7
pcb_clamp_screw_7.7

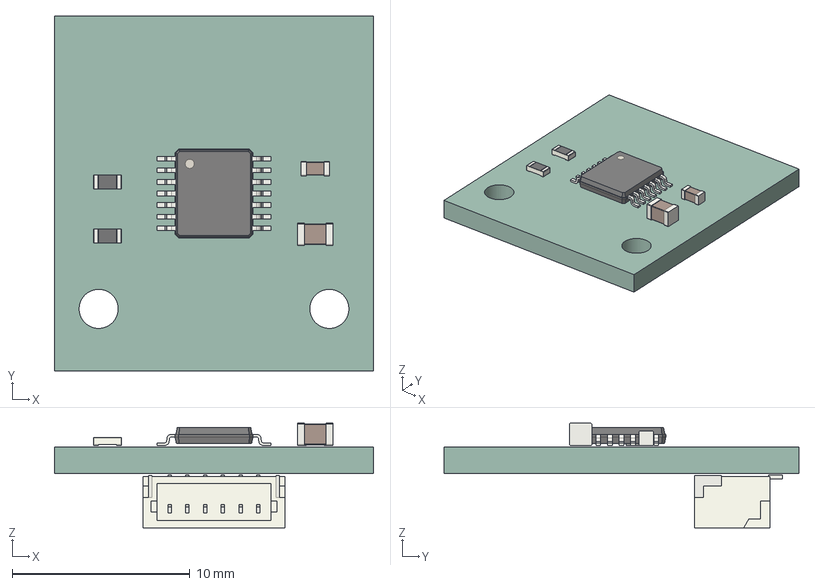
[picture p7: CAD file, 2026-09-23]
Hardware/PoseDoll44/electronics/sensor_revM_large_sh/sensor_large_sh.step
18.0 x 20.0 x 5.89 mm
R_0603_1608Metric x 2
C_0603_1608Metric
TSSOP-14_4.4x5mm_P0.65mm
C_0805_2012Metric
JST_SH_SM06B-SRSS-TB_1x06-1MP_P1.00mm_Horizontal
PoseDoll_AS5048A_revM_large_sh_PCB

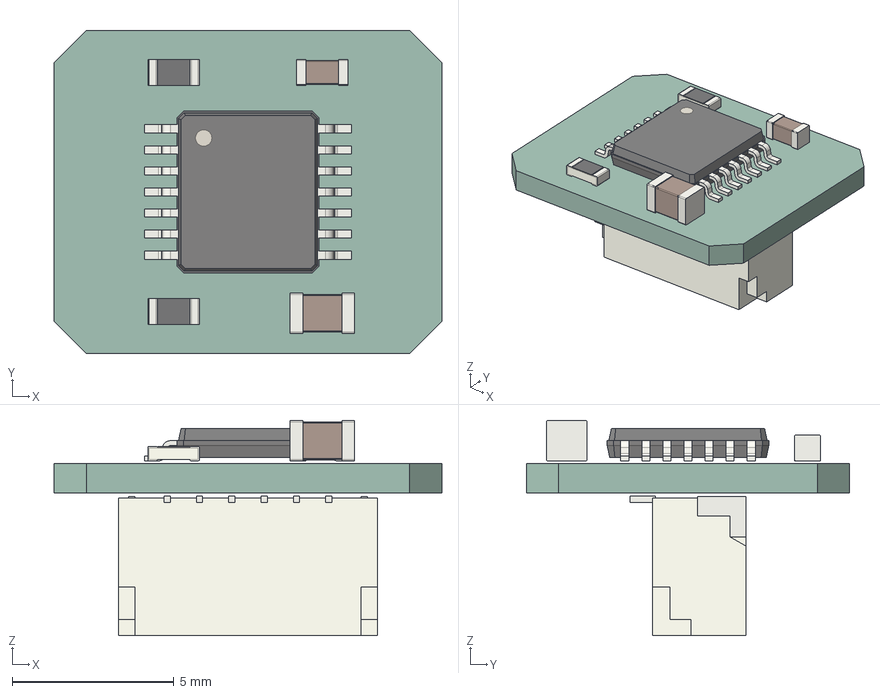
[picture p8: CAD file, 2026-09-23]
Hardware/PoseDoll44/electronics/sensor_revM_sh/sensor_revM_sh.step
12.0 x 10.0 x 6.65 mm
R_0603_1608Metric x 2
TSSOP-14_4.4x5mm_P0.65mm
C_0603_1608Metric
C_0805_2012Metric
JST_SH_BM06B-SRSS-TB_1x06-1MP_P1.00mm_Vertical
PoseDoll_AS5048A_revM_sh_PCB

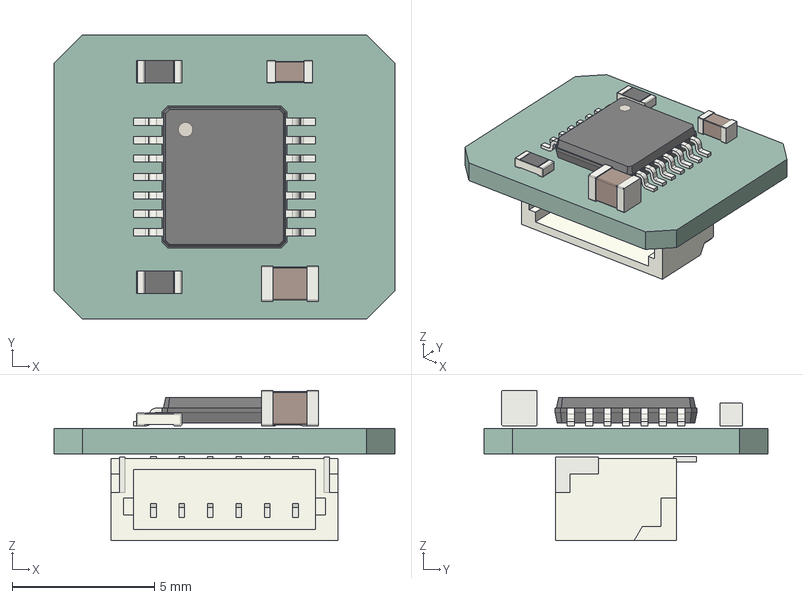
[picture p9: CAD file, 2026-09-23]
Hardware/PoseDoll44/electronics/sensor_revM_side/sensor_revM_side.step
12.0 x 10.0 x 5.29 mm
C_0805_2012Metric
C_0603_1608Metric
R_0603_1608Metric x 2
TSSOP-14_4.4x5mm_P0.65mm
JST_SH_SM06B-SRSS-TB_1x06-1MP_P1.00mm_Horizontal
PoseDoll_AS5048A_revM_side_PCB

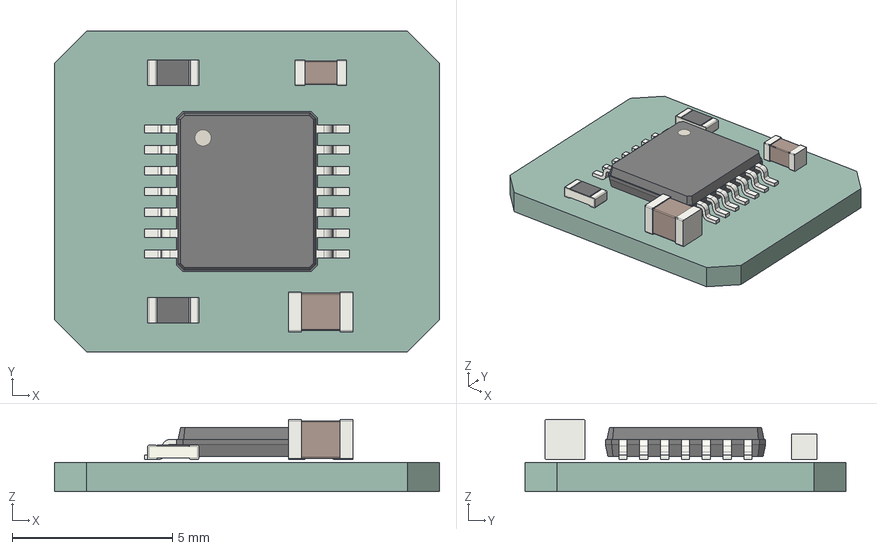
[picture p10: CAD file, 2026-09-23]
Hardware/PoseDoll44/generated/revK/components/sensor_revC_mini.step
12.0 x 10.0 x 2.25 mm
R_0603_1608Metric x 2
C_0603_1608Metric
C_0805_2012Metric
TSSOP-14_4.4x5mm_P0.65mm
PoseDoll_AS5048A_revC_mini_PCB

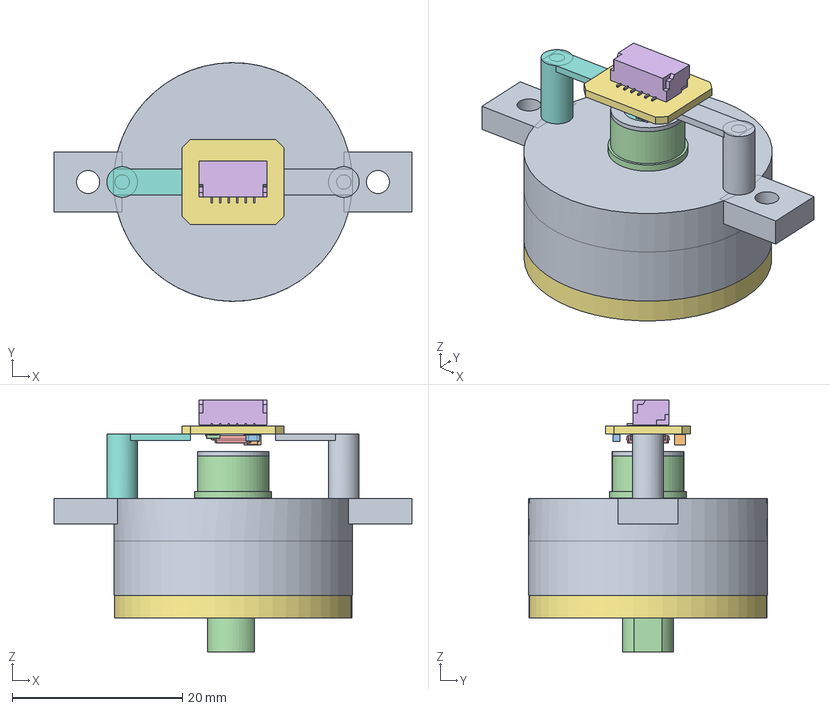
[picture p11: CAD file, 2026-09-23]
Hardware/PoseDoll44/generated/revO/joints/L6/L6_joint_study.step
42.0 x 28.0 x 29.5 mm
fixed_metal_housing
radial_bush
axial_datum_washer
integral_rotor_shaft_and_magnet_seat
replaceable_friction_lining
keyed_floating_pressure_plate
threaded_adjuster_cap
diametric_6x2p5_magnet
removable_magnet_keeper
sensor_pcba_existing_0
sensor_pcba_existing_1
sensor_pcba_existing_2
sensor_pcba_existing_3
sensor_pcba_existing_4
sensor_pcba_existing_5
sensor_pcba_existing_6
fixed_sensor_post_-1
fixed_sensor_post_1

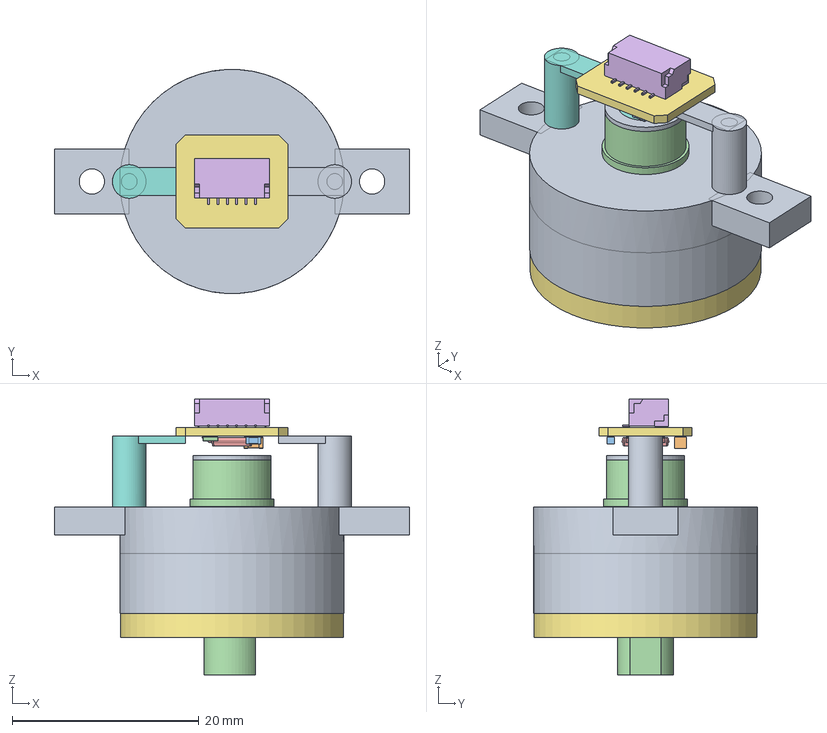
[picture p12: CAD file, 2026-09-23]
Hardware/PoseDoll44/generated/revO/joints/M6/M6_joint_study.step
38.0 x 24.0 x 29.5 mm
fixed_metal_housing
radial_bush
axial_datum_washer
integral_rotor_shaft_and_magnet_seat
replaceable_friction_lining
keyed_floating_pressure_plate
threaded_adjuster_cap
diametric_6x2p5_magnet
removable_magnet_keeper
sensor_pcba_existing_0
sensor_pcba_existing_1
sensor_pcba_existing_2
sensor_pcba_existing_3
sensor_pcba_existing_4
sensor_pcba_existing_5
sensor_pcba_existing_6
fixed_sensor_post_-1
fixed_sensor_post_1

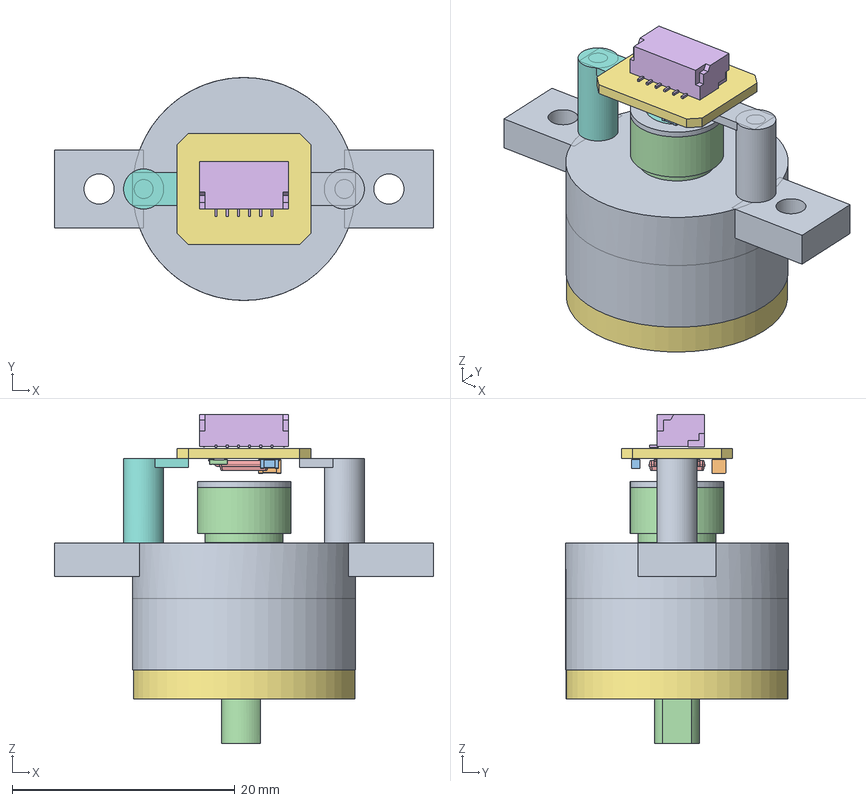
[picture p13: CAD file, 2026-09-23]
Hardware/PoseDoll44/generated/revO/joints/S4/S4_joint_study.step
34.0 x 20.0 x 29.5 mm
fixed_metal_housing
radial_bush
axial_datum_washer
integral_rotor_shaft_and_magnet_seat
replaceable_friction_lining
keyed_floating_pressure_plate
threaded_adjuster_cap
diametric_6x2p5_magnet
removable_magnet_keeper
sensor_pcba_existing_0
sensor_pcba_existing_1
sensor_pcba_existing_2
sensor_pcba_existing_3
sensor_pcba_existing_4
sensor_pcba_existing_5
sensor_pcba_existing_6
fixed_sensor_post_-1
fixed_sensor_post_1

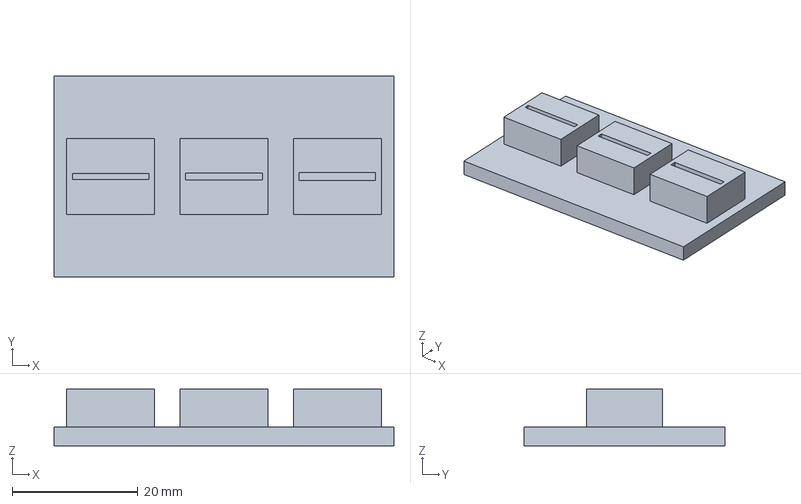
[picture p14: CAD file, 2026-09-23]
Hardware/PoseDoll44/generated/revO/prototypes/A02_board_edge_coupon.step
54.0 x 32.0 x 9.00 mm

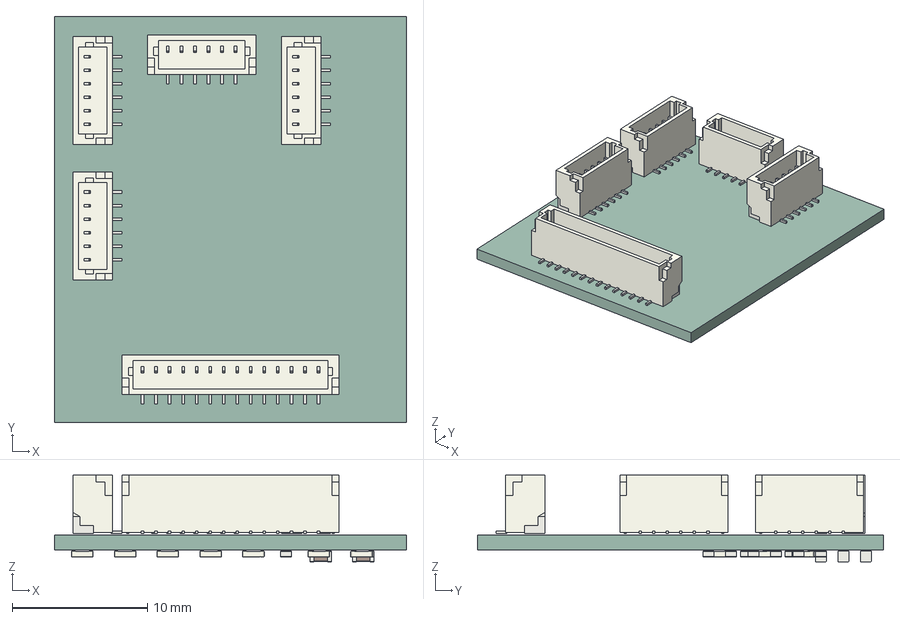
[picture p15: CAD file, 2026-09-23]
Hardware/PoseDoll44/generated/revO2/runs/o2_20260923_r1/electronics/distal4/PoseDoll_RevO2_distal4.step
26.0 x 30.0 x 6.40 mm
JST_SH_BM06B-SRSS-TB_1x06-1MP_P1.00mm_Vertical x 4
JST_SH_BM14B-SRSS-TB_1x14-1MP_P1.00mm_Vertical
R_0603_1608Metric x 33
C_0603_1608Metric x 5
PoseDoll_RevO2_distal4_PCB

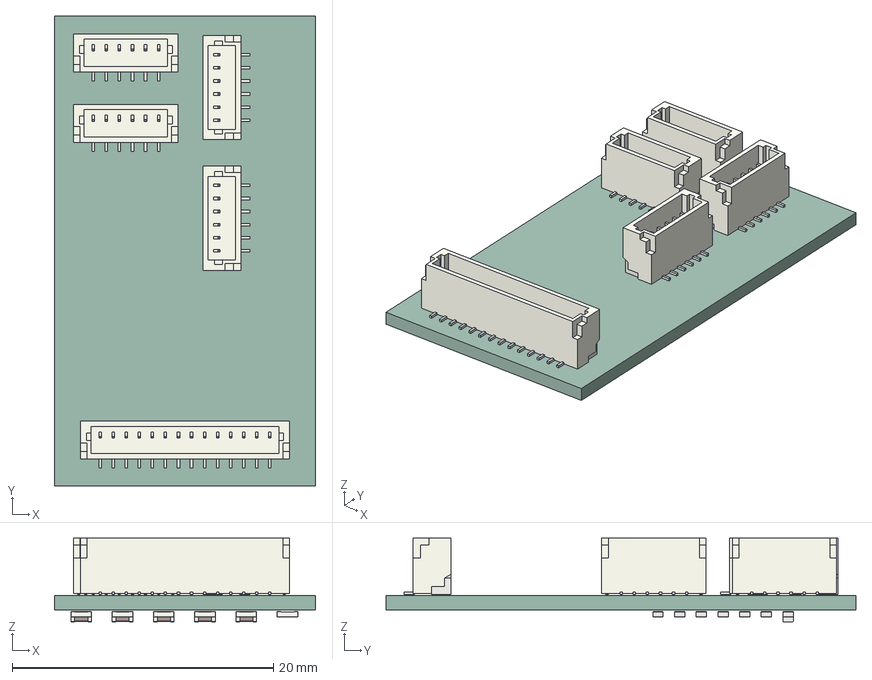
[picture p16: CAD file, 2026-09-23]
Hardware/PoseDoll44/generated/revO2/runs/o2_20260923_r1/electronics/distal4_narrow/PoseDoll_RevO2_distal4_narrow.step
20.0 x 36.0 x 6.40 mm
JST_SH_BM06B-SRSS-TB_1x06-1MP_P1.00mm_Vertical x 4
JST_SH_BM14B-SRSS-TB_1x14-1MP_P1.00mm_Vertical
R_0603_1608Metric x 33
C_0603_1608Metric x 5
PoseDoll_RevO2_distal4_narrow_PCB

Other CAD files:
Hardware/PoseDoll44/generated/revO3/runs/o3_20260924_r2/joint/L6_R3_assembly.step
Hardware/PoseDoll44/generated/revO3/runs/o3_20260924_r3/joint/L6_R3_assembly.step
Hardware/PoseDoll44/generated/revO2/runs/o2_20260923_r1/electronics/proximal5/proximal5_with_mating_study.step
Hardware/PoseDoll44/generated/revO3/runs/o3_20260924_r1/electronics/distal4/PoseDoll_RevO3_distal4.step
Hardware/PoseDoll44/generated/revC/step/sensor_revB.step
Hardware/PoseDoll44/generated/revO/prototypes/A01_journal_fit_coupon.step
Hardware/PoseDoll44/generated/revO/prototypes/A01_journal_fit_coupon.stl
Hardware/PoseDoll44/generated/revO/prototypes/A02_board_edge_coupon.stl
Hardware/PoseDoll44/generated/revO2/runs/o2_20260923_r1/electronics/distal4/distal4_with_mating_study.step
Hardware/PoseDoll44/generated/revO2/runs/o2_20260923_r1/electronics/distal4_narrow/distal4_narrow_with_mating_study.step
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

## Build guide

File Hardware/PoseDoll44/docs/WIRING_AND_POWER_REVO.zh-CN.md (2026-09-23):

# Rev O 电源与通信设计状态

## 固件已实施的部分
`Firmware/PoseDollFullBody/revO/` 为独立项目。G0 用显式编译角色选择；不初始化 SPI，不自动标记 N1 在线，BOOT/ACK/END/PAIR 接收涵盖 N1–N6。未修改旧固件、共享协议快照或 UE 项目。
41 个轴仍占协议槽 3–43；前三槽保持 PD_FIXED，缺失保持 PD_MISSING，故障保持 PD_FAULT 与诊断位，正常零角度仍可测得。G0 从不占用第七个测量数组元素。新鲜批次失去 N1 时三路腰槽必须缺失。

## 电气实现程度
G0、3/6/7/9 路板均有原生 KiCad 原理图和真实库封装布局。原理图 ERC 通过不等于 PCB 完成；板未布线，仍有未连接项与工艺规则问题。0.2 mm 的 MCU 热焊盘孔与当前 0.3 mm 工艺规则不匹配，需要明确制造工艺后处理，不以忽略 DRC 消除失败。
体内板取消日常 USB，保留每端口 SN74LVC125APWR 缓冲和独立六芯传感器接口。G0 保留数据专用 USB 的隔离拓扑。每种板的准确元件身份、网络和封装见同目录 connectivity.json / layout.json。
布局导出的 XY 使用真实库 courtyard；Z 高度、配合插头和线尾使用保守探索包络，**并非全部厂家 STEP**。因此还不能声称完整 PCBA 包络已认证或能够装入任意腔体。

## 电源候选
本轮实际原理图保持 **5 V 输入**，12 V 只进入计算比较。它保留与旧器件基线的边界，没有把旧板认定为 12 V 可用。初始分析比较 24/26/28 AWG 的 1 m 电源对，在 -5% 电源容差及恒功率负载下求解压降；6 MCU、41 传感器、收发器和缓冲器的电流均为工程分配值，非实测。
[计算记录](../verification/revO/power_budget.json) 也列出尚未完成的六路内部支路保护、浪涌/TVS、USB 回灌与线束温升。初始 5 V / 24 AWG 只是后续设计基线，不是全套接线指导。
外接复合线需要 CAN_H、CAN_L、V+、GND。普通 USB 插头不可承载自定义 CAN/电源。骨盆接口最终型号、针序、低矮弯头和左右方向尚未冻结；不能据此自接 12 V 线束。

## CAN
候选电气线性顺序：G0 → N1 → N5 → N6 → N2 → N3 → N4；两端各 120 Ω。折返需要进出对线，不能改成无约束星形或保留第三个端接。
30 帧/批 × 135 bit × 60 Hz / 500 kbit/s = 48.6%。解析调度例约 11.49 ms，在假设每轴读取 700 µs、无错误且回调立即调度时成立。它未覆盖驱动/系统延迟、epoch/BOOT/ACK 突发、错误与重试；14 ms 批次截止和 8 ms 采样窗仍需真实台架验证。

## 一手规格核对
2026-09-23 读取：
- [Espressif ESP32-S3-WROOM-1/1U datasheet v1.8](https://www.espressif.com/sites/default/files/documentation/esp32-s3-wroom-1_wroom-1u_datasheet_en.pdf)：WROOM-1 的模块尺寸 18×25.5×3.1 mm；此尺寸不包括 PCB、接头与维护空间。
- [TI TPS6216x datasheet](https://www.ti.com/lit/ds/symlink/tps62162.pdf)：稳压器输入范围不等于整块旧板的输入认证；保护和被动器件必须逐项审查。
- [Infineon AS5048A](https://www.infineon.com/part/AS5048A)：继续采用轴上角度传感方案，不能由型号直接推断当前气隙的磁场/精度。
- [TI CAN Physical Layer Requirements](https://www.ti.com/lit/an/slla270/slla270.pdf)：线性总线与端接约束。
- [SCHNORR 弹簧目录](https://www.schnorr-group.com/fileadmin/4_Downloads/Brochures/SCHNORR_Produktbroschuere_EN_2024-02.pdf)：后续碟簧选型来源；本轮尚未将目录载荷当成新关节实测保持能力。

供应方报价、板级温升、磁场、串扰、关节力矩和电缆手感均待验证，无已获得的制造价格。

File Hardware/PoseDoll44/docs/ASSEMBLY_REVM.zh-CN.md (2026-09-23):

# Rev M 装配说明：先做成套部件，再连接全身

这份说明对应 `cad/revM/final_model.py` 构建出的 Manny / Quinn 总装。零件名、空间位置和逐件 STEP 以 `generated/revM/<角色>/manufacturing_manifest.json` 为准；同名旧版本不可混装。两款角色各有独立打印件和线束表，共用传感器板、区域板及关节结构族。

## 先认清三类零件

1. **你打印的件**：清单中带 `print` 项的 PLA 骨架、外壳、线夹。文件在各角色的 `print_candidates`。按 STL 原尺寸导入，单位 mm，不缩放。
2. **交给加工方的件**：铝合金轴系和连接件、POM 轴套、PEEK 摩擦片、薄金属压板、定制隔柱。按 STEP 与加工说明报价和预装。光滑轴颈是轴承工作面；普通全牙螺丝不能替代。
3. **购买或代装的件**：标准紧固件、碟簧、磁铁、PCBA、预压接线束。建议让贴片厂交付焊接完成的板，让线束加工方交付有标签且测过通断的成品线。SH 的 1 mm 接头不适合第一次接触硬件时自行徒手压接。

总装中近两千个 CAD 实体包括螺丝、焊接元件和尺寸包络，不是让你购买近两千种不同零件。传感器电子部件按 **39 块小板 + 2 块肩部大板** 采购成套 PCBA；区域板 6 块，电源分配板 1 块。

## 装配前准备

- 带公制内六角 1.5 / 2 / 2.5 mm 的螺丝刀；匹配 M2 / M3 螺母的小扳手、镊子、剪线钳。
- 游标卡尺、万用表；后续校准需要可核对角度的量角工具。扭矩验收用拉力计配已知力臂，不能把螺丝拧紧程度当成持姿扭矩读数。
- 准备浅盘，把左右侧、角色名、部件编号贴在袋子上。左右以人偶自身方向为准。
- 全部机械初装、插拔传感器线都在断电状态完成。电子仓最终装好并排除短路后才接外部低压电源。

**碟簧预紧筒由加工/装配方预装。** 腰胸候选预紧力达 1,656 N，手指压不住，也不应让新手靠试拧未知强度螺丝来压装。加工方应使用轴向夹具，检查金属止挡、螺纹啮合与装配高度，然后给出转动扭矩和回差记录。交给你的应是能够直接转动、安装的关节组件。

## 关节内部的共同结构

从固定侧到输出侧可以辨认出：固定金属轴承眼、POM 轴套、被固定侧限位的 PEEK 摩擦片、光滑轴颈及输出法兰、磨损/反力垫片、碟簧、键接金属止挡帽、轴端保持螺钉，以及独立的磁铁杯和传感器板托。

- 重力和手部操作力通过轴、法兰、轴套和框架传递；PCB 不承重。
- 磁铁必须为指定尺寸的**径向充磁**件，不能仅凭“圆形磁铁”采购。轴向充磁圆片不能代用。
- 磁铁杯通过键形面传角，螺钉负责保持；胶水不替代机械保持。
- `magnet_keeper` 是旋转侧的磁铁保持盖。线束不能绑在它、轴、转子或碟簧上。
- 软件的角度上限不是实体限位。当前 41 个测量轴都有负载侧机械限位；不要掰着磁铁杯撞限位。
- 腰、胸的六个关节是双摩擦面版本；不可拿早期 `compact_axis.py` 单独导出的旧模块代替最新总装中的组件。
- 高负载输出已有 D8 键形段，轴颈仍依各结构定义。D8 输出孔和 D6 轴套工作孔是不同位置，不是尺寸写错。

腰部与肘部的真实最终小总成有 [腰关节拆解图](../generated/revM/assembly_details/waist_pitch_exploded.png) 和 [肘关节拆解图](../generated/revM/assembly_details/elbow_l_flex_exploded.png)。图中间隔是分组展示距离，不能照图间距装配；实际尺寸以对应 STEP 为准。

## 建议的总装顺序

### 1. 逐个核对预装关节

对照查看器中的部件名称与 `mechanical_manifest/network_revM.json`，给每个关节贴上轴名，例如 `elbow_l.flex`。确认转动顺畅、有保持力，限位方向正确；先不插传感器线。磁铁盖、轴端螺钉和两侧保持件缺一个都不继续装入肢体。

传感器 PCB 应在两侧托座上平放，用绝缘压片固定板边。不要把螺钉拧到 PCB 弯曲。小板/大板的板厚和安装孔不同，不能互换。最新两种板均使用 SH6 接头。

### 2. 装左右腿和双臂

每条腿按髋屈伸 → 髋外展 → 大腿扭转 → 大腿梁 → 膝 → 小腿梁 → 踝两轴 → 脚托/前脚掌顺序核对连接。

每条手臂按肩带 → 肩屈伸 → 肩外展 → 上臂扭转 → 上臂梁 → 肘 → 前臂扭转 → 前臂梁 → 腕两轴 → 手部件核对连接。

紧固连接件时先保留工具通道：先放入被捕获的螺母，再装连接螺丝，最后才装 PCB 托、磁铁盖附近的服务件和外壳。对于被后一节遮挡的螺钉，在工作台上先组成该节的小总成，再连接上游。所有螺钉应按清单长度，不能以“更长更牢”为原则替换。

上臂每侧两组、前臂每侧一组 M2×20 螺钉与捕获螺母固定可拆外壳，共六组。先在独立臂段上放入后侧螺母，再从前侧装螺钉，之后才连接上下游关节；六组直线螺钉/螺母及刀杆通道单独检查。螺钉仅连接壳体凸台与骨架安装耳，不能任意拧到壳体变形。

轴向保持螺钉不用于每天调整手感。手感通过规定的碟簧高度/垫片组合及摩擦片来确定；实际扭矩超出验收窗口时返工该组件，不用任意松开保持螺钉。

### 3. 装骨盆、腰、胸和颈头

先把骨盆内部框架与腰部轴系连接，再装胸部输入框、胸部三轴、胸框和颈头组件。颈梁有绕开肩部运动空间的路径，不能改成看起来更短的直杆。

骨盆没有外部支架接口的强制约束，也没有三颗用于测世界朝向的传感器。软件始终声明 `pelvis.yaw/pitch/roll` 为固定参考。腰部运动从 `waist.*` 开始测量；髋部运动由左右 `thigh_*` 测量。

### 4. 装电子仓

每组背部载板先装好被捕获的螺母，再固定到骨盆/胸框。区域 PCB 靠四角的硅胶垫及壳体夹持，不要自行在 PCB 上钻孔。

从人偶自身左到右，胸部仓是 N3 / N2 / N4，骨盆仓是 N5 / N1 / N6。N1 是 USB 网关，后面另有独立电源分配仓。盖上的指示灯孔用于观察电源状态。

电源板四个 M2 固定点使用图示的绝缘垫片；插座后方的壳体挡块承受插拔力。不要省略背盖或只让焊脚承受插头推力。底部直流插座和 USB 出口保持可拔插。

### 5. 装线束，最后装壳

按[线束说明](WIRING_REVM.zh-CN.md)逐根连接。先装稳定肢段的线夹和硅胶保护，再布置关节外侧的松弛 U 形线段。转到各轴两端逐一确认没有拉紧、缠轴和夹线，之后才装稳定部位的壳。

头、胸前、上臂、前臂、手、大腿前侧、小腿和脚部外壳为分段可拆件；肩带、肘、腕、腰、髋、膝、颈等活动空间保持开放。大腿后侧、小腿后上段等容易相互挤压的部位也留空。缺少连续皮肤是有意的，不需要自行补软胶或硬片。

## 阶段性验收

完整 CAD 已按两款全身配置设计；实物仍按下面顺序放行，避免一开始同时制造两整套：

1. 一套高负载腰部双摩擦面关节：装配高度、持姿扭矩、起动阻力、30 分钟下垂和重复摆动。
2. 一组传感器小板 + 一个区域板：磁场诊断、角度重复性、最长线束、温升和断线状态。
3. 一条完整手臂、一条完整腿：框架刚度、层间强度、外壳/线束干涉、紧固件松动。
4. 一款全身后再复制另一款：新增质量后的持姿、坐/躺动作、41 轴同步、全身校准与 UE 姿态对应。

螺丝和板件松动、打印裂纹、异常温升、线束被夹或传感器磁场故障都应记录并修正。数字碰撞通过不能代替这些检查。记录表、量化阈值与校准步骤见[验证与校准](BUILD_AND_CALIBRATE_REVM.zh-CN.md)。

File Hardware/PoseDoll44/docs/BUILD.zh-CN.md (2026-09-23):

# 构建与复现

工具路径在 tools/local_toolchain.json。本轮没有安装新工具或修改模拟器 Python 环境。

CadQuery 复用已运行的 CQ-editor 2.7 包。run_cad.py 是本机 PyInstaller 包兼容加载器，**不是官方 CQ-editor CLI**。CQ-editor 关闭后临时目录可能消失，需重新打开；也可用独立 CadQuery 2.7 环境直接运行 cad/build.py。

仓库根目录 PowerShell 执行：

~~~
powershell -NoProfile -File Hardware\PoseDoll44\tools\Build-Hardware.ps1 -Regenerate -Firmware
~~~

-Regenerate 从 Python 源覆盖本包生成的 CAD/PCB，手动修改原生 KiCad 文件后需同步生成器；日常检查可去掉此选项。-Firmware 只编译不烧录。脚本不会打印、采购、修改现有 UE 或模拟器。

检查包含 CAD 导出、名义干涉、KiCad ERC/DRC/原理图一致性、渲染、诊断故障测试、GUI 构造、模拟器回归、固件编译和跨文件检查。退出码/日志写入 verification。-SkipGeometry 只用于快速复查，修改 CAD 后不能省略完整检查。

主要源码：
- cad/model.py：运动树、偏移、关节包络和节点位置。
- cad/parts.py：13 个编号打印件与五金/PCB参考。
- cad/build.py：导出、姿势、质量/扭矩/电源/CAN预算。
- cad/inspect_geometry.py：OCC 实体交集采样。
- tools/build_electronics.py、route_sensor.py：原生 KiCad 生成和本板路由，最后由官方检查工具判定。
- 仓库 Firmware/PoseDollHardware：单轴固件。
- 仓库 Tools/PoseDollHardwareBridge：解码、日志、中文界面和测试。

CAD 用 mm，实体 profile 导出为 m，44轴顺序不变。当前自动检查不会把实物状态改为通过。无有限元或认证承载结论、无上电和精度实测、无本轮实体 UE Capture/Undo/重开验收；区域节点与网关尚未实现。

## 仅更新机械设计

本轮新增 -MechanicalOnly 开关。配合参数为 mechanical_manifest/print_fit_profile_revB.json；由 CAD、后续试片、图纸和敏感性报告共用。

在仓库根目录执行 Hardware/PoseDoll44/tools/Build-Hardware.ps1 -Regenerate -MechanicalOnly，会重新生成 CAD，检查运动干涉、导出 STEP 的代表性孔径、参数情景和跨文件一致性，并更新报告。不会重建未改变的 PCB、固件或运行无关软件测试；既有报告仍保留。

不带 -Regenerate 则检查已有导出文件；输入哈希和 STEP/STL/ZIP 一致性用于发现过期产物。输出 fit_geometry_check.json 是名义几何检查，print_fit_sensitivity.json 是工程情景计算，均不能代替实物测试。

当前用户实测明确后置，脚本完成不再提示立即打印。

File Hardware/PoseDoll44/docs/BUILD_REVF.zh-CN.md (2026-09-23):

# Rev F 机械设计重建

在 `E:/UnrealProjects/DollSimulation` 运行：

```powershell
& ./Hardware/PoseDoll44/tools/Build-RevF.ps1
```

当前本机使用 Python 3.13 与已经安装的 CQ-editor 2.7 运行库。保持 CQ-editor 打开即可；脚本不安装依赖，也不写入 Python 模拟器环境。可用 `-Python` 指定兼容的 Python 3.13 路径。

构建按顺序执行：记录源码与依赖哈希 → 摩擦 / 测角组件 → 四套叉架 → 两款部分手臂 → 离线查看页及图像 → 汇总与负载检查 → 中文报告。请勿并行执行这些写入相同目录的脚本。

输出会覆盖 `generated/revF` 中同名文件、`verification/revF_*` 记录、中文 Rev F 报告和 `mechanical_manifest/dual_character_mechanics_revF.json`。Rev E 角色配置、原始 UE 参考网格、旧版 CAD、现有 UE 插件与模拟器不被改写。

当前源数据仍是上一轮从本地 Manny、Quinn 网格提取的尺寸，不需要重新打开 UE 导出。若角色资产或 Rev E 基准改变，应先重新完成 Rev E 比例验证，再重建 Rev F。

## 查看

- 双击 [离线三维页](../generated/revF/RevF_Mechanical_Review.html)：选 Manny / Quinn / 独立关节，拖动旋转、缩放、点击零件，或使用肘、腕滑块。
- CQ-editor 打开 [入口](../cad/revF/open_in_cq_editor.py)，设置 `VIEW='BOTH' / 'MANNY' / 'QUINN' / 'JOINT'`，再 Render。可修改 `ELBOW_DEG`、`WRIST_DEG` 看两个已装入转轴的姿态。
- STEP 总装及独立零件位于 [文件目录](../generated/revF/README.zh-CN.md)。本轮没有整机 STL 放行包。

独立关节脚本会检查 0° 至 330° 每 30° 的几何姿态，用来查找结构穿插。这不表示实际人偶允许整圈转动：线束、机械限位和多轴总装会限制范围。

汇总检查对无效几何、未解释的零件穿插、断开的打印实体、超过名义打印空间、改变的前臂长度和构建期间改变的源码返回失败。摩擦计算使用尚未验证的系数，报告只针对已装入部件；构建成功也不会将制造放行设为 true。

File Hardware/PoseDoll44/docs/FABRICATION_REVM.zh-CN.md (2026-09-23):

# Rev M 制造与检验说明

本文件是两款完整原型的制造约束，配合各角色的 `manufacturing_manifest.json`、逐件 STEP 和采购分类表使用。**交付状态为数字原型候选，不是已完成实物鉴定的量产图纸。** 加工方应先反馈可加工性、检验方案和报价；不要直接把整套文件当作已批准订单。

## 制作方式

| 类别 | 制作方式 | 接收条件 |
|---|---|---|
| `frame`、`shell` | 0.4 mm 喷嘴、PLA 原型打印 | 使用 `print_candidates` 中已摆放的 STL；不缩放 |
| `aluminum_7075` | 7075-T6 / T651 精密加工 | 材料证明，精加工轴颈和配合孔；不以打印塑料替代 |
| `aluminum` | 6061-T6 精密加工 | 精加工摩擦面、键形配合与螺纹 |
| `pom` | POM-C 车/铣轴套 | 区分自由尺寸与装配压缩尺寸；压入后检验工作内孔 |
| `peek` | 未填充 PEEK 摩擦片 | 按 STEP 切出止转耳；厚度、平面度、干摩擦实测 |
| `steel_17_4` | 17-4PH，H900，磨削接触面 | 热处理证明，去毛刺；不得用普通镀锌垫片代替 |
| `brass` 隔柱、键件 | 黄铜精密加工 | 定制高度与小螺纹；不要按最近的整数长度替换 |
| `nylon` 压片 | PA12 / 尼龙板切削或合适精度的 PA12 工艺 | 0.8 mm 等薄片不列入 PLA 打印清单；边缘夹板应平整 |
| `silicone` 垫片 | 硅胶片模切 | CAD 是安装后的厚度；线夹垫自由厚 0.5 mm、装后约 0.4 mm |
| 碟簧、标准螺丝、磁铁、止推垫圈 | 标准件采购 | 按物料表规格及尺寸包络检查，不能仅凭螺纹直径替换 |
| 电子件 | 成套贴装 PCBA 和预压接线束 | 按原生 KiCad 工程及线束工单，交付通断与上电记录 |

`metal`、`spring` 等 CAD 色彩分类不都是一个采购类别。例如 `spring_seat` 是定制座，`disc_spring` 才是采购碟簧。采购分类表会区分两者。模型中的 PCB 电阻、电容与连接器不要再按机械零件重复采购。

胸框、颈部转接框等复杂 7075 件当前按整体加工几何交付，需要多面装夹/多轴加工，局部可由线切割、电火花或精密孔加工配合完成。它们不是普通桌面打印件，也没有声称三轴铣床一次装夹可做完。加工方如要求拆件，必须先给出拆分和连接方案，再回到 CAD 验证；不得现场自行锯开、焊接或更换材料。早期注释中的“machining split pending”不代表当前文件已经包含拆分件。

## A1 mini 打印安排

每款有 187 个独立打印候选文件，包括重复实例。全部名义外包络都可放入 180 × 180 × 180 mm，检查另给 X/Y 各留 3 mm 裙边空间。这个结果只证明包络能放入，未执行 Bambu Studio 实际切片，也未验证支撑、局部翘曲和打印强度。

- 导入后执行切片器的“落到平台”与居中，不缩放；少量工艺圆筋会使 STL 最低点略低于名义 Z=0，记录中保留实际最小坐标。
- 初始层高 0.20 mm，喷嘴 0.4 mm；骨架 6 道墙、40% 填充，壳体 6 道墙、15% 填充。孔位、细壁和薄保持盖应在切片预览确认确实形成连续路径。
- 两条约 23 cm 的小腿梁以三维对角方向放置，不能平放后强行缩小。导出的 STL 已变换姿态；清单 `print` 项记录旋转、平移、包络和支撑复核要求。
- Manny 右小腿梁当前含 3 mm 裙边的最大名义尺寸约 179.55 mm，距 180 mm 只余约 0.45 mm；这是最紧的一件。实际切片若支撑越界，先调整朝向/支撑或借用更大热床，不能缩短骨长。
- 斜放长梁需要支撑；仅包络通过不能保证切片器生成的支撑仍留在热床内。首件切片应由设计端复查支撑足迹和层间受力，不要求你猜。
- 测角板、轴颈、摩擦面、弹簧座、配合孔不是靠“打印高精度”解决。打印件不承担 1,656 N 关节轴向预紧。
- 打印孔允许后续按实际螺钉/螺母检验和修整；工作轴孔由金属座和加工轴套定义。第一次只做一个关节和一根受力梁的工艺验证。
- 不把整套文件一口气排成打印任务。先通过高负载关节与梁的阶段测试，再安排其余部件。

打印件使用的是暂定 PLA 工艺。打印朝向、不同品牌材料、温度和层间结合会改变强度；CAD 与填充百分比不能提供额定负载。下面的载荷验收先于全身使用。

## 关键尺寸与公差候选

STEP 中的螺纹以名义圆柱/底孔表示，并未建螺旋牙。加工方必须按螺纹标注攻牙，不能把 1.6 / 2.5 mm 底孔当作已经完成的 M2 / M3 内螺纹。常规公制粗牙为 M2×0.4、M3×0.5；金属内螺纹 6H、外螺纹 6g，精度由检验确认。

| 功能 | 原型加工与检验要求 |
|---|---|
| 光滑 D4 / D6 轴颈 | 名义尺寸 0 / −0.01 mm；Ra ≤0.8 μm，去掉毛刺；工作面不可带螺纹 |
| 捕获式 D6 轴套工作孔 | Ø6.06 +0.02 / 0 mm；装后转动验收；法兰名义轴向游隙 0.15 mm |
| 捕获式 D4 轴套工作孔 | Ø4.06 +0.02 / 0 mm；具体法兰和座以当前 STEP 为准；不能套用 D6 法兰尺寸 |
| 16 处肩部压入式轴套 | 金属孔名义 +0.000…+0.010 mm；POM 自由外径比名义大 0.025…0.035 mm；装后精修 Ø4.04 或 Ø6.04 工作孔 +0.02 / 0 mm |
| 压入式轴套保持 | 10 N 轴向拉出验收目标；检查温度变化和重复摆动后是否松脱。这是验收要求，尚无测得通过值 |
| 轴向堆叠关键面 | 加工候选 ±0.02 mm，接触面平面度 ≤0.02 mm；最终按实际碟簧与摩擦片测厚选垫 |
| PEEK 摩擦片 | 名义厚度见 STEP；厚度候选 ±0.02 mm；无毛刺、无油，摩擦面配合件 Ra 0.8…1.6 μm 候选，最终由持姿测试决定 |
| D 形传角配合 | 当前模型一般留 0.05 mm 单侧候选间隙；加工后逐对检验回差，不用胶填充代替键面受力 |
| 传感器安装 | 芯片对磁铁的名义面间距 1.5 mm；装后目标 1.5 ±0.2 mm，同轴偏心目标 ≤0.15 mm；最终以磁场诊断和测角误差验收 |
| 小传感器板 | 12 ×10 mm，板厚 1.0 mm，要求供方确认 ±0.1 mm；39 块，板边夹持 |
| 大传感器板 | 18 ×20 mm，板厚 1.6 mm；2 块，仅肩外展；SH6 插座方向与小板工程分别确认 |
| 区域板 / 电源板 | 40 ×86 ×1.2 mm / 40 ×70 ×1.6 mm；壳体尺寸不可按旧版板形加工 |

每款 6 个打印件的名义几何有零厚度相切边，STL 已用半径 0.10 mm 的小圆筋闭合，并附 `_print_process.step` 工艺实体。它们位于一侧前臂、四片前脚掌盖和电源背盖；变化记录在 `verification/revM_print_mesh_export.json`，整机干涉及质量另行回算。打印以这些 STL 为准；不要把名义 STEP 重新粗糙网格化后替换它们。此处理只解决网格与几何有效性，细部能否形成连续挤出线仍要切片复查。

这些是原型拟定的加工要求，不是从打印机宣传精度推导出的保证值。轴套自由态尺寸覆盖 CAD 中的安装态外径；不要重复叠加补偿。传感器板托需要随实测 PCB 厚度选择薄绝缘垫，不能通过拧弯 PCB 来补厚度。

## 关节预装与防松

腰、胸关节使用两处 PEEK 摩擦面。六个碟簧分成两个方向相反的组，每组三片同向套叠；不要误装成六片全部同向。名义 1,656 N 是两组串联后的轴向力，不再乘以二。所有材料和结构都以最终整机导出件为准，历史 `components/H6P4` 不能替代当前腰部版本。

轴向保持螺钉必须在轴向夹具支撑下装配，确认止挡帽坐到金属端面、螺钉没有触底，并验证完整啮合长度。装配方按力—位移/堆叠高度控制预紧，再测旋转扭矩；**没有给新手一个可盲拧的通用拧紧扭矩。** 预装关节应随附每轴的起动/运行扭矩、回差和 30 分钟下垂记录。

全金属小螺纹的可拆防松选用少量 LOCTITE 222 候选，由加工方在塑料和摩擦片装入前施用、清除溢胶并充分固化；不得让胶进入轴套、PEEK 摩擦面、传感器或磁铁间隙。尼龙件、塑料附近螺母不涂这种厌氧胶，采用合适的预涂尼龙防松螺纹或机械保持，并验证拆装次数。胶与表面处理的相容性先做小样。[Henkel 使用范围与技术资料](https://datasheets.tdx.henkel.com/LOCTITE-222-en_GL.pdf)

磁铁按 Ø6×2.5 mm、径向充磁、相容的 AS5000-MD6H-2 候选采购并检验；外径、厚度和磁场以到货记录确认。杯内薄胶层只负责防止磁铁打滑，外侧保持盖负责防脱。胶种选 3M Scotch-Weld DP460 Off-White 双组分环氧作为原型候选，由预装方按配比和批次技术资料室温固化，先做镀镍磁铁/铝杯样件的相容性、收缩和滑移测试。不要靠高温加速固化，也不要用瞬干胶临时代替后省略测试。该胶用于防转，不能据产品粘接强度推算整个人偶的结构强度。[3M 产品与技术资料](https://www.3m.com.cn/3M/zh_CN/p/d/b40066439/)

## PCB 交付给贴片方的要求

四套自包含 KiCad 工程位于 `generated/revM/electronics`，均附 ERC、DRC 和原理图/PCB 一致性结果。`fabrication_candidate` 中的 Gerber、钻孔文件供工程审查，不能单凭“零 DRC”跳过制板工艺确认。

区域板是四层 1.2 mm。USB 差分阻抗目标 90 Ω，要求制板方给出实际叠层/铜厚/阻抗计算；电源芯片散热焊盘中的过孔要求填孔并封盖，或经复核后修改工艺。未确认叠层时，不把当前走线宽度当作受控阻抗已经达标。

两种传感器板背面的 C2 指定 Murata GRM219R61E106KA12D，限制高度已进入机械模型；不可用同容值但更厚的 0805 电容直接代料。其他封装匹配的替代器件也要核对电压、容量降额、容差、引脚和最大外形。

区域/电源板原生导出的 `board_native.step` 尚缺少 5 / 1 个供应商三维模型；完整人偶 CAD 已补入相应最大外形包络。裸 `board_native.step` 不是完整 PCBA 的干涉依据，电子元件也不是可以 CNC 加工的实体。

供电为外置 **稳压 5 V、至少 3 A、带短路保护**的适配器；5.5/2.1 mm 插头，中心正。仅接低压输出，不制作市电部分。3 A 保险丝不是对限流 3 A 电源“必定熔断”的保证；电源自身短路保护仍须存在。USB VBUS 不给人偶电源母线供电。

## 量化实物验收入口

参考 `verification/revM_load_work.json` 的每轴重力需求。原型目标为实测保持扭矩 ≥该轴预算重力需求的 1.5 倍；运行阻力不宜比设计名义扭矩高 20% 以上，起动/运行阻力比目标 ≤1.5。它们是本项目的验收目标，不是已验证性能。

首件装配方需要验证高负载保持螺钉/螺纹、轴的键槽与横孔、反力垫片、小框架转角及 PLA 层间承载。简化强度筛查不覆盖应力集中、跌落、疲劳和长期蠕变，不能给整机贴上额定负载。按[测试与校准步骤](BUILD_AND_CALIBRATE_REVM.zh-CN.md)分阶段填写记录，失败的部件回到设计端修改。

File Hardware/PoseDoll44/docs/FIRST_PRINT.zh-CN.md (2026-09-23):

# 留待设计完成后的打印设置 · Rev B

**当前不要求打印或测量。** 用户暂无合适工具，设计按 [工程假设](DESIGN_BASIS.zh-CN.md)继续。本文件保存未来使用的设置，不是现在的操作任务。

基线：A1 mini、0.4 mm 喷嘴、普通 PLA。实际喷嘴或材料改变时，由设计端更新配方。STL 单位 mm，已放在 Z=0。

| 项目 | 未来首轮设置 |
|---|---|
| 材料与温度 | 对应实际耗材的 PLA 预设；记录品牌、颜色和预设 |
| 比例与朝向 | 100%，保持原始朝向，平面朝下 |
| 层高 | H1-001 0.20 mm；H1-002、H1-003 0.10 mm；首层均 0.20 mm |
| 墙数、顶底层、填充 | 3 墙；各 5 层；20% 网格或 Gyroid，记录所选 |
| 支撑 | 关闭 |
| Brim | 通常关闭；翘边的试片不用于判断配合 |
| XY 孔/外轮廓补偿 | 均为 0 mm；候选装配余量已进入 CAD |
| 自动圆孔/轮廓补偿 | 关闭，避免叠加未经标定的修正 |
| 象脚补偿 | 保留所选预设并记录 |
| 速度 | 正常模式，记录预设 |

没有更改用户切片软件中的实际设置。以上约定适用于未来这套试片，不是所有模型通用的最佳设置。

## Rev B 识别和孔位

H1-001 为 110×74×6 mm，五排孔。左下为 6 mm 大切角、右上为 3 mm 小切角；从下到上 M2、M3、M4、M6、POM。每行五个孔的数值见 [孔位图](../generated/drawings/coupon_map.svg)，不要再使用旧版“统一加 0.1 mm”的读法。

H1-002 为 86×40×8 mm，同样有两个切角。上排 M3 螺母槽对边 5.8 / 6.0 / 6.2 / 6.4 mm、深 2.8 mm；下排磁铁槽直径 6.0 / 6.2 / 6.4 / 6.6 mm、深 2.6 mm。

H1-003 从左到右为 1 / 1.5 / 2 / 2.5 / 3 mm 的厚度片；设计不变。0.10 mm 层高用于保留这些半毫米厚度及 H1-002 的槽深。

## 后续如何使用

设计端会先确定实际五金和装配测试包，再说明哪些试片需要打印。届时分别导入对应文件，检查孔未封住、方向正确，不自动缩放。

螺丝孔直接用实际 M2/M3/M4/M6 螺丝轻推，不能旋拧着切入塑料。POM 座用实际轴套，螺母和磁铁槽用对应实物。不同配合用途分别判断，不需要额外的四根测试圆棒。

先记录冷却后的原始结果，不钻、磨、涂胶后当原始数据。记录方法保存在 [测量表](MEASUREMENT_RECORD.zh-CN.md)。这张试片不能代替长孔、完整装配、定位和承载验证。

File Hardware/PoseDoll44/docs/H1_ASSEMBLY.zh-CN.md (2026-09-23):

# H1 单轴机构：结构审查稿

状态：机械配合 Rev B，采用 A1 mini / 0.4 mm / PLA 的未标定假设继续设计。**当前无需用户打印或测量**；完整装配、承载与实物性能尚未验证。设计端继续完善结构、五金和测试包，实物测试安排在设计完成之后。

总装

## 机构与编号

底座/背柱支撑上叉。M6 螺栓穿过固定黄铜套，两只 POM 轴套让转子转动。上下摩擦环夹持转子，上叉中的 3 个 M3 调节螺钉推动钢压环。压紧力在装配时调整，日常摆姿无需反复锁紧。

从中心向外的关系是：**M6 螺栓 → 中空黄铜固定套 → POM 轴套 → 打印转子**。螺栓负责紧固；光滑的黄铜外圆与 POM 内孔构成预定的转动接触面，螺纹不直接充当这里的转动表面。POM 是轴套所用的工程塑料，轴套在打印转子内的保持方式仍需验证。

这份草案没有采用 Ø3/6/8/10 mm 四根实心圆棒，也没有规定全部 44 轴共用该轴系。孔径试配直接复用实际装配件：螺丝通孔用对应螺丝，轴套座用实际 POM 轴套；黄铜套与 POM 的转动配合用两件实物检查。Rev B 试片改为 M2/M3/M4/M6/POM 五行，覆盖当前候选孔径；原先无用途的 8 mm 行已移除。现阶段只保留这些文件，不要求用户测试，详见 [设计依据](DESIGN_BASIS.zh-CN.md)。

磁铁桥跟随转子转动，圆盖防止磁铁脱出。圆磁铁还需合格胶接防自转，仅靠圆孔和盖子无法保证角度不滑移。胶种与胶接试验未冻结。

传感器托架固定在支撑臂上，四处 M3 支点可调整高度，调整后锁紧。自制 PCB 的芯片面朝磁铁；商城评估板需要独立适配，不能直接替换。

| 编号 | 名称 | 数量 |
|---|---|---:|
| H1-010 | 底座 | 1 |
| H1-011 | 背柱 | 1 |
| H1-012 | 上叉，含 3 个 M3 螺母位 | 1 |
| H1-013 | 转子与 95 mm 试验力臂 | 1 |
| H1-014 | 磁铁桥 | 1 |
| H1-015 | Ø17×0.8 mm 圆形磁铁盖 | 1 |
| H1-016 | 传感器支撑臂 | 1 |
| H1-017 | 54×56×4 mm 托架，自制板孔距 26 mm | 1 |
| H1-018 | 通用边夹试样，未纳入装配证明 | 2，可选 |
| H1-019 | 止挡块 | 2 |

## Rev B 配合尺寸

普通打印通孔 M2=2.6、M3=3.6、M4=4.8、M6=6.8 mm；多片背柱支架 M3=3.8 mm。上叉 M3 螺母槽对边 6.0、深 2.8 mm。

POM 座仍为 10.2 mm，磁铁座仍为 6.2 mm、深 2.6 mm，分别保留定位/保持设计任务。黄铜套内径 6.4 mm 是金属零件尺寸，不受打印通孔规则影响。参数来自 [统一配合配置](../mechanical_manifest/print_fit_profile_revB.json)，不能把这些数值称作用户打印机的实测公差。

## 主轴尺寸链

Z=0 为底座顶面，单位 mm。见 [尺寸链图](../generated/drawings/axial_stack.svg)。

| Z 范围 | 零件 |
|---|---|
| -6～0 | 底座 |
| 0～31 | 黄铜固定套 OD8 / ID6.4 / L31 |
| 0～3、3～4.5 | 下钢环 t3、t1.5，OD32 / ID10.4 |
| 4.5～6 | 下摩擦环 t1.5 |
| 6～25 | 转子；POM 轴套在 6～12 与 19～25 |
| 25～26.5 | 上摩擦环 t1.5 |
| 26.5～28、28～31 | 上钢环 t1.5、压环 t3 |
| 31～36 | 上叉 |
| 59.4～61.9 | Ø6×2.5 径向磁铁 |
| 62～62.8 | 塑料盖 |
| 63.2～64.4 | 朝下的 AS5048A 封装高度包络 |
| 64.4～66 | 1.6 mm 自制 PCB |
| 66～70 | PCB 托架 |
| 71～76 | 支撑臂 |

名义磁铁表面到芯片封装面 1.3 mm，其中包含 0.8 mm 塑料盖；盖到芯片净空仅 0.4 mm。**这不是公差结论**：板厚、封装高度、盖翘曲、磁铁厚度和胶层都必须实测，再调高度。其他元件、接头及线束也须留空。

## 放行后装配顺序草案

1. 对照五金工单和试片记录核对尺寸；不允许靠敲打修配。
2. 固定底座，装固定套、下钢环、下摩擦环，夹紧背柱。
3. 装转子/POM 轴套、上摩擦环、钢环和压环。主轴夹紧力经固定套传递。
4. 装上叉的 3 组调节螺钉，轮流微调；预紧值和测试载荷需结构审查，不给新手猜测值。
5. 装止挡和磁铁桥，完成胶接和机械封装；固化后验证磁铁不能相对转子转动。
6. 装传感器托架和已焊 PCB，断电检查 0～145° 净空与线束余量。
7. 接线、受保护供电与磁铁封装通过核对后才诊断；再安排审查后的带载和耐久试验。

数字扫角为 0～145°、间隔 5° 的 30 个姿态，已修正方盖碰接头的问题。尚未覆盖连续扫角、全部螺母/螺钉头部、工具空间、线束、变形与打印误差。槽壁、层间强度、压紧蠕变、摩擦系数和磨耗均需实物验证。

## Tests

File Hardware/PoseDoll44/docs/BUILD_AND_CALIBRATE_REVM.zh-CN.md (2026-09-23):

# Rev M 构建、分阶段验收与校准

现在无需你购买量具、接线或打印整机。以下是数字设计完成后的执行顺序；当前通过的检查都保存在 `verification`，没有把合成数据写成真实传感器校准。

## 本地重建

本文命令在独立 `design/` 仓库根目录运行；首次环境检查优先使用根目录 `scripts/Build-Design.ps1`。机械生成入口是 `Hardware/PoseDoll44/cad/revM/final_model.py`，整机导出是 `export_complete.py`。不能独立运行一个早期关节脚本，再把它的旧输出混入本次总装。

当前电脑的 CAD 运行器 `tools/run_cad.py` 借用正在打开的 CQ-editor 中的 CadQuery 运行环境；关闭或升级 CQ-editor 后可能需要重新定位环境。可长期复现的替代方式是安装 CadQuery 2.7.x、NumPy 与 VTK，直接执行同一生成脚本。当前导出已留 STEP，读模型不依赖原临时运行环境。

在仓库根执行的命令示例：

```powershell
python -X utf8 Hardware/PoseDoll44/tools/run_cad.py Hardware/PoseDoll44/cad/revM/final_model.py
python -X utf8 Hardware/PoseDoll44/tools/run_cad.py Hardware/PoseDoll44/cad/revM/export_complete.py
python -X utf8 Hardware/PoseDoll44/tools/run_cad.py Hardware/PoseDoll44/cad/revM/audit_complete.py
```

完整重建可使用 `tools/Build-RevM.ps1 -Stage All`；也可选择 CAD、Electronics、Firmware、OfflineTests、Reports。最后运行 `-Stage Delivery`，在本地 8874 服务开启时检查三维页面和零件下载，并核对全部来源后生成最终报告与哈希清单。默认阶段只运行 OfflineTests，不连接硬件。Delivery 遇到旧报告、失败结果或缺件会停止，不自动冒充通过。

审核报告记录所用 CAD 输入的 SHA-256；改过几何后，旧报告不再证明新模型通过。缓存只读取本地生成且输入哈希一致的文件。最终交付清单另外记录电子文件和固件，不把“CAD 没变”当作电路没变。

查看器要通过 HTTP 打开，不能双击 `file://` 后依赖浏览器跨文件读取。当前服务地址为 `http://127.0.0.1:8874/generated/revM/RevM_Full_Body_Review.html`。服务不在时，在 `Hardware/PoseDoll44` 目录运行 `python -m http.server 8874 --bind 127.0.0.1`，再打开上面的本地地址。

## 阶段 1：高负载关节首件

由加工/预装方做一套最终版本的腰部双摩擦面关节，使用实际碟簧、摩擦片、轴套、保持螺钉和磁铁托。你收到可直接转动的装配件，自己不压装 1,656 N 的弹簧堆。

| 项目 | 方法 | 原型目标 |
|---|---|---|
| 起动与运行扭矩 | 拉力计垂直拉动已知力臂，扭矩=力×力臂；正反向各 5 次 | 保持扭矩 ≥整机预算需求×1.5；运行阻力不高于名义值的 1.2 倍；起动/运行比 ≤1.5 |
| 保持 | 在预算重力扭矩下保持 30 分钟，记录开始/结束角度 | 漂移 ≤1°，无可见松动 |
| 回差 | 在同一参考角正反向靠近，卸去操作力后读角度 | 差值目标 ≤1°，不能靠滤波隐藏机械松动 |
| 预压件 | 加工方用轴向夹具检查金属力路及螺纹 | 名义预紧×1.5 的试验载荷后无永久变形、拉脱、滑牙；这不是要求用户手压测试 |
| 往复 | 首轮 500 次、中期 5,000 次缓慢往复 | 记录扭矩衰减、掉粉和松动；变化 >20% 或保持不合格即返工 |

阈值是本项目的候选验收标准，尚未测得通过。PEEK 摩擦系数 0.15 是计算假设，若实物不足，不应简单无限增加预紧；要一起复核材料、接触面与轴系应力。

## 阶段 2：单传感器、区域板和最长线束

建议由贴片方先完成限流上电、短路/焊接检查及基本读数，交付测试记录。将一块传感器板与一个区域板按本版线束连接，用完整设计中的最长传感器线验证，不以一根 10 cm 台架线代替。

- 磁铁/芯片间距、偏心、磁场强弱、AGC/错误标志和角度重复性逐项记录；传感器 14 位分辨率不等于人偶实际精度。
- 连续运行至少 30 分钟，记录供电电压、3.3 V、输入电流、板内温度和错误计数。六节点组合后复核总输入、最远板端电压、保险和 PTC 温升。
- 150 mA MCU 预算、80% 降压效率、接触电阻和实际线长均需核对。设计中 200 mA 的敏感性结果不是已满足全部电源余量的承诺。
- 250 kHz SPI 只是初始设置；示波器查看最远线的时钟、CS、MISO 振铃/建立时间。降时钟频率不能自动消除容性负载或边沿问题。
- 拔掉一个传感器应显示 `missing` / `invalid`；重新接线前先断电。故障不能变成“零度正常”。

## 固件与诊断

`generated/revM/firmware/node1…node6` 是对应 N1…N6 的独立镜像包，附各自 `manifest.json` 和原始 `flasher_args.json`。芯片 ESP32-S3，Flash 8 MB，DIO 80 MHz；映像地址来自构建输出：bootloader `0x0`，partition table `0x8000`，应用 `0x10000`。不得把 N1 的应用烧到六个节点，也不要复制设备身份。

固件源码在 `Firmware/PoseDollFullBody`，按 `tools/build.ps1 -Node 1` 到 `-Node 6` 构建。现有六组镜像已在 ESP-IDF 6.1 编译成功；没有执行任何烧录。首次烧录、BOOT/RESET 操作和首次通电由熟悉板卡的装配方完成，实际端口确定后再给出该设备的命令，不在文档里硬编码一个可能指向其他设备的 COM 口。

`Tools/PoseDollHardwareBridge/Open_Full_Diagnostic.cmd` 打开诊断窗口。窗口需要你明确选择设备和连接；当前设计流程没有自动打开串口。其作用是查看 44 个协议槽位、节点到齐、磁场故障并记录原始数据。前三槽始终是骨盆固定参考，其余 41 槽才是测量。

离线检查已有记录：

```powershell
python Tools/PoseDollHardwareBridge/full_diagnose.py --help
```

本轮新增校准工具只处理记录文件，不会连接串口或 UE。它也不烧写 AS5048A 的 OTP 零点。

## 阶段 3：单肢与完整结构

先做一条手臂、一条腿及它们的实际外壳、线夹和导线。分别从各运动轴下游抓握稳定骨段，检查轴的正反方向、限位、保持、梁弯曲和层间裂纹；不要用传感器板或磁铁盖作把手。安装顺序见 [装配说明](ASSEMBLY_REVM.zh-CN.md)。

PLA 受力梁在最终切片姿态下做静载及缓慢往复；把最不利操作扭矩传到梁上，记录弹性挠曲和卸载后的残余变形。先由装配方做预算静载的 1.5 倍样件证明试验，不把未经验证的完整人偶举起来承重。薄壳只提供抓握外形，不代替内部承力梁。

随后制作一款完整人偶，验证站、坐、躺的相对姿势和外部支撑安排。先用额外支撑物承住重量，不能期待人偶自由站稳。相邻机构/线束被夹属于返工项；左右手臂、腿等非相邻部位的接触可改变姿势避让，查看器会保留这类提示。

## 41 轴零点与方向校准

让预装方使用可溯源量角工具或按金属键面制作的夹具，对每轴建立至少三个已知参考角。固定其余轴，参考角是**该机械轴相对固定侧的角度**，不是在屏幕上目测手臂方向。量角不确定度目标 ≤0.5°。推荐参考值见各角色 `calibration_reference_plan.csv`；并未给它们填入传感器实测值。

每个角度保持不动，诊断窗口记录至少 30 个连续有效样本。下面以左肘 0° 的一个记录为例（其他角度/轴都须单独采集）：

```powershell
python Tools/PoseDollHardwareBridge/calibrate_pd41.py observe --character manny --axis elbow_l.flex --angle-deg 0 --input elbow_l_0.bin --out elbow_l_0.json
```

程序拒绝丢帧/坏帧、少于 30 个样本、故障轴或原始波动大于 0.4° 的记录。三个参考角至少跨 20°、不超过 160°，拟合仅求零点和正负方向，增益固定为 1；参考残差必须 ≤1°，不会用增益或曲线拟合掩盖装配问题。

收集全部 41 轴的观察 JSON 后，保存成一个数组文件 `observations_all.json`，生成新目录：

```powershell
python Tools/PoseDollHardwareBridge/calibrate_pd41.py build --character manny --observations observations_all.json --assembly-id Manny-001 --out Hardware/Calibration/Manny-001
python Tools/PoseDollHardwareBridge/calibrated_pd41.py --bundle Hardware/Calibration/Manny-001 --input full_body.bin --out calibrated_recording.jsonl
```

第二条命令只做离线转换。新配置包包含机械 profile、校准、能力文件和实测记录，绑定角色、设备 ID、装配编号与 profile 字节哈希；已有输出目录不会被覆盖。设备重启、旧序号、不同设备、被修改的 profile、缺失轴都会被拒绝或显式标成无效姿势。不会沿用上一帧假装当前有效。

校准中前三个骨盆通道明确固定为零，原始值为空，不参与零点拟合。现实中将整个人偶平躺，输出不变；场景内所有整体平移和旋转都用 UE Placement 调整。

## UE 接入的验收边界

本轮没有修改当前运行的 UE 项目、正在使用的 Shared 配置或已经测试通过的模拟器。当前插件按固定路径/文件名读取配置；实体校准包必须与 UE 端一起选择并用相同字节哈希握手，不能把一个硬件零点文件随意覆盖进旧虚拟配置。

新增工具完成的是原始 PD41 → 经过校准的现有姿势协议的**离线转换**。串口到 UE 的正式实时桥接、设备选择界面、Quinn 专属 Control Rig/资产绑定和真实硬件 Capture 持久化仍需接入测试，不能声称已经实机通过。Quinn 的机械比例已经使用 Quinn 参考骨架；这不等于软件中的 Manny 绑定文件自动变成 Quinn 绑定。

实物接入后复做原项目验收：不同动作捕获到 Sequencer，关闭输入程序并重启 UE 后仍有可编辑 Control Rig 关键帧；手指/面部保持原控制。测角误差、手感与硬件总延迟另记，不由“能连上”代替。

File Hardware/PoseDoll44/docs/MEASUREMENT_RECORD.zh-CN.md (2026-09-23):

# 未来实物测试记录 · Rev B

> 历史试片记录：下列尺寸仅对应 Rev B，不是 Rev M 整机制造参数。当前设计、实际装配件及首件测试顺序请从 [Rev M 交付入口](../START_HERE.zh-CN.md) 和 [制造与校准验收](BUILD_AND_CALIBRATE_REVM.zh-CN.md) 阅读；保留本表，不要求现在补打旧试片。

**当前不用填写，也不用购买工具或测试件。** 用户要求先完成设计，之后再进行实测。以下保留为未来模板，所有结果目前都是“未测”；设计继续使用 [暂定参数](DESIGN_BASIS.zh-CN.md)。

最终测试物、零件版本和需要测的项目由设计端在装配测试包中写明。孔里装什么，就用那个实际零件；取消额外准备四根圆棒的要求。

## 测什么，以及为什么

打印孔和实际五金的尺寸可能有偏差。用实际装配件试配，是为了选择可装配的尺寸并发现松动；不要求你自行确定公差。

螺丝通孔需要允许穿过，轴套座需要保持轴套，磁铁座还需要定心及防自转。所以“紧配”不总是更好，“能滑动”也不自动代表全部接口合格。后续整关节的转动、持姿和耐久测试另行安排。

## 对应当前 Rev B 试片

H1-001 左下大切角、右上小切角，共五行，外形 110×74×6 mm。下表从下到上，孔值从左到右 A～E，单位 mm。

| 孔行 | A / B / C / D / E 设计孔径 | 实际测试物 |
|---|---|---|
| M2 | 2.20 / 2.40 / 2.60 / 2.80 / 3.00 | 最终选定的 M2 装配螺丝 |
| M3 | 3.20 / 3.40 / 3.60 / 3.80 / 4.00 | 最终选定的 M3 装配螺丝 |
| M4 | 4.40 / 4.60 / 4.80 / 5.00 / 5.20 | 最终选定的 M4 装配螺丝 |
| M6 | 6.40 / 6.60 / 6.80 / 7.00 / 7.20 | 最终选定的 M6 装配螺丝 |
| POM10 | 10.00 / 10.10 / 10.20 / 10.30 / 10.40 | 实际 POM 轴套，候选外径 10、内径 8.05、长 6 mm |

当前普通通孔选 M2=2.6、M3=3.6、M4=4.8、M6=6.8 mm；多片支架 M3=3.8 mm。POM 座暂为 10.2 mm，它的保持设计尚需完善。以上值全部由试片覆盖，但这不表示已在打印机验证。

旧 Rev A H1-001 是四行、110×58×6 mm，包含本轮无用途的 8 mm 行；不能按新表读旧件。已有旧件可保留，不要求现在补打。M5 暂无 H1 实物用途，因此不增加 M5 的测试或采购任务。

H1-002 上排六角槽对边 A～D 为 5.8 / 6.0 / 6.2 / 6.4 mm，深 2.8 mm；下排磁铁槽直径为 6.0 / 6.2 / 6.4 / 6.6 mm，深 2.6 mm。分别使用实际普通 M3 六角螺母和选定的 Ø6×2.5 mm 磁铁。槽深与 CAD 候选一致，但不能自动替代不同打印方向的实际零件验证。

H1-003 五片厚度依次 1 / 1.5 / 2 / 2.5 / 3 mm，只用卡尺测厚度，不测连体底座。

## 以后怎样记录

### 螺丝通孔

同一行 A～E 用同一颗螺丝。孔冷却后，从顶面轻推，不旋拧、不敲、不磨合。最终处于孔中的光杆/螺纹段需要能穿过 6 mm 厚度，安装时要经过孔的螺纹段也需要能够直接通过。

| 填写值 | 现象 |
|---|---|
| 进不去 | 轻推不能穿过；只进端头或卡在出口也算，注明位置 |
| 紧配 | 能直接穿过并拔出，但持续有明显阻力 |
| 能滑动 | 很小的手力就能来回移动，不要求靠自重掉下 |
| 明显晃动 | 孔口可见相对松动；不用长螺栓远端撬孔 |
| 未测 | 没有对应实物、未尝试，或试片有缺陷 |

通孔有间隙不自动不合格，“紧配”也不是目标。若有阻力同时又松动，备注两种现象。保留第一次结果，不靠旋拧切出螺纹再记为“能通过”。

### 轴套、螺母与磁铁

- POM 轴套：记录装入深度和“进不去 / 能轻压装入 / 能自由滑入 / 明显晃动 / 未测”。两面保持可接近，轻试而不硬压卡死；只试入口就只记录入口。6 mm 长轴套不要求像长螺丝一样从另一端伸出。
- M3 螺母：记录“不能放到底 / 能到底且基本不转 / 能到底但明显转动 / 未测”。普通螺母候选对边 5.5、厚约 2.4 mm，不能混用法兰或尼龙锁紧螺母；只用手轻试。
- 磁铁：记录“不能平放到底 / 能到底且无明显侧隙 / 能到底但明显侧向松动 / 未测”。只使用最终选定的磁铁，不另买不明磁铁填表。

黄铜套外圆与 POM 内孔之间的转动配合，以后直接使用这两个装配件检查，不能由打印孔试片推断。

## 空白记录表

- 日期、试片版本：Rev __；打印机 / 实际喷嘴：
- 耗材品牌、型号、颜色：
- 切片版本、预设、层高、墙数、填充、速度：
- XY 孔/轮廓补偿、自动圆孔补偿、象脚补偿：
- 工具与已知精度（不知填未知）：
- 实际螺丝/轴套/螺母/磁铁型号、来源：
- 照片：顶面切角方向、侧面、底面：
- 外形尺寸及可见缺陷：

| H1-001 孔行 | A | B | C | D | E | 备注：深度、入口/出口 |
|---|---|---|---|---|---|---|
| M2 | 未测 | 未测 | 未测 | 未测 | 未测 | |
| M3 | 未测 | 未测 | 未测 | 未测 | 未测 | |
| M4 | 未测 | 未测 | 未测 | 未测 | 未测 | |
| M6 | 未测 | 未测 | 未测 | 未测 | 未测 | |
| POM | 未测 | 未测 | 未测 | 未测 | 未测 | |

| H1-002 | A | B | C | D | 备注 |
|---|---|---|---|---|---|
| M3 螺母槽 | 未测 | 未测 | 未测 | 未测 | |
| 磁铁槽 | 未测 | 未测 | 未测 | 未测 | |

| H1-003 厚度 | 第1次 | 第2次 | 第3次 |
|---|---|---|---|
| A 1 mm | 未测 | 未测 | 未测 |
| B 1.5 mm | 未测 | 未测 | 未测 |
| C 2 mm | 未测 | 未测 | 未测 |
| D 2.5 mm | 未测 | 未测 | 未测 |
| E 3 mm | 未测 | 未测 | 未测 |

不把敲、钻、磨、涂胶后的结果填写为原始打印结果。当前这些空白记录不会阻止继续设计，也不能用社区数据代填。

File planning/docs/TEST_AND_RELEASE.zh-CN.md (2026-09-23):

# 分阶段实施、验收与交付

所有指标是初始工程目标，不是已达到的性能。结果初始为 `not_run`。若指标不合理，可基于用户任务和测试能力提出带理由的设计变更；不得为了让失败测试变绿而静默放宽标准。

## H0：完整架构与供应商尺寸落地

先审阅本地仓库与工具环境，建立完整 44 轴布局、6+1 节点位置、线束通道、支架、机械轴变换、负载/供电/通信预算。选择传感器、磁铁、轴、摩擦件、接头和板子候选，记录准确外形与接口。没有原始供应商尺寸的地方明确标记为占位。

检查关键姿势的可达性，重点检查肩部/髋部三轴、相邻磁铁、手臂举高时的线束和板子。确定是否需要调整轴布局；调整通过正式版本化物理 profile，不修改旧软件基准。

输出：全身预览、架构与风险报告、采购候选及原始资料、H1 具体试件和小量采购申请。此时不放行全身机械件和 44 套电子件。

## H1：打印工艺与标准单轴模块

打印孔径、螺母位、传感器座、轴套配合、摩擦垫安装等小试片。用户只需按说明插入指定量规/轴/螺丝，记录松紧和卡尺尺寸。零件不合适应改参数重打，不让用户靠无记录打磨来“修好”。

制造一个按最终模块接口设计的单轴关节、一个明确高度可调的传感器/磁铁定位夹具。验证持姿、滑动手感、机械间隙、角度方向、跨零、静止噪声和传感器诊断。台架使用预焊模块，后续正式小板保持相同测角原理，不要求测试模块外形等于最终 PCB 外形。

首轮物料建议为少量传感器（例如 3 颗用于后续三轴试验，另 1 颗备件）、配套磁铁、两套预焊 MCU/收发器用于节点和网关台架、一个关节的标准五金及小量打印材料。此为数量规划，不是型号已确认的采购单。确切料号、预焊要求、兼容性和价格由 H0 冻结后交用户批准。

## H2：紧凑三轴结构、磁场和耐久风险

尽早制造与整机相同间距和安装方向的紧凑三轴组件。三颗都真实通电，逐轴固定/扫描，检验邻轴角度变化造成的误差。把模拟其他身体部位的磁铁按最坏接近距离加入试验。必须验证线束与实际金属轴/螺丝，不能只测没有五金的空塑料架。

同时测试肩部关键姿势、关节互相带动、奇异位置附近的手感、机械硬限位、线束回弹和反向间隙。失败时先改结构；不进入大量打印，避免把失败模块复制 44 次。

## H3：完整单侧肢体与承载链

使用正式架构接口，完成一侧肩带+手臂的 9 轴以及一侧腿脚的 7 轴，可分两个试件。再对骨盆/腰支架使用等效配重测试下游载荷。节点位置、最长线束、接头和供电方案按整机预定方式，而不是台架最短线。

按抬手、扶额、伸手、转手掌、叉腰、坐姿等任务测试它是否真正省操作。记录摆姿势所需步骤和时间、是否要一直扶住相邻关节、是否误碰线束和是否需要每次拧螺丝。仅“读数正确”不足以通过交互验收。

与 UE 联调时明确区分真实和实验补全轴。不能把混合输入作为完整硬件通过的证据。

## H4：完整 44 路电气台架

在分批确认 PCB 与小量贴装后，先组装完整 6 节点+网关+44 传感器台架，线长按整机最坏长度。验证实际供电、电源温升、CAN 负载、采集窗口、端口错误和完整轴身份。

测试拔除传感器/区域、节点重启、USB 拔插、错误哈希、CRC 损坏、epoch 回绕、总线拥塞和长时间运行。无效端口不可变成正常零值或永远复用旧值。测试每一区域短路保护时使用合适限流设备，由熟悉电气操作的人执行；不指导新手用金属短接电源。

首次全板通电建议使用限流电源或经过核实的受保护供电测试工装；普通墙插适配器不应被当作可调限流实验电源。无此设备时由代工/技术人员完成初次电源验证后再交用户插接。

## H5：整机装配、校准与 UE 工作流

分批装配全身，逐区域自检再合上维护盖。最后进行全身最坏姿势磁场复验，因为非相邻模块也会靠近。完成 44 轴校准，保存实际模块版本、映射、profile 与 calibration 哈希。

最终验证：物理摆姿势→UE预览→Capture→Undo/Redo→再次采集→关闭硬件/桥接/MCP→重开 UE→播放并手动修改 Control Rig。确认已有虚拟模拟器仍然可用，正常工作时不依赖 MCP。

## H6：持续使用与维修验证

做至少一次长时间带电与姿势保持测试，以及关节循环摆动、再次校准、替换传感器和线束的维修演练。关注摩擦衰减、壳体开裂、插头松动、磁铁移位和温升。通过短期测试不等于获得多年寿命或工业安全认证。

## 初始量化目标

| 项目 | 初始目标 | 测量与限制 |
|---|---|---|
| 单轴绝对误差 | 合格有效范围内 ≤1.5° | 必须有独立角度基准；基准不确定度应明显小于指标，建议 ≤0.3° |
| 重复到位与反向差 | ≤0.5° | 同一已知姿势从两方向到达，记录多次分布而不只取最好值 |
| 静止角度噪声 | 10 秒窗口 RMS ≤0.15° | 去均值、不隐藏原始数据，注明滤波设置 |
| 邻近磁铁引起的角度变化 | 固定待测轴，变化 ≤0.3° | 与独立机械固定证据同时记录，必须扫描多种邻轴姿态 |
| 持姿漂移 | 声明最坏工作负载下 5 分钟 ≤1° | 另外验证设计保持扭矩覆盖 1.5 倍重力预算；不要超过已审查的试件载荷 |
| 初期磨损筛查 | 1000 次循环后仍达标 | 记录摩擦扭矩/间隙前后变化；不据此推算多年寿命 |
| 完整硬件采样 | 内部目标 100 Hz，UE 输出 60 Hz | 统计完整 cohort，不把重复旧帧计为新采集 |
| 采集时间窗口 | ≤5 ms | 区分芯片内部采样、节点读取和主机接收时间 |
| CAN 稳态占用 | <60% | 由实测统计，报告错误与重发；不只引用公式 |
| 故障可见性 | 检测后 100 ms 内报告/阻止有效采集 | 需要结合现有 UE 状态机做实测，旧连接超时机制不能被绕过 |
| 全链路耐久运行 | 至少 60 分钟 | 保留日志、丢帧、无效轴、重连和错误计数 |

若没有足够精度的角度参考，先以重复性和可用性验收，并将绝对精度保持 `not_verified`，不能把打印的角度刻度当作精密检定证书。

## 每轮给用户的交付格式

每个试制包包含一个中文 `START_HERE`，清楚写“本轮只做什么、不做什么”。提供确切 BOM 与购买确认、编号零件、打印方向/参数、爆炸图、针脚视图、装配照片或可信渲染、程序上传步骤、自动检测界面和测量记录表。

每步说明必须写期望现象与停止条件。例如“只连接 N3，运行检测，应看到 P01–P09；若电流超限/板子明显发热/闻到异味，立即断电，不继续插入其他模块”。不用用户猜测线序、用手感觉是否烫得正常，也不鼓励在通电状态摸裸露电路。

用户反馈格式统一为：零件与版本、照片（带标尺/方向）、程序导出日志、测量值、执行到哪一步、是否在拆装前断电。我们根据证据改设计，不要求用户自己决定应该改哪个电阻或打磨哪个孔。

## 放行原则

全部采购、打印及制造文件绑定到本轮版本和审批状态。检查到图纸不一致、关键供应商资料缺失、磁场串扰超标、失效姿势被隐藏、供电未审查或规则检查严重错误时，不出全身生产包。

散落磁铁应机械封装并远离儿童、宠物和易受磁场影响的物品；带尖角/夹点的关节应加保护。用户不需要打开电源适配器、焊接芯片或执行危险电源故障试验。

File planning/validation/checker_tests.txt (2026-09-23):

test_baseline (test_check_plan.PlanChecks.test_baseline) ... ok
test_duplicate_axis (test_check_plan.PlanChecks.test_duplicate_axis) ... ok
test_false_hardware_pass (test_check_plan.PlanChecks.test_false_hardware_pass) ... ok
test_missing_checkout (test_check_plan.PlanChecks.test_missing_checkout) ... ok
test_missing_region_index (test_check_plan.PlanChecks.test_missing_region_index) ... ok
test_overloaded_bus (test_check_plan.PlanChecks.test_overloaded_bus) ... ok
test_port_collision (test_check_plan.PlanChecks.test_port_collision) ... ok
test_premature_release (test_check_plan.PlanChecks.test_premature_release) ... ok
test_wrong_can_format (test_check_plan.PlanChecks.test_wrong_can_format) ... ok
test_wrong_order (test_check_plan.PlanChecks.test_wrong_order) ... ok

----------------------------------------------------------------------
Ran 10 tests in 0.005s

OK

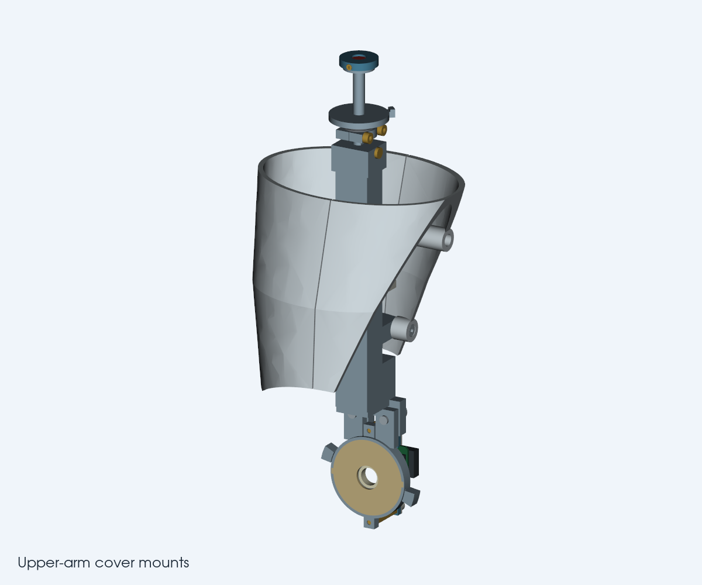
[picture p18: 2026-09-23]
Hardware/PoseDoll44/verification/arm_mount_probe.png

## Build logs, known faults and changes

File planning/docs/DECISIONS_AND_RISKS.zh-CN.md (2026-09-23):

# 决策、风险与尚未冻结的内容

## 架构已定、制造参数待定

已定：完整44轴、6区域+1网关、有线被动关节、同轴绝对测角为基线、独立实体profile、不覆盖虚拟测试、CLI-first、先全身布局再分阶段制造。

待定：精确高度和比例、每个模块轴径/摩擦材料/扭矩、磁铁与PCB安装尺寸、最终机械限位、传感器具体采购后缀、MCU具体模块、收发器/稳压器/保护器件、连接器料号和针脚、线径、PCB层数、外接电源额定电流、实际成本。这些不是让用户自己填空，而是 Codex 在对应设计阶段必须解决的任务。

## 核心风险及前置试验

| 风险 | 为什么会影响体验 | 处理与退出条件 |
|---|---|---|
| 关节撑不住或太难掰 | 读数准确但无法舒适摆姿势 | 负载与手部操作力一起预算，H1/H3 实测 |
| 密集磁铁串扰 | 另一个关节运动导致本轴假运动 | H2 密集组件及整机靠近姿势实测；先改间距/位置，不用单一零点掩盖 |
| 串联三轴不好操作 | 数学可表示但实体轴接近重合 | H0/H2 关键姿势与轴顺序评估，必要时版本化更改机械布局 |
| 线束拖拽或疲劳 | 姿势回弹、端口断续、焊点断裂 | 把真实线束加入 CAD/扭矩/循环试验，限定行程并应力释放 |
| FDM 配合与长期变形 | 关节松紧变化、定位不稳定 | 配合试片、金属预紧路径、可换摩擦件和循环持姿试验 |
| SPI 多支路信号质量 | 单轴台架通过、全区域随机错误 | 驱动/电容/最长线审核；缓冲/分组/端口隔离按需要设计 |
| CAN 被画成星形 | 电气可靠性依赖偶然线长 | 明确干线/终端/短支路和组装标识，不把外形拓扑当电气拓扑 |
| 电源压降/USB反灌 | 重启、损坏电脑或区域器件 | 完整功耗与保护电路，受控初次通电，未经确认不并联电源 |
| UE 仍用虚拟校准 | 实体角度系统性错误却看似连通 | 新配置选择、设备身份和哈希握手，旧模拟器保持回归 |
| 自动工具产生伪通过 | 只有有效文件，没有有效硬件 | 原始证据、独立复核、not_run 与实测通过分离 |

## 不采用的捷径

不把十几个 IMU 贴在普通娃娃上作为本版基线；不把一颗三维磁场传感器默认等同于任意球关节三轴测量；不使用电位器读数精度/寿命未经评估的替代；不把44根I²C长线与多路开关简单堆叠作为整机方案；不将全部几何一次打印成不可维修的人偶；不为了“AI全自动”而自动下单和远程打印。

若 AS5048A 的供货、体积或磁场效果不满足目标，可以更换编码器或局部关节结构，但仍需真实提供该轴的绝对测量、诊断和经验证的机械变换。替换不得偷偷减少目标轴数或伪造与原先相同的精度。

## 精度边界

最终角色误差还包括连杆弹性、机械背隙、磁铁定位、安装基准、角度测量、身体比例映射与用户摆姿势误差。单颗芯片的位数不能覆盖这些因素。手的位置误差也不能只由一个关节角度误差简单代表；肩/肘误差会沿长链累计。完整手部位置精度需在目标模型、测量空间和姿势集确定后单独定义。

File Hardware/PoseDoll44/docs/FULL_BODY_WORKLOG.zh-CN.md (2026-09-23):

> **以下是按时间保留的设计历史，旧进度与旧估算不代表当前状态。** 当前两款完整数字候选的文件及验证结果见 [Rev M 交付入口](../START_HERE.zh-CN.md) 和 [最终报告](../verification/REVM_REPORT.zh-CN.md)。

# 全身设计工作记录

目标：继续完成 Manny / Quinn 两款完整人偶的数字设计。不能以局部版本完成代替整个人偶完成。

已定约束：沿用两款 1:2 骨架比例；刚性节段包壳、活动区裸露；不设计固定外部支架；A1 mini、0.4 mm、PLA 是首轮打印候选。现在不要求用户打印、采购或测量。

2026-09-23 接续基线：Rev L，12/44 轴参与局部运动，6 路肩部测角安装。现有肩带与双臂基线保持可追溯。

待闭合：
- 肘部持姿、传角与传感器真实安装，前臂旋转、手腕与手。
- 肩带测角及预紧、轴向保持，臂壳固定。
- 躯干、颈头、骨盆、髋膝踝前脚掌和稳定节段外壳。
- 无固定支架条件下的骨盆三方向来源与重校准规则。
- 全身线束、区域电路、供电、装配与维修路径。
- 两款完整 CAD、材料/零件清单、打印拆分、接线及固件接口。
- 比例、连接、邻接运动、工具路径、静载估算和数据质量检查。

所有版本都区分：实际实体、电子元件尺寸包络、线束空间、未设计部位。CAD 通过不等于持姿、磁场、耐久和打印公差已实测。

## 本轮已落地的工作（进行中）

- `cad/revM/compact_axis.py`：直接测角摩擦组件，有 S6/M6/H6 及加强碟簧组合；金属闭合预紧路径、D 形驱动、轴向螺钉、磁铁正向保持、真实小板与板夹。
- `assembly_core.py`：44 轴 FK 放置、明确的零件归属、M3 安装面与窄范围螺纹接触例外、BRep 实体碰撞。
- `arm_integration.py`：双肘直接测角、前臂旋转，保持原骨骼中心；上臂与既有肩部 D 形联接合成同一打印件。
- `wrist_integration.py`：两轴手腕中间框，板托可转 90°；实际手指端点方向的手掌骨架。
- `hand_shells.py`：两片刚性手掌、M2x16 螺钉及捕获螺母、骨架安装平面。外形是简化静态手形，不增加手指输入。

目前新文件和 `generated/revM` 都是迭代工作件，不能视为发布版或制造放行。Quinn 的肘部/前臂首轮五个姿态通过；手腕的首轮动作检查通过，少量安装面问题随后继续修正。完整两款组合动作、载荷、工具路径、臂壳固定、线束仍需闭合。Rev L 保留为上一个已整理的局部查看版本。

2026-09-23 用户已确认：以骨盆局部正前方为人偶前方；整体平移、左右转向、前后倾斜和侧倾全部由 UE Placement 调整。无需 IMU、无需外部朝向跟踪；将骨盆 3 路设为明确的固定参考，其余 41 路为关节测量。必须保留 fixed / missing 的区分。

Rev M 腿部已加入髋三轴、膝、踝双轴和前脚掌，共 14 轴；当前机械活动覆盖 32 路，直接测角安装 28 路。腿部骨架仍待骨盆连接、外壳、载荷、完整姿态和工具检查。当前正在修正放大的金属输出耳与打印安装面间隙。

补充进度：新建 trunk_integration.py、neck_module.py 和 body_integration.py。颈部在 Quinn 的 9 个局部姿态中无未计划实体交叠。腰胸首次上置回转布局局部通过 8 姿态，但全身检查与肩带冲突，正在重新排列；不能把先前局部通过结果当作当前全身通过。body_integration.py 已写入骨盆、胸和颈连接，尚未运行通过。root_reference 的 4 项接口语义测试在模拟器现有 venv 中通过。

载荷与材料进度：首版全身 Quinn CAD 实体估重 1.86273 kg，另有 0.61 kg 显式预留；腰屈伸按任意重力方向最差约 2.0192 Nm，原 H6P3 名义持姿比仅 1.38。现在 waist 改 H6P4、chest 改 H6P3，尚待最新质量和动作复查。窄腰胸/髋框、骨盆框及胸框改列 aluminum_7075 候选；长骨、轻载连接和外壳仍为打印候选。这不是制造强度放行，尤其要补应力、圆角、螺钉承压与可加工性检查。用户已经通过进度消息得知需要委托金属加工，但没有进行采购或外部联系。

当前连续框架覆盖全部 41 个相对关节轴的几何运动；传感器直接安装 37 处（31 个新模块 + 6 个旧肩部），肩带 4 处以及肩带/肩扭转预紧仍未完成。颈部 yaw 模块下移量最终候选 36 mm；颈部局部 9 姿态通过。胸框固定梁中间点改为颈部基点 +[27,20,-42]，路由探针对肩带和头部 4 姿态通过；完整两款检查待运行。

全身连接最新检查：body_integration.py 两款各 10 姿态完成。站姿（双臂外展 15°）、坐姿、腰胸前弯/后仰/侧弯、头点头/抬头、髋后摆 -30°、髋外展 65°的新增躯干/骨盆/颈部相关交叠为 0。严格 N 姿态存在手腕与骨盆接触（Manny 42、Quinn 16 个零件对），属于远端肢体姿势限制，但全局碰撞分类尚未落实；不能静默忽略。此检查只覆盖 affected 集合的新增身体结构，不是所有零件所有动作验证。

最新载荷（尚未含肩扭转新增件）：Quinn 模型 1.99332 kg + 0.61 kg 暂估外壳/节点/线束。预留质量现在放于各肢段中部，head +70 mm、chest +65 mm。现已纳入全部 41 轴；肩带四轴和肩扭转两轴的未知预紧单独标空。已完成关节最小名义保持比约 1.574（原 Rev L 肩部）、腰屈伸 1.711、髋约 1.75；均为假设 μ=.15 的数字预算，无加速度/线束弹力/磨损保证。

新建 twist_completion.py：在连续全身上补左右肩扭转弹簧，SCHNORR001200 对置两片，294N 名义。将原肩外展环+扭转固定摩擦面融合为同一 7075 金属件；顶部用0.20mm CuSn8止推垫片保持现有编码器气隙。原先 M4 端部锁紧螺母因为D4轴端和一体磁铁杯阻挡无法装入，已取消。现在用D3/flat1.1凹槽、两半侧装止挡环、两颗M2x8，将闭合预紧与上臂连接分开；正在做碰撞/装配检查。不要发布旧螺母方案。剩余肩带四轴仍未实现。

关键更正：肩带集成发现 chest_M_body_frame 的旧末段布尔合并把下方约 16,390 mm³ 梁段丢失，但 OpenCascade 仍返回单一有效实体。已定位到颈部上升梁与胸框连接处，改为明确搭接，并加入输入实体保留与体积守恒核对。此前基于丢失胸框的 body/load 报告已经过时，不能作为全身验证结论；恢复完整胸框后必须重新运行。肘部安装板远端角做 R3 后，Quinn 五个动作（含145°）通过。肩带新四轴仍在整机集成检查。

本轮继续：girdle_cartridge.py / girdle_integration.py 已加入四路肩带 D4 测角、1114 N 碟簧候选、可拆磁铁杯、轴端保持和安装螺钉。左 yaw 从根部 -45 移至 -35 mm，同轴下轴承同步抬高 10 mm；右 yaw 保持 -76 mm。四路已集成，但仍需肩颈组合动作闭合、工具/装入检查及强度与配合审查。

full_packaging.py 为目前最靠后的构建入口；不要把早期 body_integration.py / girdle_integration.py 单独运行结果当作整机最终版本。胸部 pitch→roll 拱改到前方；头 pitch 输入安装面移到颈基点上方，roll 模块沿自身轴外移，颈部组件整体绕竖轴旋转 180°，并保持真实 head_tip 参考点。胸框固定颈部安装面也同步翻转。头部 yaw 固定螺钉在替换时明确补回，不能仅保留支架而缺少两颗螺钉。

新增 fuse_checked / union_checked 同时检查输入体积和原实体是否被保留；修复后的原胸框从约 7,472 mm³ 恢复为完整框架后重新构造。旧 body/load 报告不适用于新结构。cad_cache.py 保存带源文件、真实传感器 STEP 与角色尺寸依赖的 BRep 工作缓存，供迭代使用；不是可制造交付件。

全身诊断接口：network_revM.json 已固化 41 个测量端口和三路骨盆固定参考；NETWORK_REVM.zh-CN.md 记录六区、CAN/SPI、电源候选和批次约束。pd41_protocol.py 的 10 项诊断测试、can_cohort.py 的 8 项同步批次测试通过；缺失、故障、旧帧、重启不能补成有效姿势。当前只是离线 Python 参考，未实现/编译全身 C 固件，未画完区域板，未接串口或向 UE 发送数据。

碰撞分类：新增 revM/collision_review.py，按相邻身体区段分类，保留全部原始接触。手腕↔骨盆及左右独立肢体可列姿势限制；肩颈、左右肩带、肘腕、髋骨盆和未知归属仍为结构问题。8 项分类边界测试通过。旧 Rev L 分类和报告保持原样。

还必须补齐：所有关节的物理硬限位/线束过转保护；不可把配置中的软件角度范围冒充已经做出的机械限位。选用金属框后须重新审核原来为 PLA 留的轴套孔补偿，不能沿用 0.3 mm 松配而称为加工配合。整体单一金属框还需要可加工分件/图纸、圆角、紧固与装入顺序。外壳、壳体固定、线束、区域电路、制造清单和全机强度/公差/动作检查仍未完成，继续推进，不发布为完整成品。

最新颈部方向更正：大体积 S6 颈部在真实抬头角度下仍会干涉，已由 neck_light.py 的 T4 轻载直接测角模块替代。输出 D4 孔和下一级轴承壳合并为同一金属连接件；POM 轴套带捕获凸缘，仍需要加工配合和应力审核。最终候选 yaw 沿轴下移34 mm，pitch/roll沿自身轴38 mm，整套机构朝后布置，真实头顶点和三轴中心保持原位。独立颈部34个单轴/组合姿态无交叠；放回Quinn肩胸后的首批7姿态也无交叠，完整检查尚在运行。不要继续使用此前 S6 头部结果。

腰部负载补充：加入弯肘前伸动作后，旧18姿态估算并不足够。新的旧 S6 头全身估重2.13473kg +0.61kg预留，waist.pitch最大2.6254Nm，H6P4名义保持比1.416。因此H6P4摩擦外半径从16增至18mm，同时保持原安装孔位、轴承中心和2208N预紧候选。需要重新校验实体间隙和完整质量，不能把增大尺寸本身记为验证通过。

继续结果：颈部T4 yaw=34、pitch/roll=38 的后向结构，独立组合测试通过。胸架颈梁最终候选从 C[-57,10,35] 经侧方/前方，前侧 X=Cx+65 上升到 Nz−22，再从 N[15,0,−22]→[15,0,−30]→[6.3,0,−30] 接入固定壳；不再从肩部旋转包络中穿过。Manny肩颈34姿态无相邻接触；Quinn后收下压存在上臂后壳对胸梁约39.49mm³接触，需按全身分类保留或修壳。

H6P4摩擦半径18mm后，原输出M3螺母碰到法兰。输出孔中心半径由20改22mm，输出耳相应加长，固定侧安装孔与各转轴中心保持原位。两款孤立腰胸各8姿态（含静态装配）已无交叠。旧载荷约1.64倍只是前一支撑梁版本，最终总装质量须再计算。

full_body_audit.py 新建：实际1766个零件/实体包络的全身检查；合并旧六路与新35路，Manny41路实际芯片和磁铁端面+369项FK读数核对通过。完整总装的首轮静态60条接触全部是旧RevI-L未建螺旋牙的螺纹外径/底孔包络；legacy_threads.py 明确列出60个对应螺纹副，不使用“旧零件全部忽略”。全体移动零件和其他同体接触仍然检查。首轮正在运行，尚不能宣布整机动作通过。

Firmware/PoseDollFullBody：纯C组包与批次核心9场景测试通过，C/Python黄金包逐字节一致。ESP-IDF6.1新esp_twai接口的N1网关、N3九路节点已编译成功；其余节点代码共用，仍需最终各节点构建。CAN发送缓冲区在TX回调和wait_all_done完成后才复用，发生错误先销毁旧驱动队列并更换同步epoch，旧批次不得填补新数据。未连接串口、未烧录、未与UE通信。

2026-09-23 继续：rigid_shells.py 补入大腿前壳和小腿前/下后壳。大腿后侧及膝后近端75mm不包壳；两款各7个腿部测试姿态没有相邻机构交叠，Manny髋外展时的手/腿接触保留为姿势限制。head_shells.py 采用角色头部表面截面形成可拆两片壳，下前50mm、下后47mm留空；骨架斜杆另有0.3mm避让。胸架前梁从颈基点下22mm降到下40mm。两款各28个头部组合姿态和静态装配无交叠。

完整裸骨架扫描仍在运行，发现Manny最大手腕侧偏时原手壳下缘碰前臂，不能视为通过。rigid_shells.py 已让手壳侧壁从掌长49%处开始，同时保留9mm宽中央安装舌；专门两款各10个腕姿态检查已完成，待汇总分类。完整扫描用的是先前裸模型，尚未包含本次腿/头/手壳修正，后续需要统一总装复查。

Firmware/PoseDollFullBody 六个独立配置均已编译成功并记录二进制/源码SHA256；generate_config.py 检查端口索引与网络清单一致。N6一次编译子进程异常，限制为4个编译任务后成功。未连接或烧录硬件。network_revM.json现采用外部5V必需、USB只通信，取消旧LM66100并联供电候选，改为TS3USB221E受USB VBUS控制的数据开关，不给电脑USB端口加全身供电负担。

电子区域板：build_regional_revM.py 已产生原生 KiCad 142元件/123网络通用九路节点原理图，ERC零违规；当前40x86x1.2mm四层板仍在布局/布线，尚未与人偶总装匹配，不能制造。Freerouting2.4.1仅下载到项目tools/vendor，SHA256与官方发布一致251101c3eeac22d7e7dfcf6796603279e5d1000283eb82d8f093780f7afc6aa9，后续只使用本地CLI并关闭分析数据。

travel_stops.py 是新的限位候选，尚未启用到总装。限位直接加在轴承眼和承重法兰，不经磁铁杯传力。首版下置挡块碰到输出螺母，已停止该检查，正在改为法兰外沿上凸台/固定挡块的组合，仍须角度端点、相邻干涉和应力检查。尚未解决其他13个G4/T4/旧肩轴的限位。

2026-09-23 补充：28 个通用承重限位在 Manny、Quinn 均完成端点及各轴最小/最大位置检查，各 196 个端点检查、57 个装配姿势检查，相关结构干涉为 0；非相邻限制保留。手部侧壁起点改为 max(49% 掌长,45.5 mm)，双人物各 10 个弯腕/侧偏组合结构检查为 0。其余 13 个轴限位仍未完成。区域 PCB 初次离线布线后原生 DRC 为 0 错误、16 处未连接，正在完成电源引出及关键走线审查；不得作为可制板文件使用。

Rev M 收尾：两款各 1,999 实体、187 个 PLA 打印候选，41 测量轴。新增六组臂壳 M2×20 安装，18 项臂段工具/螺母进入检查各通过；模型源 fd87be52ab22。按真实端点生成每款 52 条线束；55 项 Python 与 9 个 C 核心场景通过，六节点最终镜像重建成功。比例复核保留全部 1:2 骨长；机械颈枢轴是 neck_01/neck_02/head 均值，不得把它直接当 UE head 骨位置比较。635 个离线骨链比较样本保留头部 14.32 / 16.52 mm 最大位置差异，1% 位置目标未达，不能宣称全姿态逐点一致；具体最终碰撞和制造边界见交付报告。

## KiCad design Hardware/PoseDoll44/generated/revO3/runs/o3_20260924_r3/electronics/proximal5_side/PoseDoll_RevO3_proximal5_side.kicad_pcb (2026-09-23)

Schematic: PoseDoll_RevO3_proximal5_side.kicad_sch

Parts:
C1: 10u X5R 25V / CL21A106KAYNNNE; C_0805_2012Metric
C2, C4: 22u X5R 16V / CL21A226MOYNNNE; C_0805_2012Metric
C3, C5, C7, C21, C22, C23, C24, C25, C50, C51: 100n X7R; C_0603_1608Metric
C6: 1u X7R; C_0603_1608Metric
D1: PESD5V0S2BT,215; SOT-23
J1: 5V protected N3/N4 branch; not 12V qualified; JST_PH_B2B-PH-SM4-TB_1x02-1MP_P2.00mm_Vertical
J2: CAN IN / GND-L-H; JST_GH_BM03B-GHS-TBT_1x03-1MP_P1.25mm_Vertical
J3: CAN OUT / GND-L-H; JST_GH_BM03B-GHS-TBT_1x03-1MP_P1.25mm_Vertical
J11: P1 sensor / CS GPIO2; JST_SH_BM06B-SRSS-TB_1x06-1MP_P1.00mm_Vertical
J12: P2 sensor / CS GPIO4; JST_SH_BM06B-SRSS-TB_1x06-1MP_P1.00mm_Vertical
J13: P3 sensor / CS GPIO5; JST_SH_BM06B-SRSS-TB_1x06-1MP_P1.00mm_Vertical
J14: P4 sensor / CS GPIO6; JST_SH_BM06B-SRSS-TB_1x06-1MP_P1.00mm_Vertical
J15: P5 sensor / CS GPIO7; JST_SH_BM06B-SRSS-TB_1x06-1MP_P1.00mm_Vertical
J50: SM14B-SRSS-TB / SHR-14V-S / SSH-003T-P0.2-H; JST_SH_SM14B-SRSS-TB_1x14-1MP_P1.00mm_Horizontal
JP1: CAN TERM: close endpoints only; SolderJumper-2_P1.3mm_Open_Pad1.0x1.5mm
L1: LSXND4040TKL2R2MDG / 2.2uH; L_Taiyo-Yuden_NR-40xx
R1, R2, R4, R113, R117, R123, R127, R133, R137, R143, R147, R153, R157, R526, R527, R528, R529: 10k; R_0603_1608Metric
R3, R116, R126, R136, R146, R156: 100k; R_0603_1608Metric
R5: 120R 1% 0.33W / CRCW0603120RFKEAHP; R_0603_1608Metric
R110, R111, R112, R120, R121, R122, R130, R131, R132, R140, R141, R142, R150, R151, R152: 100R; R_0603_1608Metric
R114, R115, R124, R125, R134, R135, R144, R145, R154, R155: 47k; R_0603_1608Metric
R500, R501, R502, R503, R510, R511: 100R source damping candidate; R_0603_1608Metric
R530: 0R option / direct tri-state return; R_0603_1608Metric
TP1: UART_TX; TestPoint_Pad_D1.0mm
TP2: UART_RX; TestPoint_Pad_D1.0mm
TP3: GND; TestPoint_Pad_D1.0mm
TP4: PG; TestPoint_Pad_D1.0mm
TP5: EN; TestPoint_Pad_D1.0mm
TP6: BOOT_N; TestPoint_Pad_D1.0mm
U1: ESP32-S3-WROOM-1-N8; ESP32-S3-WROOM-1
U2: TPS62162DSGR; Texas_DSG0008A_WSON-8-1EP_2x2mm_P0.5mm_EP0.9x1.6mm
U3: TCAN332DR; SOIC-8_3.9x4.9mm_P1.27mm
U11, U12, U13, U14, U15, U50, U51: SN74LVC125ABQAR; DHWQFN-14-1EP_2.5x3mm_P0.5mm_EP1x1.5mm

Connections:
/+3V3: C2.1, C4.1, C5.1, C7.1, C21.1, C22.1, C23.1, C24.1, C25.1, C50.1, C51.1, J11.2, J12.2, J13.2, J14.2, J15.2, J50.13, J50.14, L1.2, R1.1, R2.1, R3.1, R4.1, R113.1, R117.1, R123.1, R127.1, R133.1, R137.1, R143.1, R147.1, R153.1, R157.1, R526.1, R527.1, R528.1, R529.1, U1.2 (3V3), U2.6 (VOS), U3.3 (VCC), U11.14 (VCC), U12.14 (VCC), U13.14 (VCC), U14.14 (VCC), U15.14 (VCC), U50.14 (VCC), U51.10 (3OE_N), U51.13 (4OE_N), U51.14 (VCC)
/+5V_IN: C1.1, C3.1, J1.1, U2.2 (VIN), U2.3 (EN)
/BOOT_N: R2.2, TP6.1, U1.27 (IO0)
/CAN_H: D1.2 (CAN2), J2.3, J3.3, R5.1, U3.7 (CANH)
/CAN_L: D1.1 (CAN1), J2.2, J3.2, JP1.2 (B), U3.6 (CANL)
/CAN_RX: U1.11 (IO18), U3.4 (RXD)
/CAN_TX: R4.2, U1.10 (IO17), U3.1 (TXD)
/CS1_MCU: R113.2, U1.38 (IO2), U11.1 (1OE_N), U11.4 (2OE_N), U11.10 (3OE_N), U11.12 (4A)
/CS2_MCU: R123.2, U1.4 (IO4), U12.1 (1OE_N), U12.4 (2OE_N), U12.10 (3OE_N), U12.12 (4A)
/CS3_MCU: R133.2, U1.5 (IO5), U13.1 (1OE_N), U13.4 (2OE_N), U13.10 (3OE_N), U13.12 (4A)
/CS4_MCU: R143.2, U1.6 (IO6), U14.1 (1OE_N), U14.4 (2OE_N), U14.10 (3OE_N), U14.12 (4A)
/CS5_MCU: R153.2, U1.7 (IO7), U15.1 (1OE_N), U15.4 (2OE_N), U15.10 (3OE_N), U15.12 (4A)
/CS6_MCU: R526.2, U1.12 (IO8), U50.9 (3A)
/CS6_REMOTE: J50.7, R502.2
/CS6_REMOTE_DRV: R502.1, U50.8 (3Y)
/CS7_MCU: R527.2, U1.17 (IO9), U50.12 (4A)
/CS7_REMOTE: J50.8, R503.2
/CS7_REMOTE_DRV: R503.1, U50.11 (4Y)
/CS8_MCU: R528.2, U1.18 (IO10), U51.2 (1A)
/CS8_REMOTE: J50.10, R510.2
/CS8_REMOTE_DRV: R510.1, U51.3 (1Y)
/CS9_MCU: R529.2, U1.22 (IO14), U51.5 (2A)
/CS9_REMOTE: J50.11, R511.2
/CS9_REMOTE_DRV: R511.1, U51.6 (2Y)
/EN: C6.1, R1.2, TP5.1, U1.3 (EN)
/GND: C1.2, C2.2, C3.2, C4.2, C5.2, C6.2, C7.2, C21.2, C22.2, C23.2, C24.2, C25.2, C50.2, C51.2, D1.3 (GND), J1.2, J2.1, J3.1, J11.1, J12.1, J13.1, J14.1, J15.1, J50.1, J50.3, J50.5, J50.9, J50.12, R114.2, R115.2, R116.2, R124.2, R125.2, R126.2, R134.2, R135.2, R136.2, R144.2, R145.2, R146.2, R154.2, R155.2, R156.2, TP3.1, U1.1 (GND), U1.40 (GND), U1.41 (GND), U2.1 (PGND), U2.4 (AGND), U2.5 (FB), U2.9 (PAD), U3.2 (GND), U11.7 (GND), U11.13 (4OE_N), U11.15 (EP_GND), U12.7 (GND), U12.13 (4OE_N), U12.15 (EP_GND), U13.7 (GND), U13.13 (4OE_N), U13.15 (EP_GND), U14.7 (GND), U14.13 (4OE_N), U14.15 (EP_GND), U15.7 (GND), U15.13 (4OE_N), U15.15 (EP_GND), U50.1 (1OE_N), U50.4 (2OE_N), U50.7 (GND), U50.10 (3OE_N), U50.13 (4OE_N), U50.15 (EP_GND), U51.1 (1OE_N), U51.4 (2OE_N), U51.7 (GND), U51.9 (3A), U51.12 (4A), U51.15 (EP_GND)
/LINK_MISO: J50.6, R530.1
/LINK_MOSI: J50.4, R501.2
/LINK_MOSI_DRV: R501.1, U50.6 (2Y)
/LINK_SCK: J50.2, R500.2
/LINK_SCK_DRV: R500.1, U50.3 (1Y)
/P1_CS: J11.6, R112.2, R117.2
/P1_CS_DRV: R112.1, U11.11 (4Y)
/P1_MISO: J11.5, R116.1, U11.9 (3A)
/P1_MOSI: J11.4, R111.2, R115.1
/P1_MOSI_DRV: R111.1, U11.6 (2Y)
/P1_SCK: J11.3, R110.2, R114.1
/P1_SCK_DRV: R110.1, U11.3 (1Y)
/P2_CS: J12.6, R122.2, R127.2
/P2_CS_DRV: R122.1, U12.11 (4Y)
/P2_MISO: J12.5, R126.1, U12.9 (3A)
/P2_MOSI: J12.4, R121.2, R125.1
/P2_MOSI_DRV: R121.1, U12.6 (2Y)
/P2_SCK: J12.3, R120.2, R124.1
/P2_SCK_DRV: R120.1, U12.3 (1Y)
/P3_CS: J13.6, R132.2, R137.2
/P3_CS_DRV: R132.1, U13.11 (4Y)
/P3_MISO: J13.5, R136.1, U13.9 (3A)
/P3_MOSI: J13.4, R131.2, R135.1
/P3_MOSI_DRV: R131.1, U13.6 (2Y)
/P3_SCK: J13.3, R130.2, R134.1
/P3_SCK_DRV: R130.1, U13.3 (1Y)
/P4_CS: J14.6, R142.2, R147.2
/P4_CS_DRV: R142.1, U14.11 (4Y)
/P4_MISO: J14.5, R146.1, U14.9 (3A)
/P4_MOSI: J14.4, R141.2, R145.1
/P4_MOSI_DRV: R141.1, U14.6 (2Y)
/P4_SCK: J14.3, R140.2, R144.1
/P4_SCK_DRV: R140.1, U14.3 (1Y)
/P5_CS: J15.6, R152.2, R157.2
/P5_CS_DRV: R152.1, U15.11 (4Y)
/P5_MISO: J15.5, R156.1, U15.9 (3A)
/P5_MOSI: J15.4, R151.2, R155.1
/P5_MOSI_DRV: R151.1, U15.6 (2Y)
/P5_SCK: J15.3, R150.2, R154.1
/P5_SCK_DRV: R150.1, U15.3 (1Y)
/PG: R3.2, TP4.1, U2.8 (PG)
/SPI_MISO: R530.2, U1.21 (IO13), U11.8 (3Y), U12.8 (3Y), U13.8 (3Y), U14.8 (3Y), U15.8 (3Y)
/SPI_MOSI: U1.19 (IO11), U11.5 (2A), U12.5 (2A), U13.5 (2A), U14.5 (2A), U15.5 (2A), U50.5 (2A)
/SPI_SCK: U1.20 (IO12), U11.2 (1A), U12.2 (1A), U13.2 (1A), U14.2 (1A), U15.2 (1A), U50.2 (1A)
/SW_BUCK: L1.1, U2.7 (SW)
/TERM_R: JP1.1 (A), R5.2
/UART_RX: TP2.1, U1.36 (RXD0)
/UART_TX: TP1.1, U1.37 (TXD0)

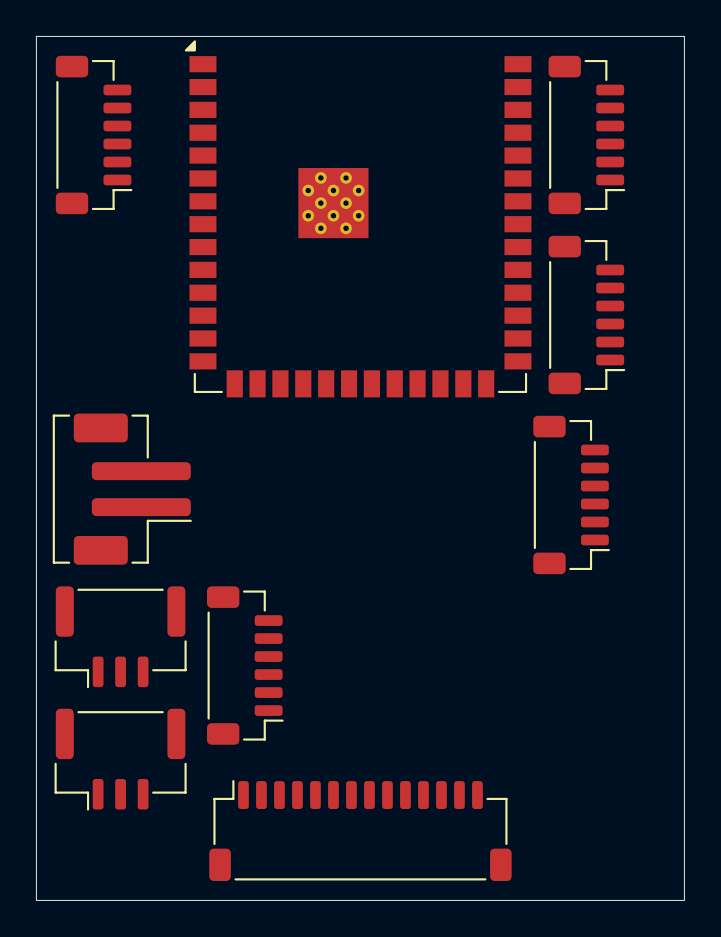
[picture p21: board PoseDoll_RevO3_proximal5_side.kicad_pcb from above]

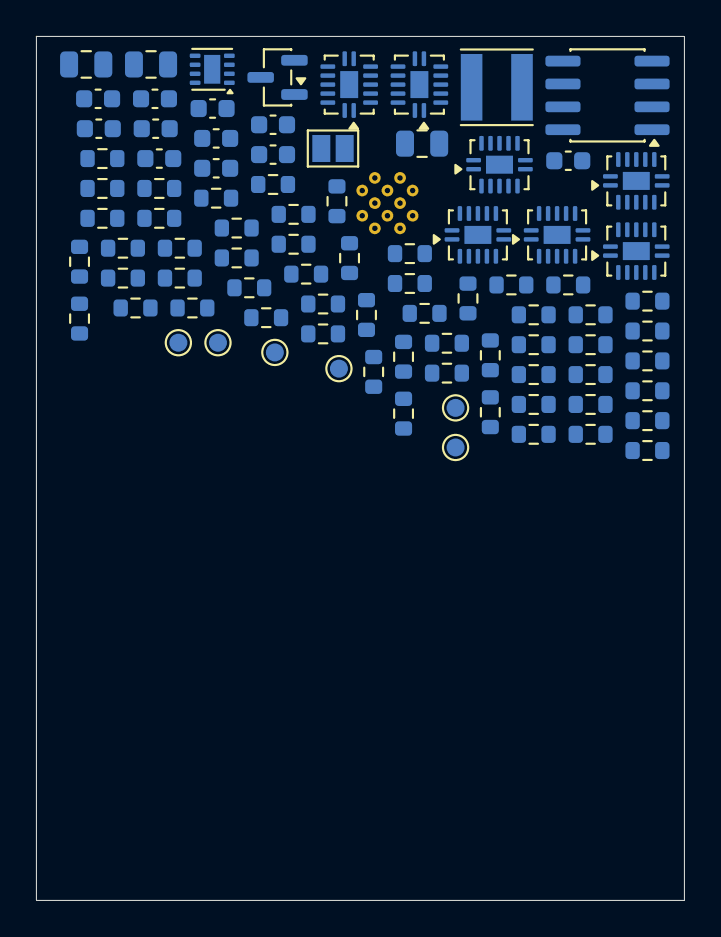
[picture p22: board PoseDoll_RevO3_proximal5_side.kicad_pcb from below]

Board: 4 copper layers, 36.0 x 48.0 mm, 98 parts (88 on the bottom side), 74 nets, no tracks yet.

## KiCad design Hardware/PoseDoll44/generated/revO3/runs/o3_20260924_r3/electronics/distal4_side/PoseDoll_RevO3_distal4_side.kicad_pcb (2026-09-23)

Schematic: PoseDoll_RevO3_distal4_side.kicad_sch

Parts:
C26, C27, C28, C29: 100n X7R; C_0603_1608Metric
C50: 1u X7R; C_0603_1608Metric
J16: P6 sensor / CS GPIO8; JST_SH_BM06B-SRSS-TB_1x06-1MP_P1.00mm_Vertical
J17: P7 sensor / CS GPIO9; JST_SH_BM06B-SRSS-TB_1x06-1MP_P1.00mm_Vertical
J18: P8 sensor / CS GPIO10; JST_SH_BM06B-SRSS-TB_1x06-1MP_P1.00mm_Vertical
J19: P9 sensor / CS GPIO14; JST_SH_BM06B-SRSS-TB_1x06-1MP_P1.00mm_Vertical
J50: SM14B-SRSS-TB / SHR-14V-S / SSH-003T-P0.2-H; JST_SH_SM14B-SRSS-TB_1x14-1MP_P1.00mm_Horizontal
R160, R161, R162, R170, R171, R172, R180, R181, R182, R190, R191, R192: 100R; R_0603_1608Metric
R163, R167, R173, R177, R183, R187, R193, R197: 10k; R_0603_1608Metric
R164, R165, R174, R175, R184, R185, R194, R195: 47k; R_0603_1608Metric
R166, R176, R186, R196: 100k; R_0603_1608Metric
R500: 100R return source damping candidate; R_0603_1608Metric
U16, U17, U18, U19: SN74LVC125ABQAR; DHWQFN-14-1EP_2.5x3mm_P0.5mm_EP1x1.5mm

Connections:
/+3V3: C26.1, C27.1, C28.1, C29.1, C50.1, J16.2, J17.2, J18.2, J19.2, J50.13, J50.14, R163.1, R167.1, R173.1, R177.1, R183.1, R187.1, R193.1, R197.1, U16.14 (VCC), U17.14 (VCC), U18.14 (VCC), U19.14 (VCC)
/CS6_REMOTE: J50.7, R163.2, U16.1 (1OE_N), U16.4 (2OE_N), U16.10 (3OE_N), U16.12 (4A)
/CS7_REMOTE: J50.8, R173.2, U17.1 (1OE_N), U17.4 (2OE_N), U17.10 (3OE_N), U17.12 (4A)
/CS8_REMOTE: J50.10, R183.2, U18.1 (1OE_N), U18.4 (2OE_N), U18.10 (3OE_N), U18.12 (4A)
/CS9_REMOTE: J50.11, R193.2, U19.1 (1OE_N), U19.4 (2OE_N), U19.10 (3OE_N), U19.12 (4A)
/GND: C26.2, C27.2, C28.2, C29.2, C50.2, J16.1, J17.1, J18.1, J19.1, J50.1, J50.3, J50.5, J50.9, J50.12, R164.2, R165.2, R166.2, R174.2, R175.2, R176.2, R184.2, R185.2, R186.2, R194.2, R195.2, R196.2, U16.7 (GND), U16.13 (4OE_N), U16.15 (EP_GND), U17.7 (GND), U17.13 (4OE_N), U17.15 (EP_GND), U18.7 (GND), U18.13 (4OE_N), U18.15 (EP_GND), U19.7 (GND), U19.13 (4OE_N), U19.15 (EP_GND)
/LINK_MISO: J50.6, R500.2
/LINK_MOSI: J50.4, U16.5 (2A), U17.5 (2A), U18.5 (2A), U19.5 (2A)
/LINK_SCK: J50.2, U16.2 (1A), U17.2 (1A), U18.2 (1A), U19.2 (1A)
/MISO_REMOTE_DRV: R500.1, U16.8 (3Y), U17.8 (3Y), U18.8 (3Y), U19.8 (3Y)
/P6_CS: J16.6, R162.2, R167.2
/P6_CS_DRV: R162.1, U16.11 (4Y)
/P6_MISO: J16.5, R166.1, U16.9 (3A)
/P6_MOSI: J16.4, R161.2, R165.1
/P6_MOSI_DRV: R161.1, U16.6 (2Y)
/P6_SCK: J16.3, R160.2, R164.1
/P6_SCK_DRV: R160.1, U16.3 (1Y)
/P7_CS: J17.6, R172.2, R177.2
/P7_CS_DRV: R172.1, U17.11 (4Y)
/P7_MISO: J17.5, R176.1, U17.9 (3A)
/P7_MOSI: J17.4, R171.2, R175.1
/P7_MOSI_DRV: R171.1, U17.6 (2Y)
/P7_SCK: J17.3, R170.2, R174.1
/P7_SCK_DRV: R170.1, U17.3 (1Y)
/P8_CS: J18.6, R182.2, R187.2
/P8_CS_DRV: R182.1, U18.11 (4Y)
/P8_MISO: J18.5, R186.1, U18.9 (3A)
/P8_MOSI: J18.4, R181.2, R185.1
/P8_MOSI_DRV: R181.1, U18.6 (2Y)
/P8_SCK: J18.3, R180.2, R184.1
/P8_SCK_DRV: R180.1, U18.3 (1Y)
/P9_CS: J19.6, R192.2, R197.2
/P9_CS_DRV: R192.1, U19.11 (4Y)
/P9_MISO: J19.5, R196.1, U19.9 (3A)
/P9_MOSI: J19.4, R191.2, R195.1
/P9_MOSI_DRV: R191.1, U19.6 (2Y)
/P9_SCK: J19.3, R190.2, R194.1
/P9_SCK_DRV: R190.1, U19.3 (1Y)

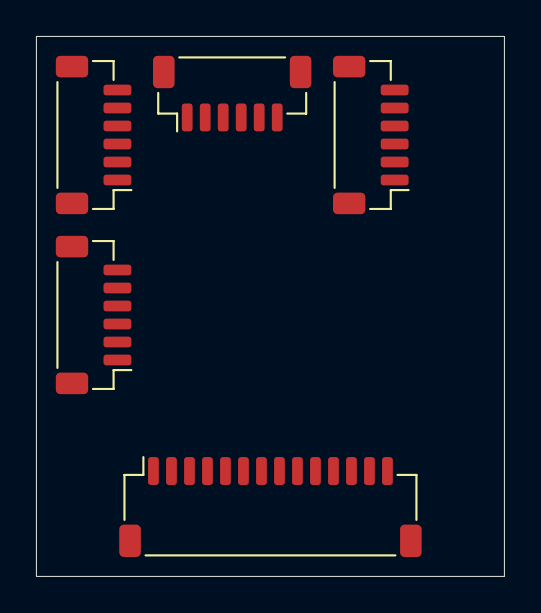
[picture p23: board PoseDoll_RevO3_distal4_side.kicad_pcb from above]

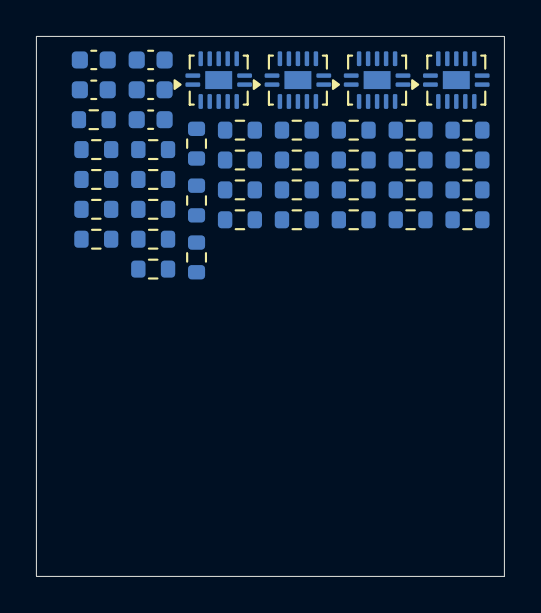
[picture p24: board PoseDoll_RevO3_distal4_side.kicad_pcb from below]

Board: 4 copper layers, 26.0 x 30.0 mm, 47 parts (42 on the bottom side), 38 nets, no tracks yet.

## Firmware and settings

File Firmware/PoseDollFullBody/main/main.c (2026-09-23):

/* Six-node PD41 diagnostic firmware; no calibration, UDP, IMU or OTP writes.
 * ESP-IDF 6.1 esp_twai API. One pending TX buffer; it stays alive until completion.
 * Each acquired cohort starts blank. A missing node cannot reuse older angles.
 */
#include <stdatomic.h>
#include <string.h>
#include "sdkconfig.h"
#include "freertos/FreeRTOS.h"
#include "freertos/task.h"
#include "freertos/queue.h"
#include "freertos/semphr.h"
#include "driver/spi_master.h"
#include "driver/gpio.h"
#include "driver/usb_serial_jtag.h"
#include "esp_twai.h"
#include "esp_twai_onchip.h"
#include "esp_timer.h"
#include "esp_rom_sys.h"
#include "esp_random.h"
#include "esp_mac.h"
#include "esp_err.h"
#include "pd41_core.h"
enum { NODE=CONFIG_PD_NODE_ID, IO_FAIL=1, PARITY_FAIL=2, SENSOR_ERROR=4, MAGNET_FAIL=8, NONZERO_OTP=16 };
enum { CAN_EPOCH=0x080, CAN_SYNC=0x081, CAN_BOOT=0x100, CAN_ACK=0x120, CAN_END=0x180, CAN_PAIR=0x200 };
typedef struct {uint64_t us;uint32_t id;uint8_t bytes[8];} rx_event_t;
static spi_device_handle_t sensor;
static twai_node_handle_t can;
static QueueHandle_t receive_queue;
static SemaphoreHandle_t transmit_done;
static atomic_bool rx_overflow;
static volatile bool tx_success;
static twai_frame_t transmit_frame;
static uint8_t transmit_bytes[8];
static uint64_t boot_id;
static uint64_t clock_us(void){return (uint64_t)esp_timer_get_time();}
static uint64_t random_id(void){uint64_t n=0;while(!n)n=((uint64_t)esp_random()<<32)|esp_random();return n;}
#if CONFIG_PD_NODE_ID == 1
static void sleep_until(uint64_t deadline){while(clock_us()<deadline)vTaskDelay(1);}
#endif
static uint16_t even_parity(uint16_t v){unsigned p=0;for(unsigned i=0;i<15;i++)p^=(v>>i)&1;return v|((uint16_t)p<<15);}
static bool even(uint16_t v){unsigned p=0;for(unsigned i=0;i<16;i++)p^=(v>>i)&1;return p==0;}
static esp_err_t spi_word(unsigned port,uint16_t tx,uint16_t *rx){
    uint8_t a[2]={(uint8_t)(tx>>8),(uint8_t)tx},b[2]={0};
    spi_transaction_t t={.length=16,.tx_buffer=a,.rx_buffer=b};
    gpio_set_level(pd_cs_gpio[port],0);esp_rom_delay_us(1);
    esp_err_t e=spi_device_polling_transmit(sensor,&t);
    esp_rom_delay_us(1);gpio_set_level(pd_cs_gpio[port],1);esp_rom_delay_us(1);
    *rx=((uint16_t)b[0]<<8)|b[1];return e;
}
static uint16_t read_reg(unsigned port,uint16_t addr,uint16_t *value){
    uint16_t dummy=0,r=0,flags=0;
    esp_err_t a=spi_word(port,even_parity(0x4000|addr),&dummy),b=spi_word(port,0,&r);
    if(a!=ESP_OK || b!=ESP_OK)flags|=IO_FAIL;
    if(!even(r))flags|=PARITY_FAIL;
    if(r&0x4000)flags|=SENSOR_ERROR;
    *value=r&0x3fff;return flags;
}
static uint16_t read_axis(unsigned port){
    uint16_t diag=0,mag=0,angle=0,hi=0,lo=0,dummy=0,flags=0;
    flags|=read_reg(port,0x3ffd,&diag);flags|=read_reg(port,0x3ffe,&mag);flags|=read_reg(port,0x3fff,&angle);
    flags|=read_reg(port,0x0016,&hi);flags|=read_reg(port,0x0017,&lo);
    if(!(diag&0x100) || (diag&0xe00))flags|=MAGNET_FAIL;
    if(((hi&255)<<6)|(lo&63))flags|=NONZERO_OTP;
    if(flags&SENSOR_ERROR)(void)read_reg(port,1,&dummy); /* read-to-clear only */
    return flags?(uint16_t)(PD_FAULT|flags):angle;
}
static void spi_setup(void){
    uint64_t mask=0;for(unsigned i=0;i<9;i++)mask|=1ULL<<pd_cs_gpio[i];
    gpio_config_t pins={.pin_bit_mask=mask,.mode=GPIO_MODE_OUTPUT};ESP_ERROR_CHECK(gpio_config(&pins));
    for(unsigned i=0;i<9;i++)gpio_set_level(pd_cs_gpio[i],1);
    spi_bus_config_t bus={.mosi_io_num=11,.miso_io_num=13,.sclk_io_num=12,.quadwp_io_num=-1,.quadhd_io_num=-1,.max_transfer_sz=2};
    ESP_ERROR_CHECK(spi_bus_initialize(SPI2_HOST,&bus,SPI_DMA_DISABLED));
    spi_device_interface_config_t device={.clock_speed_hz=250000,.mode=1,.spics_io_num=-1,.queue_size=1};
    ESP_ERROR_CHECK(spi_bus_add_device(SPI2_HOST,&device,&sensor));
    ESP_ERROR_CHECK(gpio_set_pull_mode(GPIO_NUM_13,GPIO_PULLUP_ONLY));
}
static bool on_rx(twai_node_handle_t handle,const twai_rx_done_event_data_t *edata,void *context){
    (void)edata;(void)context;rx_event_t e={.us=clock_us()};twai_frame_t f={.buffer=e.bytes,.buffer_len=8};BaseType_t woken=pdFALSE;
    if(twai_node_receive_from_isr(handle,&f)==ESP_OK && !f.header.ide && !f.header.rtr && !f.header.fdf && f.header.dlc==8){
        e.id=f.header.id;if(xQueueSendFromISR(receive_queue,&e,&woken)!=pdTRUE)atomic_store(&rx_overflow,true);
    }
    return woken==pdTRUE;
}
static bool on_tx(twai_node_handle_t handle,const twai_tx_done_event_data_t *edata,void *context){
    (void)handle;(void)context;BaseType_t woken=pdFALSE;tx_success=edata->is_tx_success;xSemaphoreGiveFromISR(transmit_done,&woken);return woken==pdTRUE;
}
static void can_setup(void){
    twai_onchip_node_config_t c={.io_cfg={.tx=17,.rx=18,.quanta_clk_out=-1,.bus_off_indicator=-1},.bit_timing={.bitrate=500000},.fail_retry_cnt=0,.tx_queue_depth=1,.intr_priority=2,.flags={.no_receive_rtr=1}};
    ESP_ERROR_CHECK(twai_new_node_onchip(&c,&can));twai_event_callbacks_t callbacks={.on_rx_done=on_rx,.on_tx_done=on_tx};
    ESP_ERROR_CHECK(twai_node_register_event_callbacks(can,&callbacks,NULL));ESP_ERROR_CHECK(twai_node_enable(can));
}
static void can_reset(void){
    twai_node_status_t status;ESP_ERROR_CHECK(twai_node_get_info(can,&status,NULL));
    if(status.state!=TWAI_ERROR_BUS_OFF)ESP_ERROR_CHECK(twai_node_disable(can));
    ESP_ERROR_CHECK(twai_node_delete(can)); /* driver releases queued frame pointers before global buffer reuse */
    xQueueReset(receive_queue);while(xSemaphoreTake(transmit_done,0)==pdTRUE){}
    atomic_store(&rx_overflow,false);can_setup();
}
static bool send8(uint32_t id,const uint8_t *data){
    while(xSemaphoreTake(transmit_done,0)==pdTRUE){}
    memcpy(transmit_bytes,data,8);transmit_frame=(twai_frame_t){.header={.id=id,.dlc=8},.buffer=transmit_bytes,.buffer_len=8};tx_success=false;
    if(twai_node_transmit(can,&transmit_frame,0)!=ESP_OK)return false;
    /* The next call is forbidden after failure until can_reset destroys old TX references. */
    if(xSemaphoreTake(transmit_done,pdMS_TO_TICKS(4))!=pdTRUE || !tx_success)return false;
    return twai_node_transmit_wait_all_done(can,4)==ESP_OK;
}
static bool send64(uint32_t id,uint64_t value){uint8_t p[8];pd_put64(p,value);return send8(id,p);}
static bool acquire(uint64_t sync_us,uint16_t words[9],uint16_t *delay,uint16_t *span){
    uint64_t start=clock_us();for(unsigned i=0;i<pd_port_count[NODE-1];i++)words[i]=read_axis(i);uint64_t end=clock_us();
    if(start<sync_us || end-sync_us>PD_NODE_WINDOW_US || end==start)return false;
    *delay=(uint16_t)(start-sync_us);*span=(uint16_t)(end-start);return true;
}
#if CONFIG_PD_NODE_ID == 1
static void gateway_event(pd_cohort_t *cohort,const rx_event_t *e){
    if(e->id>=CAN_BOOT+2 && e->id<=CAN_BOOT+6){(void)pd_boot(cohort,e->id-CAN_BOOT,pd_get64(e->bytes));return;}
    if(e->id>=CAN_ACK+2 && e->id<=CAN_ACK+6){unsigned n=e->id-CAN_ACK;(void)pd_ack(cohort,n,pd_get64(e->bytes),cohort->node[n-1].boot);return;}
    if(e->id>=CAN_END+2 && e->id<=CAN_END+6){(void)pd_end(cohort,e->id-CAN_END,pd_get32(e->bytes),pd_get16(e->bytes+4),pd_get16(e->bytes+6),e->us);return;}
    if(e->id>=CAN_PAIR+2*16 && e->id<CAN_PAIR+7*16){unsigned x=e->id-CAN_PAIR;(void)pd_pair(cohort,x/16,pd_get32(e->bytes),x%16,pd_get16(e->bytes+4),pd_get16(e->bytes+6),e->us);}
}
static void gateway(void){
    uint8_t mac[6];ESP_ERROR_CHECK(esp_efuse_mac_get_default(mac));uint64_t device=0;for(unsigned i=0;i<6;i++)device=(device<<8)|mac[i];
    pd_cohort_t cohort;pd_init(&cohort,random_id());(void)pd_boot(&cohort,1,boot_id);(void)pd_ack(&cohort,1,cohort.epoch,boot_id);
    uint64_t serial_seq=0,next=clock_us(),last_announce=0;rx_event_t e;
    for(;;){
        sleep_until(next);next+=16667;
        while(xQueueReceive(receive_queue,&e,0)==pdTRUE)gateway_event(&cohort,&e); /* only controls affect inactive cohort */
        if(atomic_exchange(&rx_overflow,false) || cohort.sequence==UINT32_MAX){
            can_reset();pd_init(&cohort,random_id());(void)pd_boot(&cohort,1,boot_id);(void)pd_ack(&cohort,1,cohort.epoch,boot_id);last_announce=0;
        }
        bool ok=true;
        if(!last_announce || clock_us()-last_announce>=100000){ok=send64(CAN_EPOCH,cohort.epoch);last_announce=clock_us();}
        uint64_t start=clock_us();uint32_t seq=cohort.sequence+1;uint8_t sync[8];pd_put32(sync,seq);pd_put32(sync+4,(uint32_t)start);
        if(ok){ok=pd_begin(&cohort,seq,start);if(ok)ok=send8(CAN_SYNC,sync);}
        if(!ok){
            can_reset();pd_init(&cohort,random_id());(void)pd_boot(&cohort,1,boot_id);(void)pd_ack(&cohort,1,cohort.epoch,boot_id);last_announce=0;
            /* N1 alone still emits an explicit missing full-body diagnostic below. */
            start=clock_us();(void)pd_begin(&cohort,1,start);
        }else{
            uint16_t words[9],delay=0,span=0;
            if(acquire(start,words,&delay,&span)){
                for(unsigned g=0;g<2;g++)(void)pd_pair(&cohort,1,seq,g,words[2*g],g==1?PD_FIXED:words[2*g+1],clock_us());
                (void)pd_end(&cohort,1,seq,delay,span,clock_us());
            }
        }
        while(clock_us()<start+PD_DEADLINE_US){
            if(xQueueReceive(receive_queue,&e,1)==pdTRUE)gateway_event(&cohort,&e);
            if(atomic_load(&rx_overflow))for(unsigned i=0;i<6;i++)cohort.node[i].bad=true;
        }
        while(xQueueReceive(receive_queue,&e,0)==pdTRUE)gateway_event(&cohort,&e);
        pd_sample_t sample;if(pd_finish(&cohort,clock_us(),&sample)){
            uint8_t wire[PD_WIRE_MAX];size_t count=pd_encode(&sample,device,boot_id,++serial_seq,wire,sizeof(wire));
            if(count && usb_serial_jtag_is_connected()){
                int sent=usb_serial_jtag_write_bytes(wire,count,0);
                if(sent!=(int)count){uint8_t zero=0;(void)usb_serial_jtag_write_bytes(&zero,1,0);}
            }
        }
        if(clock_us()>next+16667)next=clock_us()+16667;
    }
}
#else
static void regional(void){
    uint64_t epoch=0,last_boot=0;uint32_t last_seq=0;rx_event_t e;
    for(;;){
        bool ok=true;
        if(atomic_exchange(&rx_overflow,false)){can_reset();epoch=0;last_seq=0;last_boot=0;}
        if(!last_boot || clock_us()-last_boot>=250000){ok=send64(CAN_BOOT+NODE,boot_id);last_boot=clock_us();}
        if(!ok){can_reset();epoch=0;last_seq=0;vTaskDelay(pdMS_TO_TICKS(20));continue;}
        if(xQueueReceive(receive_queue,&e,pdMS_TO_TICKS(2))!=pdTRUE)continue;
        if(e.id==CAN_EPOCH){
            uint64_t next_epoch=pd_get64(e.bytes);if(!next_epoch)continue;
            if(next_epoch!=epoch){
                /* Every send above has completed. Reset discards old RX, TX and SYNC frames
                   before any new-epoch ACK; the gateway ignores data until this ACK. */
                can_reset();epoch=next_epoch;last_seq=0;
            }
            ok=send64(CAN_BOOT+NODE,boot_id);if(ok)ok=send64(CAN_ACK+NODE,epoch);
        }else if(e.id==CAN_SYNC && epoch){
            uint32_t seq=pd_get32(e.bytes);if(!seq || seq<=last_seq)continue;last_seq=seq;
            uint16_t words[9],delay=0,span=0;
            if(!acquire(e.us,words,&delay,&span))continue;
            unsigned count=pd_port_count[NODE-1];uint8_t data[8];pd_put32(data,seq);
            for(unsigned g=0;g<(count+1)/2 && ok;g++){
                pd_put16(data+4,words[2*g]);pd_put16(data+6,2*g+1<count?words[2*g+1]:PD_FIXED);
                ok=send8(CAN_PAIR+NODE*16+g,data);
            }
            if(ok && !atomic_load(&rx_overflow)){pd_put16(data+4,delay);pd_put16(data+6,span);ok=send8(CAN_END+NODE,data);}
        }
        if(!ok){can_reset();epoch=0;last_seq=0;last_boot=0;vTaskDelay(pdMS_TO_TICKS(20));}
    }
}
#endif
void app_main(void){
    boot_id=random_id();receive_queue=xQueueCreate(64,sizeof(rx_event_t));transmit_done=xSemaphoreCreateBinary();configASSERT(receive_queue && transmit_done);
    spi_setup();can_setup();
#if CONFIG_PD_NODE_ID == 1
    usb_serial_jtag_driver_config_t usb={.tx_buffer_size=1024,.rx_buffer_size=128};ESP_ERROR_CHECK(usb_serial_jtag_driver_install(&usb));gateway();
#else
    regional();
#endif
}

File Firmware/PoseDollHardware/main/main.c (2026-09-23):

/* H1 diagnostic firmware: one REAL AS5048A, no fabricated full-body samples.
 * AS5048 DS000298 v1-11: mode 1, delayed response, even parity, OCF/COF/COMP.
 * Pins: DevKitC-1 N8, SPI SCK12 MOSI11 MISO13 CS10. USB19/20 untouched.
 */
#include <stdint.h>
#include <string.h>
#include "freertos/FreeRTOS.h"
#include "freertos/task.h"
#include "driver/spi_master.h"
#include "driver/gpio.h"
#include "driver/usb_serial_jtag.h"
#include "esp_timer.h"
#include "esp_rom_sys.h"
#include "esp_random.h"
#include "esp_mac.h"
#include "esp_err.h"
static spi_device_handle_t sensor;
enum { IO_FAIL=1, PARITY_FAIL=2, SENSOR_ERROR=4, MAGNET_FAIL=8, NONZERO_OTP=16 };
static uint16_t parity(uint16_t v) { unsigned p=0;for(unsigned i=0;i<15;i++)p^=(v>>i)&1;return v|((uint16_t)p<<15); }
static int even(uint16_t v) { unsigned p=0;for(unsigned i=0;i<16;i++)p^=(v>>i)&1;return p==0; }
static esp_err_t word(uint16_t tx,uint16_t *rx) {
    uint8_t a[2]={(uint8_t)(tx>>8),(uint8_t)tx},b[2]={0};
    spi_transaction_t t={.length=16,.tx_buffer=a,.rx_buffer=b};
    gpio_set_level(GPIO_NUM_10,0);esp_rom_delay_us(1);
    esp_err_t e=spi_device_polling_transmit(sensor,&t);
    esp_rom_delay_us(1);gpio_set_level(GPIO_NUM_10,1);esp_rom_delay_us(1);
    *rx=((uint16_t)b[0]<<8)|b[1];return e;
}
static uint16_t read_reg(uint16_t addr,uint16_t *value) {
    uint16_t dummy=0,r=0,flags=0;
    esp_err_t a=word(parity(0x4000|addr),&dummy);
    esp_err_t b=word(0,&r);
    if(a!=ESP_OK || b!=ESP_OK)flags|=IO_FAIL;
    if(!even(r))flags|=PARITY_FAIL;
    if(r&0x4000)flags|=SENSOR_ERROR;
    *value=r&0x3fff;return flags;
}
static void put16(uint8_t *p,uint16_t v){p[0]=v;p[1]=v>>8;}
static void put32(uint8_t *p,uint32_t v){for(unsigned i=0;i<4;i++)p[i]=v>>(8*i);}
static void put64(uint8_t *p,uint64_t v){for(unsigned i=0;i<8;i++)p[i]=v>>(8*i);}
static uint32_t crc32(const uint8_t *p,unsigned n) {
    uint32_t c=0xffffffff;
    while(n--){c^=*p++;for(unsigned j=0;j<8;j++)c=(c>>1)^((c&1)?0xedb88320:0);}
    return c^0xffffffff;
}
static unsigned cobs(const uint8_t *p,unsigned n,uint8_t *out) {
    unsigned codeidx=0,k=1;uint8_t code=1;
    for(unsigned i=0;i<n;i++){
        if(p[i]==0){out[codeidx]=code;codeidx=k++;code=1;}
        else {out[k++]=p[i];if(++code==255){out[codeidx]=code;codeidx=k++;code=1;}}
    }
    out[codeidx]=code;out[k++]=0;return k;
}
void app_main(void) {
    gpio_config_t gp={.pin_bit_mask=1ULL<<10,.mode=GPIO_MODE_OUTPUT};ESP_ERROR_CHECK(gpio_config(&gp));gpio_set_level(GPIO_NUM_10,1);
    spi_bus_config_t bus={.mosi_io_num=11,.miso_io_num=13,.sclk_io_num=12,.quadwp_io_num=-1,.quadhd_io_num=-1,.max_transfer_sz=2};
    ESP_ERROR_CHECK(spi_bus_initialize(SPI2_HOST,&bus,SPI_DMA_DISABLED));
    spi_device_interface_config_t device={.clock_speed_hz=250000,.mode=1,.spics_io_num=-1,.queue_size=1};
    ESP_ERROR_CHECK(spi_bus_add_device(SPI2_HOST,&device,&sensor));
    usb_serial_jtag_driver_config_t usb={.tx_buffer_size=128,.rx_buffer_size=128};
    ESP_ERROR_CHECK(usb_serial_jtag_driver_install(&usb));
    uint8_t mac[6];ESP_ERROR_CHECK(esp_efuse_mac_get_default(mac));uint64_t id=0;
    for(unsigned i=0;i<6;i++)id=(id<<8)|mac[i];
    uint64_t boot=((uint64_t)esp_random()<<32)|esp_random(),seq=0;
    vTaskDelay(pdMS_TO_TICKS(20));TickType_t tick=xTaskGetTickCount();
    for(;;){
        uint64_t us=esp_timer_get_time();uint16_t angle=0,diag=0,mag=0,hi=0,lo=0,flags=0,dummy=0;
        flags|=read_reg(0x3ffd,&diag);
        flags|=read_reg(0x3ffe,&mag);
        flags|=read_reg(0x3fff,&angle);
        flags|=read_reg(0x0016,&hi);flags|=read_reg(0x0017,&lo);
        uint16_t zero=((hi&255)<<6)|(lo&63);
        if(!(diag&0x100) || (diag&0xe00))flags|=MAGNET_FAIL;
        if(zero)flags|=NONZERO_OTP; /* report, never silently compensate */
        uint32_t window=(uint32_t)(esp_timer_get_time()-us);
        if(flags&SENSOR_ERROR)(void)read_reg(1,&dummy); /* read-to-clear only; no write/OTP commands */
        uint8_t p[60]={0},wire[64];
        memcpy(p,"PDH1",4);p[4]=1;p[5]=1;put16(p+6,56);
        put64(p+8,id);put64(p+16,boot);put64(p+24,++seq);put64(p+32,us);
        put32(p+40,window);put16(p+44,17);put16(p+46,flags?0:angle);
        put16(p+48,diag);put16(p+50,mag);put16(p+52,zero);put16(p+54,flags);
        put32(p+56,crc32(p,56));unsigned size=cobs(p,60,wire);
        if(usb_serial_jtag_is_connected()) {
            int n=usb_serial_jtag_write_bytes(wire,size,0);
            if(n!=(int)size){uint8_t delimiter=0;(void)usb_serial_jtag_write_bytes(&delimiter,1,0);}
        }
        xTaskDelayUntil(&tick,pdMS_TO_TICKS(10));
    }
}

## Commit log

2026-09-23 Initialize standalone PoseDoll hardware design repository
    [PoseDoll_AS5048A_revA.kicad_pcb, PoseDoll_AS5048A_revA.kicad_sch, PoseDoll_AS5048A_revB.kicad_pcb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]
2026-09-23 design: checkpoint Rev O desktop iteration for review
    Preserve the 91 cm Rev N1 fallback and introduce an independent desktop
    study with fixed-size joint CAD, native node/G0 PCB placement, size/load
    budgets, and seven-role firmware without changing PD41 axis semantics.
    Record failed board fit, joint insertion/service space, mass and PCB DRC
    gates alongside unrun full-body and physical checks. Include the GPT-6 Pro
    review brief, selected STEP/STL assets, lightweight viewer, and raw logs.
    Validation: 81 baseline plus 13 Rev O Python tests, 9 baseline C scenarios,
    G0 fault/serialization tests, 7 firmware builds, and 5 error-level ERC checks.
    All 5,748 fallback files unchanged. Viewer also pas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
    [A01_journal_fit_coupon.step, A01_journal_fit_coupon.stl, A02_board_edge_coupon.step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]
2026-09-23 design: checkpoint Rev O2 assembly and split-board review
    Implement the Rev O iteration-2 review with a radially assembled L6 bearing
    cartridge, independent axial datum and floating two-face brake, native
    proximal/distal board candidates, revised mass/contact studies, and
    addressed CAN join handling without repeated-EPOCH reply storms.
    Include the immutable o2_20260923_r1 CAD/KiCad/viewer snapshot, raw evidence,
    source/artifact hashes, and a GPT-6 Pro review entry. Preserve the 91 cm
    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
    [L6_R2_assembly.step, PoseDoll_RevO2_distal4.kicad_pcb, PoseDoll_RevO2_distal4.kicad_sch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]
2026-09-23 design: checkpoint Rev O3 and request static-capture review
    Integrate sensor supports with the split bearing housing, replace wear-plane
    pins with keyed backing rings, and correct the sampled assembly sequence.
    Record 52 scoped lifecycle states, reconciled mass/contact calculations,
    five native PCB candidates, per-node recovery backoff, and timing semantics.
    Preserve the complete r1 firmware provenance, r2 assembly failure evidence,
    and current r3 artifacts, including STEP, native boards, viewer, logs and
    portable host test outputs. Verify 484 current source hashes and delivery
    files against the Git index. Original tool logs retain their sealed bytes.
    Validation: 141 Python tests; C core/s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
    [J11_bend_R12.step, J11_bend_R4.step, J11_catalog_mating.step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]
